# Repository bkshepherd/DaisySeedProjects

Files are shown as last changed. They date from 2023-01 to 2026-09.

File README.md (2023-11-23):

# Daisy Seed Projects
This is a demo of a pedal board I put together using 3 of my custom Daisy Seed based guitar pedals. I designed and built the hardware and programmed the software. Everything shown here is open source and all the code, pcb files, and basic instructions on how to build the pedals, can be found on these pages.

Demo Video (https://www.youtube.com/watch?v=ZkLnS43acQo)

## Software Projects:
### 1. [Guitar Multi-Effect Pedal](Software/GuitarPedal/README.md)
The software that can run on any of the custom Guitar Pedal hardware projects listed below as well at the PedalPCB Terrarium hardware.  This software is a flexible platform that abstracts the underlying Guitar Pedal hardware and allows a collection of Effects Modules to run on any of those hardware platforms.

## Hardware Projects:

I provide everything you need to build any of pedals you see below along with pretty detailed documentation.  However, recently I started to get a lot of requests to buy kits or finished pedals based on my designs. This is not something I typically do, but sometimes I do have extra PCBs, parts, and enclosures lying around and I'm willing to pass them along to you, basically at cost. I've included some ordering details along with each design below.

### 1. [Guitar Effect Pedal in 125b Enclosure](Hardware/GuitarPedal125b/README.md) (SMD Parts)
A feature rich and flexible platform for making DSP based guitar FX pedals. Stereo Audio, Midi in/out, OLED Display, Rotary Encoder for Menu Navigation, 6 Knobs, 2 LEDs, 2 Foot Switches, Relay based "True Bypass" switching, all based on the Daisy Seed microcontroller.

[Ordering Information](Hardware/GuitarPedal125b/docs/OrderingHardware.md)

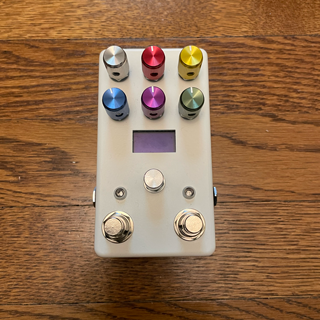
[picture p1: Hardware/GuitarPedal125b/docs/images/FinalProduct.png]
FinalProduct125b
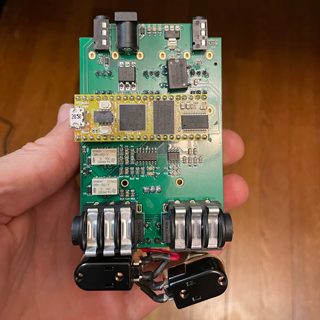
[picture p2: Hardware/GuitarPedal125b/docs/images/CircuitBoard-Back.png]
CircuitBoard125b
 

### 2. [Guitar Effect Pedal in 1590b Enclosure](Hardware/GuitarPedal1590b-SMD/README.md) (SMD Parts)

A robust and tiny platform for making DSP based guitar FX pedals. Stereo Audio, Midi in/out, 4 Knobs, 2 LEDs, 1 or 2 Foot Switches, Relay based "True Bypass" switching, all based on the Daisy Seed microcontroller. Using SMD parts for easy manufacturing by a fab such as JLCPCB.

[Ordering Information](Hardware/GuitarPedal1590b-SMD/docs/OrderingHardware.md)

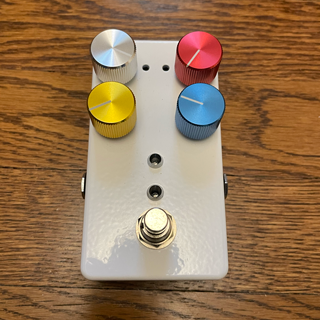
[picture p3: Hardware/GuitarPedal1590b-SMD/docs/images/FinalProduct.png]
FinalProduct1590b-SMD
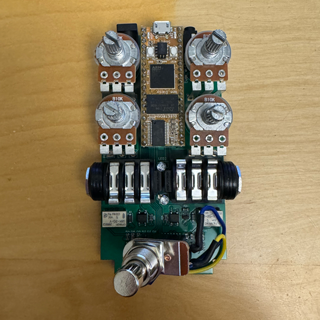
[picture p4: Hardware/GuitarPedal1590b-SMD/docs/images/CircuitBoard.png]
CircuitBoard1590b-SMD
 

### 3. [Guitar Effect Pedal in 1590b Enclosure](Hardware/GuitarPedal1590b/README.md) (Through-hole parts)

Same form factor and features as the SMD version of the 1590b pedal, minus the Relay based "True Bypass" switching. Using all Through-Hole parts for easy assembly at home with limited soldering skills.

[Ordering Information](Hardware/GuitarPedal1590b/docs/OrderingHardware.md)

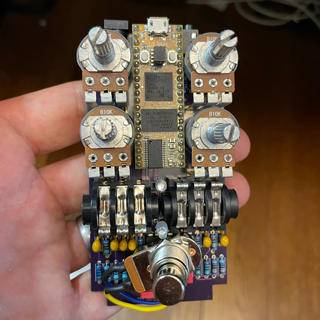
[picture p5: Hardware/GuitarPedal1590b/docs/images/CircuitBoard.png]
CircuitBoard1590b
FinalProduct1590b 

More Information about the Daisy Seed can be found at:

http://electro-smith.com

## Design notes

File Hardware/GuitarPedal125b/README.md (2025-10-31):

# Guitar Pedal 125b

### Rev 6 - 3/17/2024

Updates include:
1. Removed the PDS1 DC-DC Isolator from the power supply design.  This part was quite expensive and hard to source and wasn't really doing anything valuable to help with the noise profile of the device (especially if you are using a good pedal board power source with isolated power).  This simplifies the power supply a bit.  
2. Added a simple RC Low Pass filter immediately following the Daisy Seed audio outputs to help get rid of out of band noise caused by the Rev7 Daisy Seed.
3. Updated a bunch of components to have footprints oriented the way JLCPCB expects them.  This reduces the need to "fix" the rotation of components when having JCLPCB manufacture the PCBs.
4. Updated the design to include the 20pin headers for the Daisy Seed so that JLCPCB could also assemble these parts.  Saves a lot of time from having to solder 40 points on the PCB.
5. Updated the design to use more commonly available and cheaper Alpha brand 9mm Pots.
6. Included exported Gerber and Assembly files to make it easy to order assembled PCBs from JCLPCB. Detailed instructions can be found on the [Build the Hardware](docs/README.md) page. This requires no knowledge of KiCad to get the PCBs made and mostly Assembled.

### Overview

A project to create a digital effect pedal based on the Electro-Smith Daisy Seed that fits into a standard 125B sized Guitar Pedal enclosure. The video below shows a pedal board I made using 2 of these 125b sided pedals and demo the capabilities.

Demo Video (https://www.youtube.com/watch?v=ZkLnS43acQo)

This project is an evolution of my [1590B sized Pedal](https://github.com/bkshepherd/DaisySeedProjects/tree/main/Hardware/GuitarPedal1590b).

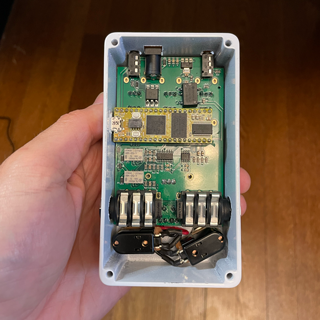
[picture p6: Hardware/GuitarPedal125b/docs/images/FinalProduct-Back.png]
FinalProductBack
FinalProduct 
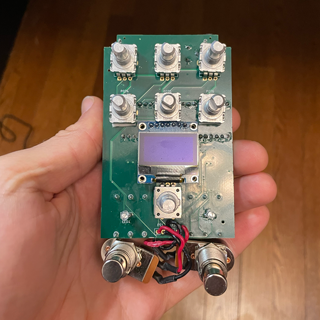
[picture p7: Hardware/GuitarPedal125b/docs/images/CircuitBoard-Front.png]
CircuitBoard
 CircuitBoard
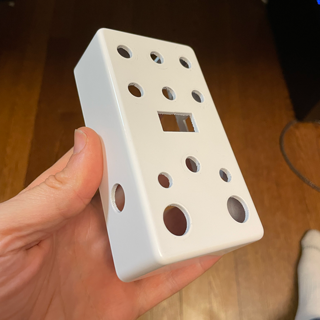
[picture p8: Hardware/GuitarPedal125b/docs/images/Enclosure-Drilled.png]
Enclosure
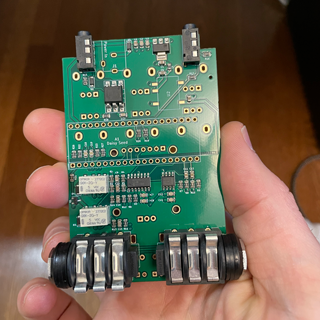
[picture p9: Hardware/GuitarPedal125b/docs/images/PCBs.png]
PCBs
 

### Features

1. 125B size pedal board friendly enclosure!
2. Buffered Stereo Input and Outputs for Guitar Level signals
2. Relay based "True Bypass" switching
3. TRS Mini MIDI Input and Outputs
4. OLED Display
5. Rotary Encoder for Display Navigation
6. 6 Pots
7. Up to 2 Footswitches
8. Up to 2 Leds
9. Standard 9v center pin negative power jack
10. Easy access to the Daisy Seed USB port and reset buttons for updating the firmware
11. Primarily SMD parts for easy assembly by your PCB provider
12. Easily order a custom drilled enclosure from Tayda! [Template Here](https://drill.taydakits.com/box-designs/new?public_key=MlRHaUhqaEVXOVVFZ1ErV1FiTXlrQT09Cg==)
13. Easily order or 3D print the enclosure using provided STEP and FreeCAD files.

This project includes a KiCad project with the necessary schematics and PCB layout files to create everything you need to build the hardware. The included exported Gerber and Assembly files make it easy to order PCBs from JCLPCB. Detailed instructions can be found on the [Build the Hardware](docs/README.md) page. This requires no knowledge of KiCad to get the PCBs made.

Once you've built the hardware you can deploy the software from my Multi-Effect Guitar Pedal software project by following these directions: [Deploy the Software to the Hardware](../../Software/GuitarPedal/README.md)

This software provides a hardware abstraction layer as well as a few custom FX including Tremolo, Chorus, Overdrive, and Stereo Auto-Pan.

## Past Updates
### Rev 5 - 6/30/2023

Updates include:
1. Updated placement of screen slightly to ease installation.
2. Updated POT footprint mounting holes to be slightly larger.
3. Properly grounded Audio TRS jacks when no cable is inserted.
4. Included exported Gerber and Assembly files to make it easy to order assembled PCBs from JCLPCB. Detailed instructions can be found on the [Build the Hardware](docs/README.md) page. This requires no knowledge of KiCad to get the PCBs made and mostly Assembled.

### Rev 4 - 5/16/2023

Updates include:
1. Updated PCB design to improve the True Bypass relay switching to include an anti-pop hardware mute.
2. Update Example Software to take advantage of the anti-pop mute.
3. Update Example Software to provide a basic menu system for the OLED Screen

### Rev 3 - 4/14/2023

Updates include:
1. Swapped the placement of the Footswitches and LEDs on the PCB to be consistent with my other pedals.

Known Issues:
1. Relay bypass has an audible pop when enabling / disabling the effect. Sounds like a common issue with relay and 3pdt switch true bypass systems.  Investigating fixing / minimizing it with an a solution similar to this [anti-pop system](https://www.coda-effects.com/2016/08/relay-bypass-with-anti-pop-system.html). Hope to add this in Rev 4.

### Rev 2 - 3/29/2023

Updates include:
1. Added 3 Additional Pots (Total of 6)
2. Improved OLED Screen Placement
3. Removed an Encoder (now just 1)
4. Tayda Custom Drill Template for easily ordering a pre-drilled enclosure

More Information about the Daisy Seed can be found at:

http://electro-smith.com

More Information about KiCad can be found at:

https://www.kicad.org

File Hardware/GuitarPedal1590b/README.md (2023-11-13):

# Guitar Pedal 1590b - Through-Hole Parts

### Rev 6 - 11/12/2023

Updates include:
1. Updated the PCB to have an optional bypass of the PDS1 5v Isolation circuit.

### Overview

A project to create a digital effect pedal based on the Electro-Smith Daisy Seed that fits into a standard 1590B sized Guitar Pedal enclosure. Electro-Smith sells a guitar pedal, but it's a much larger format, and I wanted something as small as possible.  The PedalPCB Terrarium was another option, but it's mono only, so I decided to build my own. This one is a smaller form factor than both, operates in Mono or Stereo, and has Midi support, so it's capable little pedal platform.

The video below shows a pedal board I made using this design, the smaller pedal on the far left, along with 2 of my [125B sized pedals](../GuitarPedal125b/README.md).

Demo Video (https://www.youtube.com/watch?v=ZkLnS43acQo)

This project is the Through-Hole parts version of my 1590b pedal. All parts are through-hole components and can easily be hand soldered. There is also a version of this same pedal where all parts are SMD parts that can be assembled by a fab such as JLCPCB, if you are looking for that, please check out my [Guitar Pedal 1590b-SMD project](../GuitarPedal1590b-SMD/README.md).

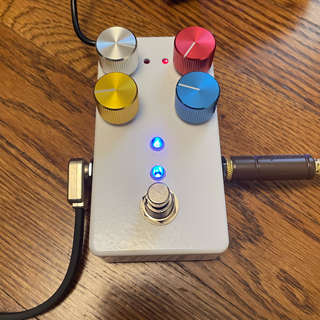
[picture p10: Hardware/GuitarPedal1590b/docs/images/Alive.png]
Backside
FinalProduct 

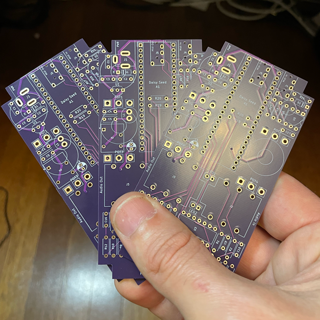
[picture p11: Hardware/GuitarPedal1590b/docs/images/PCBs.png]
PCBs
CircuitBoard 

### Features

1. Small 1590B pedal board friendly enclosure!
2. Buffered Stereo Input and Outputs for Guitar Level signals
3. TRS Mini MIDI Input and Outputs
4. 4 Pots
5. Up to 2 Foot Switches
6. Up to 2 Leds
7. Standard 9v center pin negative power jack
8. Easily Assembled from easily sourced through-hole parts, no SMD soldering required!
9. Easily order a custom drilled enclosure from Tayda!

This project includes a KiCad project with the necessary schematics and PCB layout files to create everything you need to build the hardware. The included exported Gerber and Assembly files make it easy to order PCBs from JCLPCB. Detailed instructions can be found on the [Build the Hardware](docs/README.md) page. This requires no knowledge of KiCad to get the PCBs made.

Once you've built the hardware you can deploy the software from my Multi-Effect Guitar Pedal software project by following these directions: [Deploy the Software to the Hardware](../../Software/GuitarPedal/README.md)

This software provides a hardware abstraction layer as well as a few custom FX including Tremolo, Chorus, Overdrive, and Stereo Auto-Pan.

## Past Revisions
### Rev 5 - 6/3/2023

Updates include:
1. Updated PCB to properly ground input / output jacks when no plug is inserted
2. Fixed a software issue causing noise from the LED.
3. Included exported Gerber files to make it easy to order PCBs from JCLPCB. Detailed instructions can be found on the [Build the Hardware](docs/README.md) page. This requires no knowledge of KiCad to get the PCBs made.
   
### Rev 4 - 4/12/2023

Updates include:
1. Updated PCB layout to move some components farther away from the edges
2. Swapped the placement of Footswitches and LEDs for consistency with my other projects 
3. Updated code to make Footswitch 1 & Led 1 enable / disabe the effect

### Rev 3 - 3/29/2023

Updates include:
1. Improved 4 Layer PCB Layout, much easier to assemble!
2. Replaced all SMD parts with through-hole alternative
3. Tayda Custom Drill Template for easily ordering a pre-drilled enclosure

More Information about the Daisy Seed can be found at:

http://electro-smith.com

More Information about KiCad can be found at:

https://www.kicad.org

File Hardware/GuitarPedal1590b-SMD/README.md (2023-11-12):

# Guitar Pedal 1590b using SMD Parts

### Rev 2 - 11/3/2023

Updates include:
1. Updated PCB to include the hardware mute
2. Included exported Gerber files to make it easy to order PCBs from JCLPCB. Detailed instructions can be found on the [Build the Hardware](docs/README.md) page. This requires no knowledge of KiCad to get the PCBs made.

### Overview

A project to create a digital effect pedal based on the Electro-Smith Daisy Seed that fits into a standard 1590B sized Guitar Pedal enclosure. The video below shows a pedal board I made using this design, the smaller pedal on the far left, along with 2 of my [125B pedals](../GuitarPedal125b/README.md).

Demo Video (https://www.youtube.com/watch?v=ZkLnS43acQo)

This project is the SMD parts version of my [1590b pedal](../GuitarPedal1590b/README.md). Features are the same as the Through-Hole version with the addition of "True Bypass". The majority of all parts can be pre-assembled on the PCB by a fab like JLCPCB. If you'd prefer a design where all parts are through-hole components, please check out the through-hole version of this project [Guitar Pedal 1590 project](../GuitarPedal1590b/README.md).

FinalProduct Backside

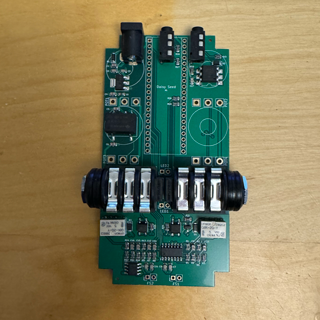
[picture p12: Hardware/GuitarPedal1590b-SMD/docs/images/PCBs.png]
PCBs
CircuitBoard 

### Features

1. Small 1590B pedal board friendly enclosure!
2. Buffered Stereo Input and Outputs for Guitar Level signals
3. TRS Mini MIDI Input and Outputs
4. 4 Pots
5. Up to 2 Foot Switches
6. Up to 2 Leds
7. Standard 9v center pin negative power jack
8. Setup for Easy Manufacturing with JLCPCB.  Minimal soldering required!
9. Easily order a custom drilled enclosure from [Tayda](https://drill.taydakits.com/box-designs/new?public_key=YWRhVFFGU0Z2c3RJR09VQ1U4S3EvUT09Cg==)

This project includes a KiCad project with the necessary schematics and PCB layout files to create everything you need to build the hardware. The included exported Gerber and Assembly files make it easy to order PCBs from JCLPCB. Detailed instructions can be found on the [Build the Hardware](docs/README.md) page. This requires no knowledge of KiCad to get the PCBs made.

Once you've built the hardware you can deploy the software from my Multi-Effect Guitar Pedal software project by following these directions: [Deploy the Software to the Hardware](../../Software/GuitarPedal/README.md)

This software provides a hardware abstraction layer as well as a few custom FX including Tremolo, Chorus, Overdrive, and Stereo Auto-Pan.

## Past Updates
### Rev 1 - Early 2023

Updates include:
1. Original Design Revision

More Information about the Daisy Seed can be found at:

http://electro-smith.com

More Information about KiCad can be found at:

https://www.kicad.org

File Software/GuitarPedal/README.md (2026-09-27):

# Multi-Effect Guitar Pedal Software

This directory includes all the source code for my Multi-Effect Guitar Pedal that runs on various hardware platforms.

For assembly and day-to-day operation of the 125B version, see the [125B user manual](USER_MANUAL_125B.md).

## Getting Started

Before you can use the software you'll need to do the following steps. There is an option [down below](#using-pre-compiled-releases) to skip setup of a development environment and use a pre-compiled .bin file, however this means you can't make any changes which can be limiting! It is recommended to try to setup your local development environment first.

### 1. Setup your Development Environment

The code in this project is supplied with a Microsoft Visual Code project and depends on both **LibDaisy** and **DaisySP** from Electro-Smith. Detailed instructions on setting these up for your dev environment can be found here:

https://electro-smith.github.io/libDaisy/index.html

Some issues have been reported with newer ARM compiler versions. The documentation above from Electrosmith should be complete but for reference many users have had success with `10.3-2021.10`

Version can be checked with `arm-none-eabi-gcc --version`

### 2. Setup dependencies

Check to make sure that the following directories have files in them:

1. `Software/GuitarPedal/dependencies/libDaisy`
1. `Software/GuitarPedal/dependencies/DaisySP`
1. `Software/GuitarPedal/dependencies/q/q`
1. `Software/GuitarPedal/dependencies/q/infra`
1. `Software/GuitarPedal/dependencies/gcem`

If they do not have anything in them, you may need to do a `git submodule update --init --recursive`.

Once those directories exist and have files in them, you should build libDaisy, DaisySP, and CloudSeed. This can be done with the following command:

1. From `Software/GuitarPedal` directiory: `./ci/build_libs.sh`

If this doesn't work, you can do it manually:

1. `cd libDaisy`
1. `make clean && make -j4`
1. `cd ..`
1. `cd DaisySP`
1. `make clean && make -j4`
1. `cd ..`
1. `cd CloudSeed`
1. `make clean && make -j4`

#### Additional information for this step:

- Note - You may not need to do all parts of this step if the project pulled down from GitHub with the dependencies already included as sub-modules. The desktop GUI client always should pull down submodules. If it still doesn't pull down and you have libDaisy and DaisySP installed somehwere else, you can follow the steps below, (note that you will still need to setup cycfi/q and cycfi/infra dependencies separately so the submodule way should be preferred):

  - You'll need to update the paths in the **Makefile**.
  - You'll also need to update the paths in the **c_cpp_properties.json** file in the **.vscode/** folder.
  - You'll also need to update the paths in the **task.json** file in the **.vscode/** folder.

### 3. Configure your specific Target Hardware

You'll need to open the guitar_pedal.cpp file and uncomment a line to configure which hardware you are targetting. If you don't do this, it will build for the 125B variant.

In guitar_pedal.cpp:

```cpp
// Uncomment the version you are trying to use, by default (and if nothing is
// uncommented), the 125B with 2 footswitch variant will be used

// #define VARIANT_125B
// #define VARIANT_1590B
// #define VARIANT_1590B_SMD
// #define VARIANT_TERRARIUM
// #define VARIANT_FUNBOX
```

If you want to target the GuitarPedal125B hardware change the lines to:

```cpp
#define VARIANT_125B
// #define VARIANT_1590B
// #define VARIANT_1590B_SMD
// #define VARIANT_TERRARIUM
// #define VARIANT_FUNBOX
```

If you want to target the GuitarPedal1590B hardware change the lines to:

```cpp
// #define VARIANT_125B
#define VARIANT_1590B
// #define VARIANT_1590B_SMD
// #define VARIANT_TERRARIUM
// #define VARIANT_FUNBOX
```

If you want to target the GuitarPedal1590B-SMD hardware change the lines to:

```cpp
// #define VARIANT_125B
// #define VARIANT_1590B
#define VARIANT_1590B_SMD
// #define VARIANT_TERRARIUM
// #define VARIANT_FUNBOX
```

If you want to target the Pedal PCB hardware change the lines to:

```cpp
// #define VARIANT_125B
// #define VARIANT_1590B
// #define VARIANT_1590B_SMD
#define VARIANT_TERRARIUM
// #define VARIANT_FUNBOX
```

### 4. Build and Deploy the Code

By default this project is configured to use the custom Boot Loader. To get up and running you'll need to do the following:

1. Build the software with `make -j4`, confirm that `build/guitarpedal.bin` exists
1. Put your Daisy Seed into DFU mode.
1. From the terminal, in the GuitarPedal folder run "make program-boot"
1. Once this finishes installing the custom boot loader on the Daisy Seed, press the Reset button. The led will temporary blink for about 3 second.
1. While the LED is blinking run "make program-dfu"
1. That's it!
1. If you make code changes, you can simply run `make -j4` to rebuild them, and then rerun the previous 2 steps (reset button + `make program-dfu`)

If you run into trouble with the bootloader. Electro-Smith has better documentation on how to get it working here: https://github.com/electro-smith/libDaisy/blob/master/doc/md/_a7_Getting-Started-Daisy-Bootloader.md

If you want to use built in flash memory only, you _can_, but it severely limits which effects you can use and how many you can have installed at once. I'd recommend editing the list of active effects in the loaded_effects.h file to perhaps just 1 or 2. Then do the following to get running on internal flash:

1. Remove the "APP_TYPE = BOOT_SRAM" line from the Make File:
2. Put your Daisy Seed into DFU mode.
3. make build-and-program-dfu

### 5. Connect your Guitar and Amp

Plug your guitar into the Input and connect the Output to your amp.

### 6. Enjoy!!!

## Optional: Dattorro plate reverb (GPLv3)

`Effect-Modules/Dattorro/` contains a Dattorro (1997) plate reverb, in the same family used by
the Hothouse "Flick" and "MuleBox" pedals. It's disabled by default and commented out of both the
`Makefile` and `loaded_effects.h`, because that code is licensed **GPL-3.0-or-later**, not MIT
like the rest of this repository — see [`Effect-Modules/Dattorro/README.md`](Effect-Modules/Dattorro/README.md)
for the full provenance chain and license text. Enabling it means the firmware binary you build
must be distributed under GPLv3 (or not distributed at all); leaving it commented out keeps your
build entirely MIT.

To opt in:

1. Uncomment the two `Dattorro` lines in the `Makefile`.
2. Uncomment the `#include` and `new DattorroReverbModule(),` lines in `loaded_effects.h`.
3. Rebuild and flash.

## Combining Effects (EffectChain)

`Effect-Modules/effect_chain.h` lets you wire two or more effects into a single chained entry in
`loaded_effects.h`, processed serially (e.g. tremolo into reverb), without changing any of the
effect modules themselves or the menu/UI code. For example:

```cpp
new EffectChain(
    "Trem+Verb",
    // Slots: a short menu tag plus the child effect instance (owned by the chain).
    {{"Tr", new ModulatedTremoloModule()}, {"Rv", new ReverbModule()}},
    // Knob/MIDI CC mappings: {slot, child param id, knob (-1 = none), midi CC (-1 = none)}.
    {{0, ModulatedTremoloModule::DEPTH, 0, 20},
     {0, ModulatedTremoloModule::FREQ, 1, 21},
     {1, ReverbModule::TIME, 2, 22},
     {1, ReverbModule::DAMP, 3, 23},
     {1, ReverbModule::MIX, 4, 24}}),
```

Every child parameter shows up in the effect's parameter menu, tagged with its slot's prefix (e.g.
"Tr Depth", "Rv Mix") so identically-named parameters from different children stay distinct; only
the parameters listed in the mapping array are reachable from a knob and/or MIDI CC. One slot (the
first, by default) is the "primary" child, which owns the LED and the alternate footswitch.

Every slot also gets its own "\<tag\> On" checkbox in the menu, defaulting to on, so any slot can be
bypassed independently. This is saved with presets exactly like any other parameter.

By default the alternate footswitch just forwards to the primary child (e.g. for tap tempo).
Pass `footswitchTogglesSlots` to repurpose it as an on-off slot for one or more children, e.g.:

```cpp
new EffectChain(
    "HT+Dly+Rv",
    {{"Tr", new HarmonicTremoloModule()}, {"Dl", new DelayModule()}, {"Rv", new DattorroReverbModule()}},
    {{2, DattorroReverbModule::MIX,    0, 20},
     {0, HarmonicTremoloModule::DEPTH, 1, 21},
     {0, HarmonicTremoloModule::SPEED, 2, 22},
     {1, DelayModule::DELAY_TIME,      3, 23},
     {1, DelayModule::D_FEEDBACK,      4, 24},
     {1, DelayModule::DELAY_MIX,       5, 25}},
    /* primarySlot */ 1,
    /* footswitchTogglesSlots */ {0}), // or {0,1} to toggle trem+delay together
```

A `ChainMapping` can also target a slot's own "On" parameter instead of a child parameter, using the
`EffectChain::SLOT_ENABLE` sentinel (e.g. `{0, EffectChain::SLOT_ENABLE, -1, 30}`), which puts that
bypass on a MIDI CC regardless of whether the footswitch is also toggling it.

Turning a slot off crossfades it out over about a tenth of a second and then stops processing it
entirely, both to avoid a click and to save CPU. Note the delay/reverb trails are not preserved.

If you want to have more than six physical knobs, give any `ChainMapping` a `knobMapping` of 6 or
higher, and that parameter moves to a second knob bank instead of being unreachable: holding the alternate
footswitch for a second toggles between the two banks (an on-screen "SHIFT" label shows when the
second bank is active), and holding it again switches back. Physical knob 1 reads whatever's mapped
to knob 0 normally, and whatever's mapped to knob 6 while shifted; knob 2 maps to 1/7, and so on
through knob 6 mapping to 5/11. This only kicks in when a chain actually uses a `knobMapping` of 6 or
higher somewhere — with every mapping in 0-5, holding the footswitch keeps forwarding to the primary
child (or stays a no-op under `footswitchTogglesSlots`) exactly as before:

```cpp
new EffectChain(
    "HT+Dly+Rv",
    {{"Tr", new HarmonicTremoloModule()}, {"Dl", new DelayModule()}, {"Rv", new DattorroReverbModule()}},
    {{2, DattorroReverbModule::MIX,       0, 20},
     {0, HarmonicTremoloModule::DEPTH,    1, 21},
     {0, HarmonicTremoloModule::SPEED,    2, 22},
     {1, DelayModule::DELAY_TIME,         3, 23},
     {1, DelayModule::D_FEEDBACK,         4, 24},
     {1, DelayModule::DELAY_MIX,          5, 25},
     // Shift bank - reachable by holding the alternate footswitch for 1s.
     {2, DattorroReverbModule::PRE_DELAY, 6, 26},
     {2, DattorroReverbModule::DECAY,     7, 27},
     {2, DattorroReverbModule::TONE,      8, 28},
     {2, DattorroReverbModule::DIFFUSE,   9, 29},
     {1, DelayModule::DELAY_LPF,          10, 30},
     {1, DelayModule::MOD_AMT,            11, 31}},
    /* primarySlot */ 1,
    /* footswitchTogglesSlots */ {0}),
```

This isn't meant to support every combination of effects — some modules need caution, or are a poor
fit for chaining altogether:

- **Single-instance-only modules.** Many modules that keep DSP buffers or other resources in a file-scope
  global, where every *instance* of that class aliases the same memory. In practice this means you can
  only create one instance. You can*use* the one instance more than once, e.g. in more than one effect
  chain or in a combination of an effect chain and a standalone effect, but since they share their
  parameters, any changes when viewing one patch affects all references.
  
  Modules in this category: `ReverbModule`, `DattorroReverbModule`, `DelayModule`, `TapeDelayModule`,
  `MultiDelayModule`, `GranularDelayModule`, `SpectralDelayModule`, `SciFiModule`,
  `PitchShifterModule`, `LooperModule`, `PluckEchoModule`, `NamA2Module`, `CloudSeedModule`,
  `TunerModule`.
- **Custom on-screen displays are lost.** A chain always draws its own generic name/parameter screen
  instead of forwarding to a child's `DrawUI`, so these modules lose some or all of their custom
  display when chained: `AutoPanModule`, `ChopperModule`, `DelayModule`, `GraphicEQModule`,
  `LooperModule`, `MetroModule`, `ParametricEQModule`, `PitchShifterModule`, `TapeDelayModule`,
  `TunerModule`. This doesn't stop them working, but it can be confusing.

### Sharing a single-instance effect between chains

A single-instance-only module (see above) can still show up in more than one chain, as long as
it's the same object every time. Construct it once, put it in every `ChainSlot` that wants it, and
mark every slot but one `ownsEffect = false` so only one of them deletes it:

```cpp
static DattorroReverbModule* reverb = new DattorroReverbModule();

new EffectChain("HarmTremVerb",    {{"HT", new HarmonicTremoloModule()}, {"Rv", reverb}}, ...),                    // owns it
new EffectChain("ModTremVerb", {{"Tr", new ModulatedTremoloModule()}, {"Rv", reverb, /* ownsEffect */ false}}, ...), // reuses it
```

The two chains are then processing the exact same reverb - its parameters are shared state, not a
copy per chain. Switching between the chains never resets or overwrites the other's settings by
itself; only turning that shared knob, editing it in the menu, or a MIDI CC actually changes it. The
one gap is at power-on: every chain restores its own saved values into whatever it maps parameters
to, so whichever chain happens to come later in `effectList` decides the shared effect's values after
a reboot - not necessarily the chain you had active when you last powered off.

## Using pre-compiled releases

1. Download the .zip for the hardware variant you have built from the latest release https://github.com/bkshepherd/DaisySeedProjects/releases
1. Unzip it so that you have a guitarpedal.bin
1. Open https://flash.daisy.audio/ in a supported web browser
   1. Flash the bootloader (instructions on the Bootloader tab of the web flashing tool)
      - This step can be skipped if the bootloader has already been flashed
   1. Flash the firmware .bin file (and repeat these steps for changing firmware versions)
      1. Press RESET button on the daisy
      1. Within 5 seconds single press the BOOT button on the daisy (this locks it into bootloader mode so that you can take your time to do the following steps instead of trying to do it all within 5 seconds)
      1. Use File Upload to select the .bin file
      1. Press Flash

## Software Updates

### Software Update - September 2026

1. Added distortion, granular delay, drum machine, IR loader, tape delay, phaser, flanger, crusher, harmonic tremolo, and dual echo (aka "halo") effects.
2. Added NAM A2 support, optional IR loading, and a default set of amp models.
3. Added effect chains with per-effect bypass, expanded knob banks, and footswitch/MIDI mapping.
4. Added optional GPL-3.0 Dattorro plate reverb and basic Funbox hardware support.
5. Improved pitch shifting, delay controls and preset storage.
6. Fixed a memory leak when switching effects and improved memory use.
7. Added an "autosave" option, whereby the most recent pedal state will be saved across restarts (note: this overwrites Preset 0 for each effect a few seconds after every parameter change).

### Software Update - November 2024

1. New Effect Modules:
   - Compressor
   - Chromatic Tuner
   - Looper
   - Pitch Shifter (similar to digitech drop/ricochet)
2. Fixes to tap tempo across several effects
3. Quick-switch to tuner by press-and-hold bypass switch
4. Allow effects to utilize alternate footswitch (looper, pitch shifter)
5. Adjusts saving to require both footswitches to be held if the hw has 2 footswitches
6. Updated to C++20, updated dependencies, added code formatting with clang-format
7. Added a compile-time boolean flag if hardware only has 1 footswitch
8. Adjusted bypass logic to try and mitigate double activations

### Software Update - February 2024

Big update to the handling of Persistant Storage. Thank you @jaching!

Updates include:

1. Removed the hard limit the number of parameters stored per EffectModule.
2. Ability to have multiple stored Presets for each EffectModule
3. Reset All Presets button now located in the Preset Menu
4. Changing Midi to call custom callback when a midi cc cannot be found.
5. Added a NEW Multi tap delay Effect Module!
6. The software is now configured to use the Boot Loader by default to allow for more memory usage.

### Software Update - 11/11/2023

Updates include:

1. Refactored the code to move Display UI handling and Persistent Storage out of the main class file.
2. Added functionality to make it easy for an Effect Module to provide custom UI for the Display while the Effect is Active.

### Software Update - 10/9/2023

Updates Include:

1. Added support for multiple effects. Included are a simple tremolo, chorus, overdrive, and stereo auto-panning effects.
2. Created a Hardware Abstraction Layer allowing this software to run on different Daisy seed based hardware targets including my custom hardware as well as the Pedal PCB Terrarium.
3. Updated the menu system to support multiple effects each with their own settings and global hardware settings. Parameters can be updated directly through the menu UI or using the pots on the device.
4. All settings / parameters are now saved to the device memory and restored when the device powers up.
5. Added Midi support to make it simply to map effect parameters to Midi CC commands for controlling presets via midi.

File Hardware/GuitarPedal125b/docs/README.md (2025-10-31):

# Building the Hardware
Some quick instructions for how to make the GuitarPedal125B Hardware.  This document assumes you know the basics about soldering and circuit board assembly.  You'll also need to be fairly handy with a drill to mount the various knobs and switches on the enclosure (or you can order one pre-made from Tayda). Alternatively, you can order or 3D print the enclosure using provided 3D models.

Quick note, I couldn't include some of the custom footprints for specific components due to licenses that wouldn't allow redistribution.  Here is a list of where you can find some of them:

* Neutrik NMJ6HCD2 - https://www.snapeda.com/parts/NMJ6HCD2/Neutrik/view-part/

Also, I just want to acknowledge that the schematics for the circuits were kit bashed together from the following sources with some additions of my own:

* [Electro-Smith: Daisy Petal Rev 5 Schematics](https://github.com/electro-smith/Hardware/blob/master/reference/daisy_petal/ES_Daisy_Petal_Rev5.pdf)
* [Simple DIY Electronic Music Projects](https://diyelectromusic.wordpress.com/2022/08/29/3v3-midi-module-pcb/)

Getting everything into KiCad and the PCB layouts are all my own work.

The KiCad files are included for the full schematic and pcb board layout in the **pcb** folder.  You really don't need to know anything about KiCad to order the PCB and get it made, but they are there for reference.

I like to order my PCBs from https://www.jlcpcb.com, but anywhere should work fine.

Follow these steps to get the PCB made by JLCPCB:

## 1. Generate the Gerber & Drill Files

The first step is to use KiCad to export the Gerber & Drill files for production like this: [JLCPCB Gerber and Drill File Generation](https://jlcpcb.com/help/article/16-How-to-generate-Gerber-and-Drill-files-in-KiCad-6). You can also skip this part and simply use the ready-made [JLCPCB Gerber Files](../pcb/JLCPCB-Gerbers/DaisySeedPedal125b-Rev6-gerbers.zip) for this project. (Keep the files zipped)

## 2. Generate BOM and Centroid Files

To use SMT Assemble service from JLCPCB, which you will want to do, the BOM and centroid files need to be generated as well. [Follow these instructions provided by JLCPCB](https://jlcpcb.com/help/article/81-How-to-generate-the-BOM-and-Centroid-file-from-KiCAD). You can also skip this part and simply use the ready-made files for this project:

1. [JLCPCB BOM](../pcb/BOM_JLCSMT_DaisySeedGuitarPedal125b.xlsx)
2. [JLCPCB Centroid](../pcb/JLCPCB-Gerbers/DaisySeedPedal125b-top-pos.csv)

## 3. Pre-Order Parts for JLCPCB

There are a few parts that JLCPCB doesn't stock normally.  You can either pre-order these parts through JLCPCB so they can be assembled for you (recommended) of you can order the parts yourself and solder them yourself (advanced).

The main parts they don't typically stock are:

1. CPC1018 This one is usually stocked these days. Probably good to double check though. (JLCPCB Part #C133069 or #C1558973), or as a substitute CPC1019 (JLCPCB Part #C1854946 or #C2760117) Any of those work fine.

To order these parts through JLCPCB follow these instructions:

1. Visit the [JLCPCB Website](https://www.jlcpcb.com) and log into your account.
2. Go to the [Parts Manager Page](https://jlcpcb.com/user-center/smtPrivateLibrary/).
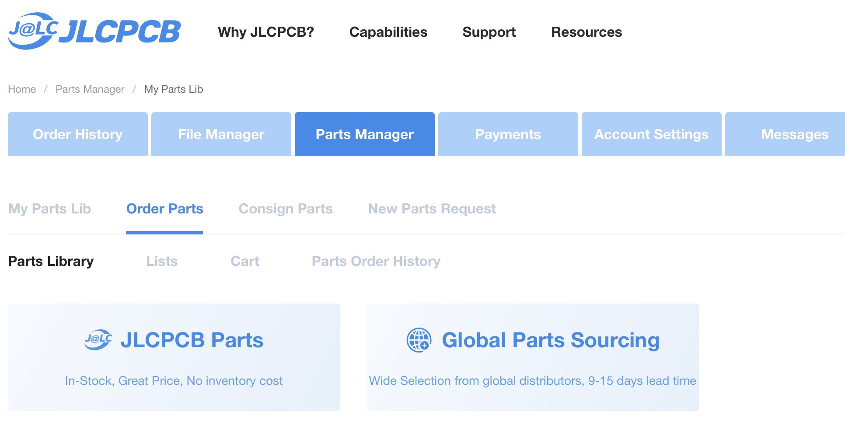
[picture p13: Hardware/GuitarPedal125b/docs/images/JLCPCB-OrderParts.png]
3. Click on Order Parts 
4. There are two options for ordering parts JLCPCB Parts and Global Parts Sourcing.  I always try to use JLCPCB Parts ordering first, but sometimes you have to use Global Parts Sourcing.
5. First try looking in JLCPCB Parts and search using the above JLCPCB Part #s.  If you can order it there, great, do so.
6. If you can't find it there (sometimes the prices are crazy high, or the min quantity is a huge number), then try Global Parts Sourcing. 
7. Search for the part by name in Global Part Sourcing.
5. Find a supplier that lets you order a small quantity and double check the part name to make sure it's the right part.
6. Order the appropriate number of parts.
7. Repeat this process for both parts. 

Please note, that it typically takes a week or two to get the parts ordered and into your parts library for use.  So I like to order these parts in batches enough to place a few orders. 

## 4. Order the Assembled PCBs from JLCPCB

1. Have the Gerber, Drill, BOM, and Centroid files handy. (Keep the files zipped)
2. Visit the [JLCPCB Website](https://www.jlcpcb.com).
3. Click the **Order Now** button in the top menu bar.
4. Click the **Add Gerber File** button.
  
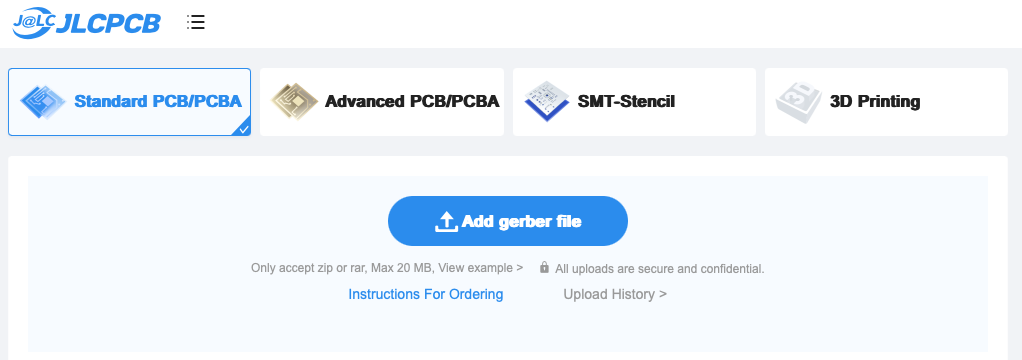
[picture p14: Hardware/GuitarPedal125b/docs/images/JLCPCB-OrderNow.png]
Add Gerbers

   
5. Upload the zipped Gerber files you downloaded above.
6. After processing the files it should provide a screen with various options. Most everything is fine by default, but you should use ENIG finishing options instead of HASL, you should check the Confirm Production File option and turn on PCB Assembly.

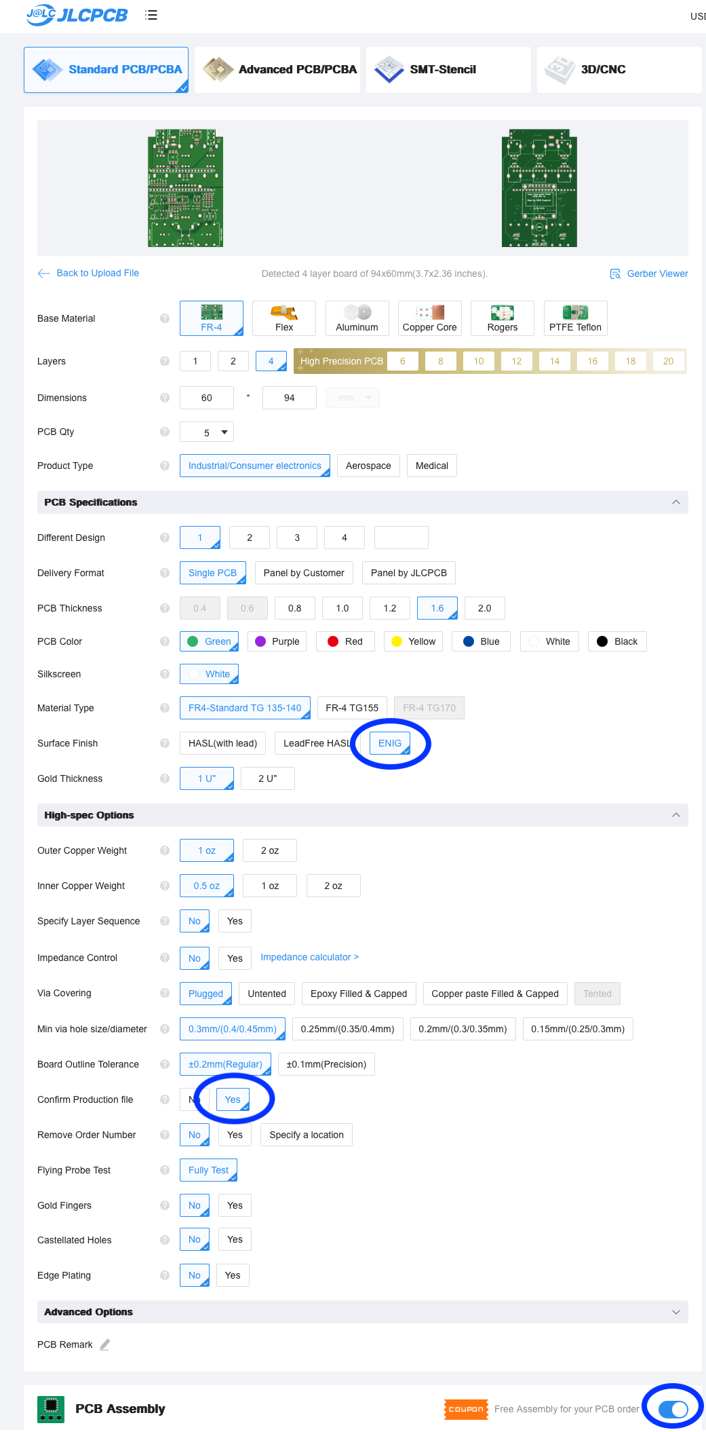
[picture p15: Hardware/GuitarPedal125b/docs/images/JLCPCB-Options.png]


7. Once you turn on PCB Assembly, you will need to confirm that you want the Top Side assembled and definitely select the Confirm Parts Placement option.

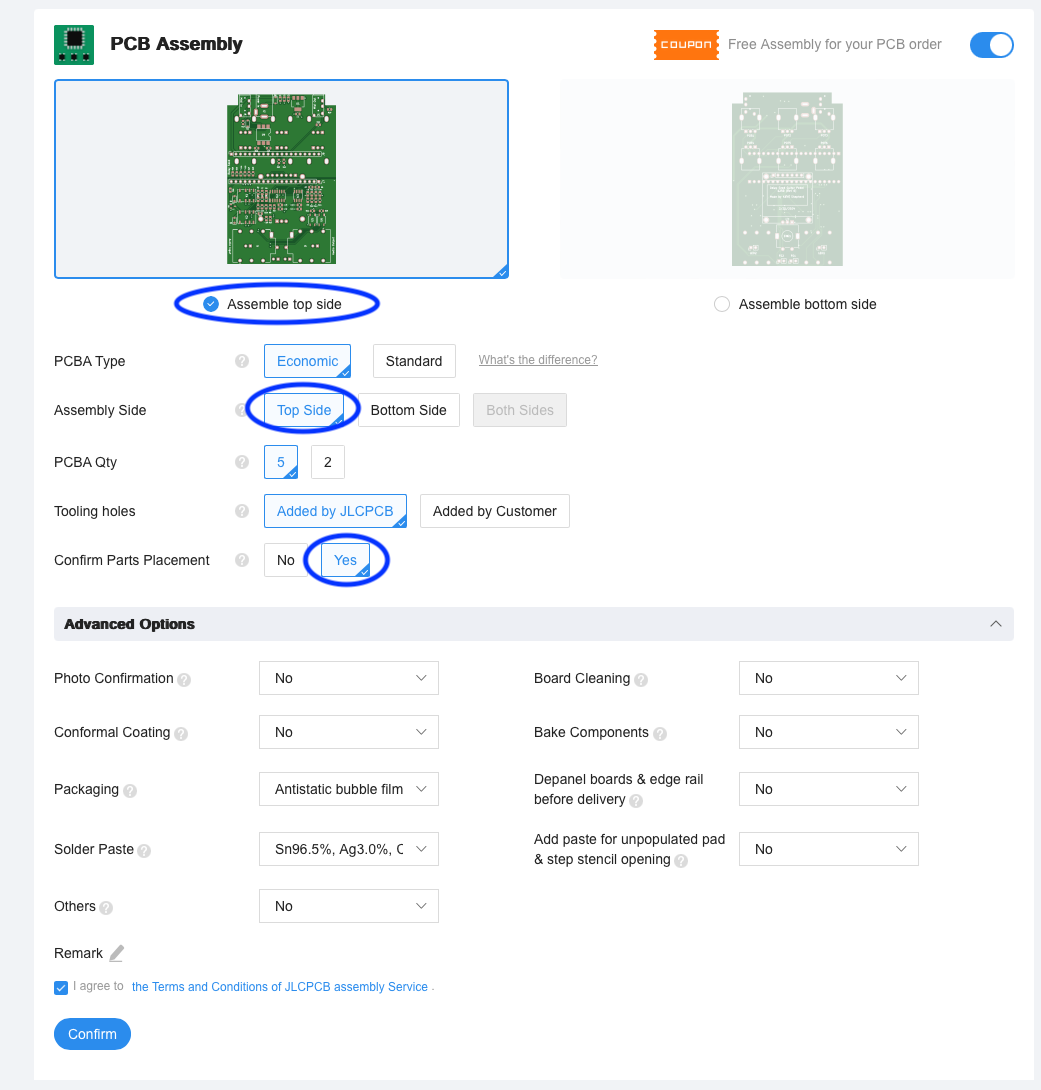
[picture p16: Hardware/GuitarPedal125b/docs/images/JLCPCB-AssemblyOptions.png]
PCB Assembly Options


8. Click the Confirm button on the PCB Assembly panel.
9. This page shows you the side being assembled. It should look like this.

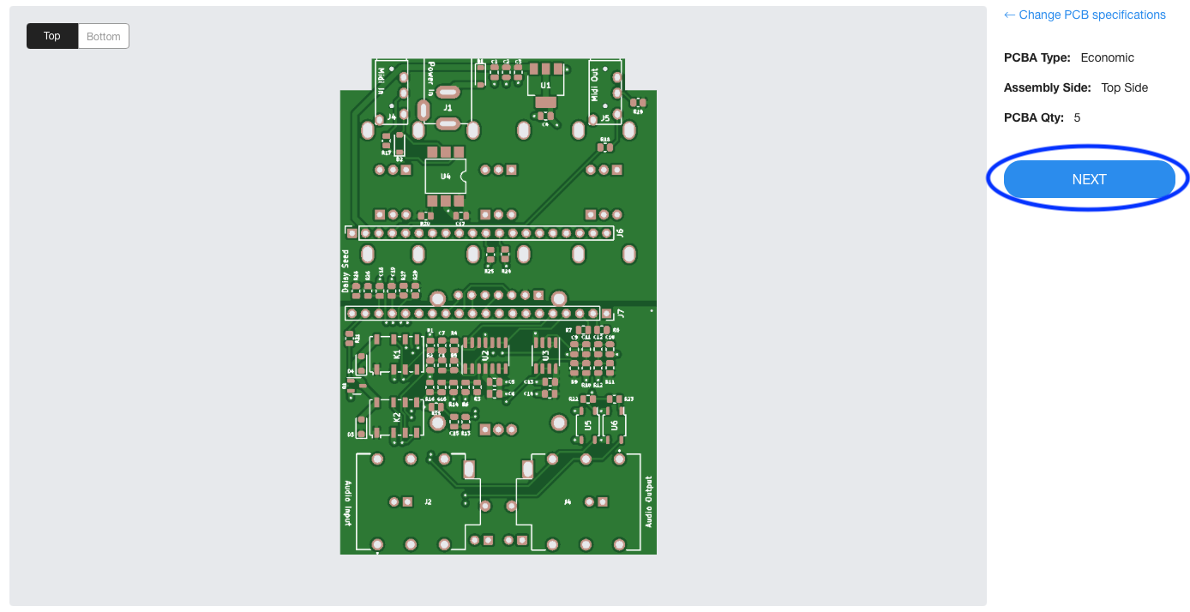
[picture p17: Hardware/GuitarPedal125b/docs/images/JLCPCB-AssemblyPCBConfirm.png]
PCB Assembly Confirm


Click Next.

10. Next you need to upload the BOM and Centroid File.

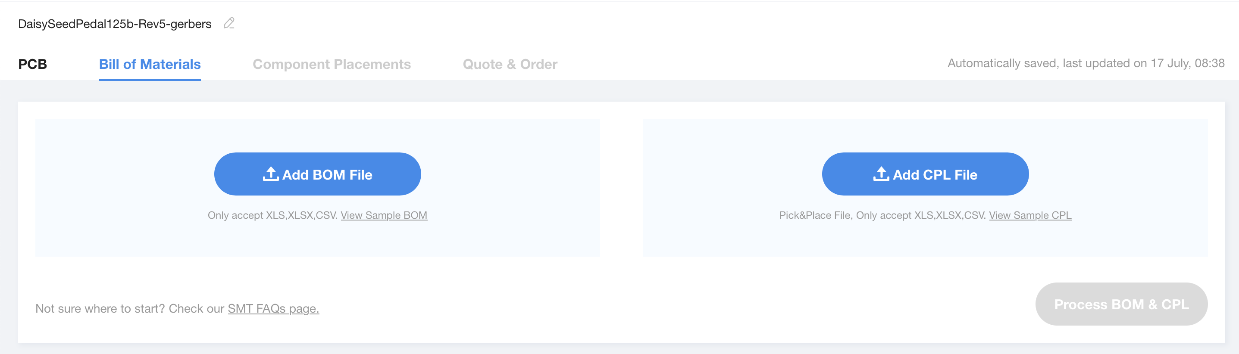
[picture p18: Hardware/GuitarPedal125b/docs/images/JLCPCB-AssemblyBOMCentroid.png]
PCB Assembly Options


11. Click Add BOM and upload the BOM file. Either the one you generated or the one you downloaded above [JLCPCB BOM](../pcb/BOM_JLCSMT_DaisySeedGuitarPedal125b.xlsx).
12. Click Add CPL and upload the Centroid file. Either the one you generated or the one you downloaded above [JLCPCB Centroid](../pcb/JLCPCB-Gerbers/DaisySeedPedal125b-top-pos.csv). 
13. After the files are uploaded click Process BOM and CPL.

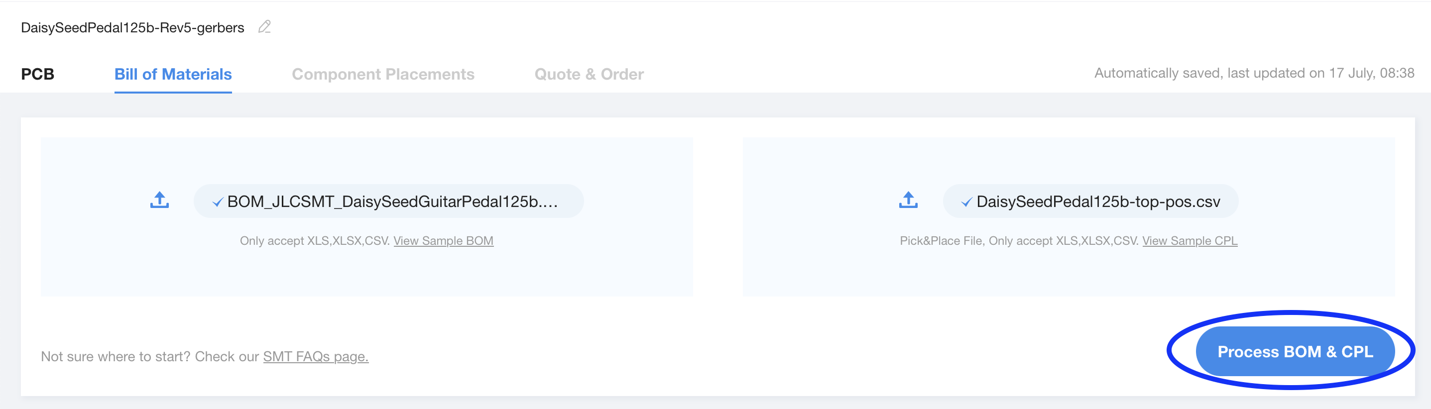
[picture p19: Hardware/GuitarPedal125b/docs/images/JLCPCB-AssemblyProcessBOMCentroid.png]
PCB Assembly Options


14. This page asks you to confirm the parts.  You should see at the top 28 Parts Detected and 28 Parts Confirmed.

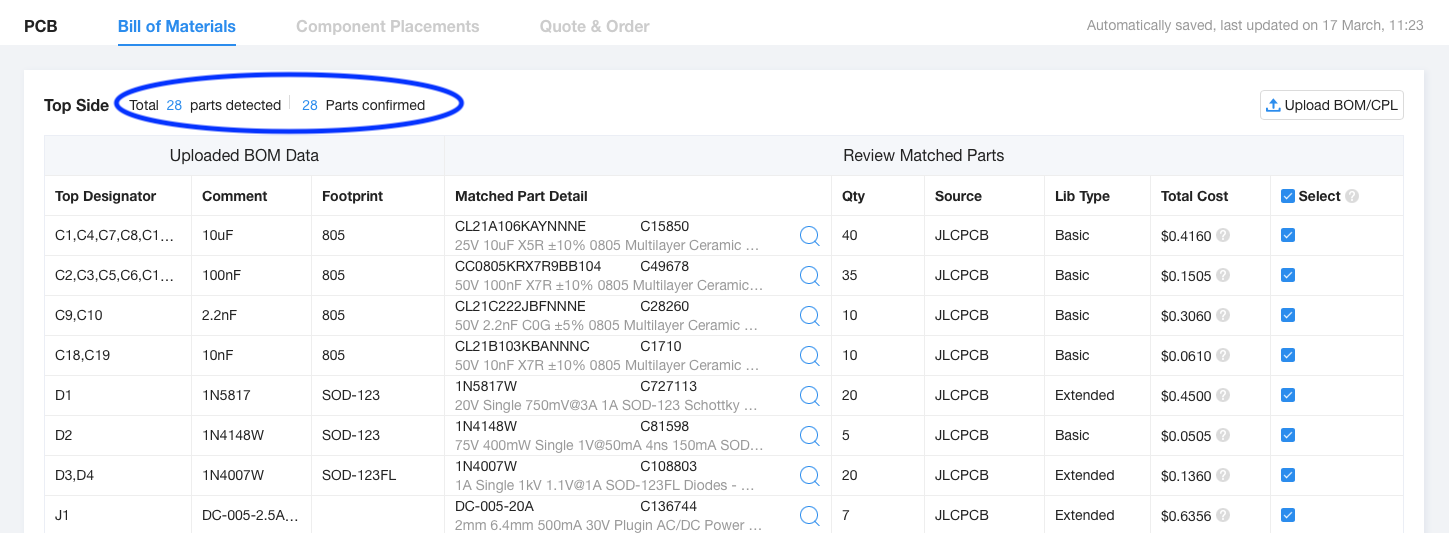
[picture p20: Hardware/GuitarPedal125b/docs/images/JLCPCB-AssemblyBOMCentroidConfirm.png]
PCB Assembly Options


If it tells you any parts are missing, you may need to substitute. For instance, the parts you ordered from global parts sourcing may have ended up with a different JLCPCB Part number than the ones in the supplied files.  If that is the case you can click on the part in the list and search for the proper part and replace it.  Repeat this process until all parts are accounted for.
15. Click Next.
16. This next page allows you to view the placement of the Components.  If you used the premade Gerbers and CPL files everything should be placed and rotated properly. If you generated your own, there may be some parts improperly rotated (this is due to differences in KiCad's footprint library and JLCPCB's library). You will have to manually fix them in this viewer. Simply click each part that is not properly placed, and use the buttons to rotate and move them until they are in place.

It should look like this when everything is placed properly.

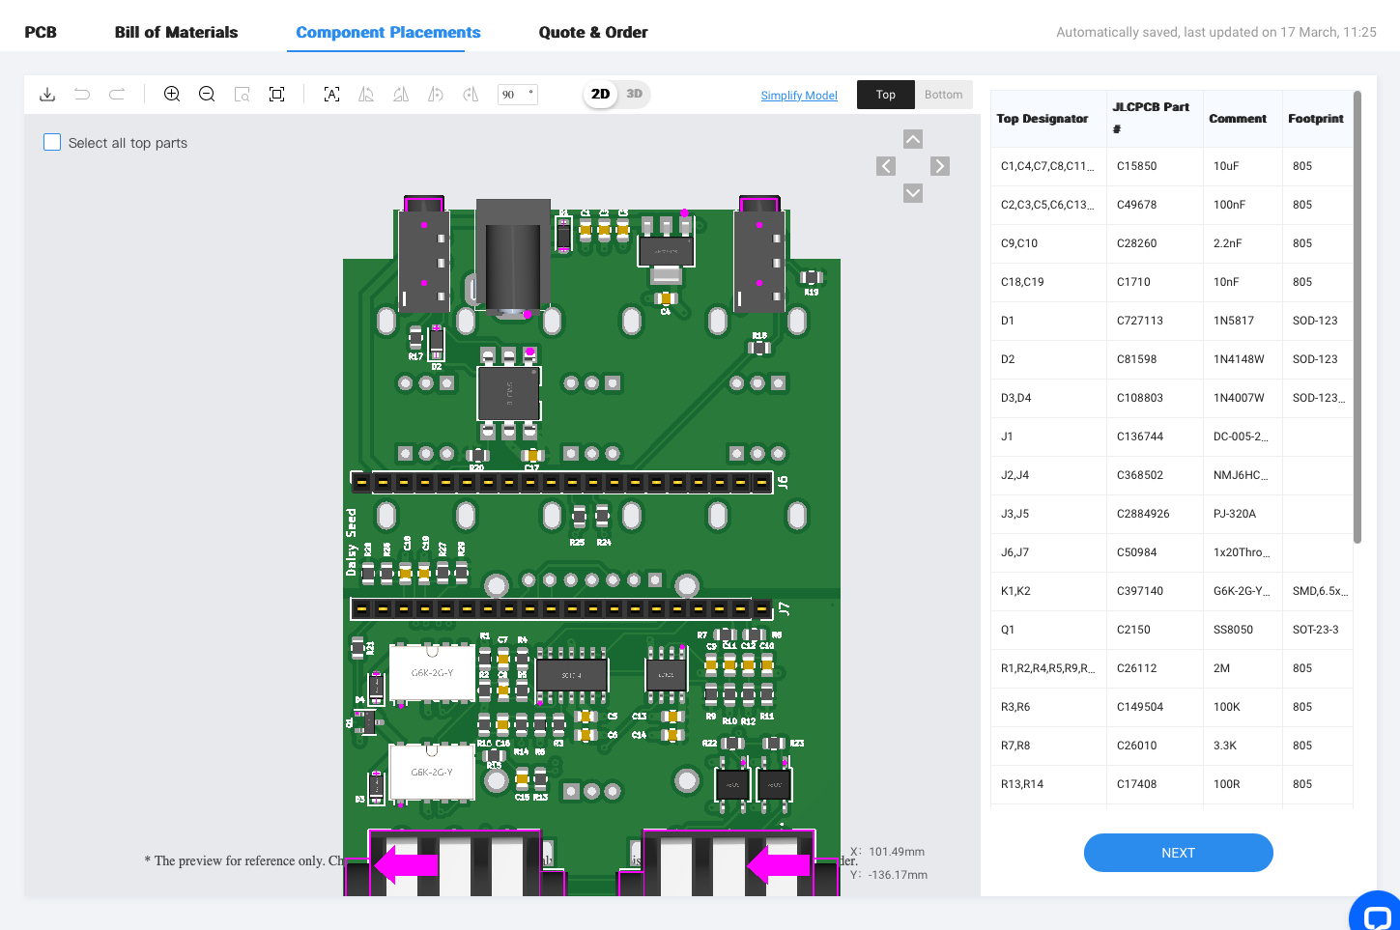
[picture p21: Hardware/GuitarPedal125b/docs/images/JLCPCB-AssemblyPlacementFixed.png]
PCB Assembly Options


17. Click Next.
18. Add the item to your cart, and order the PCB.

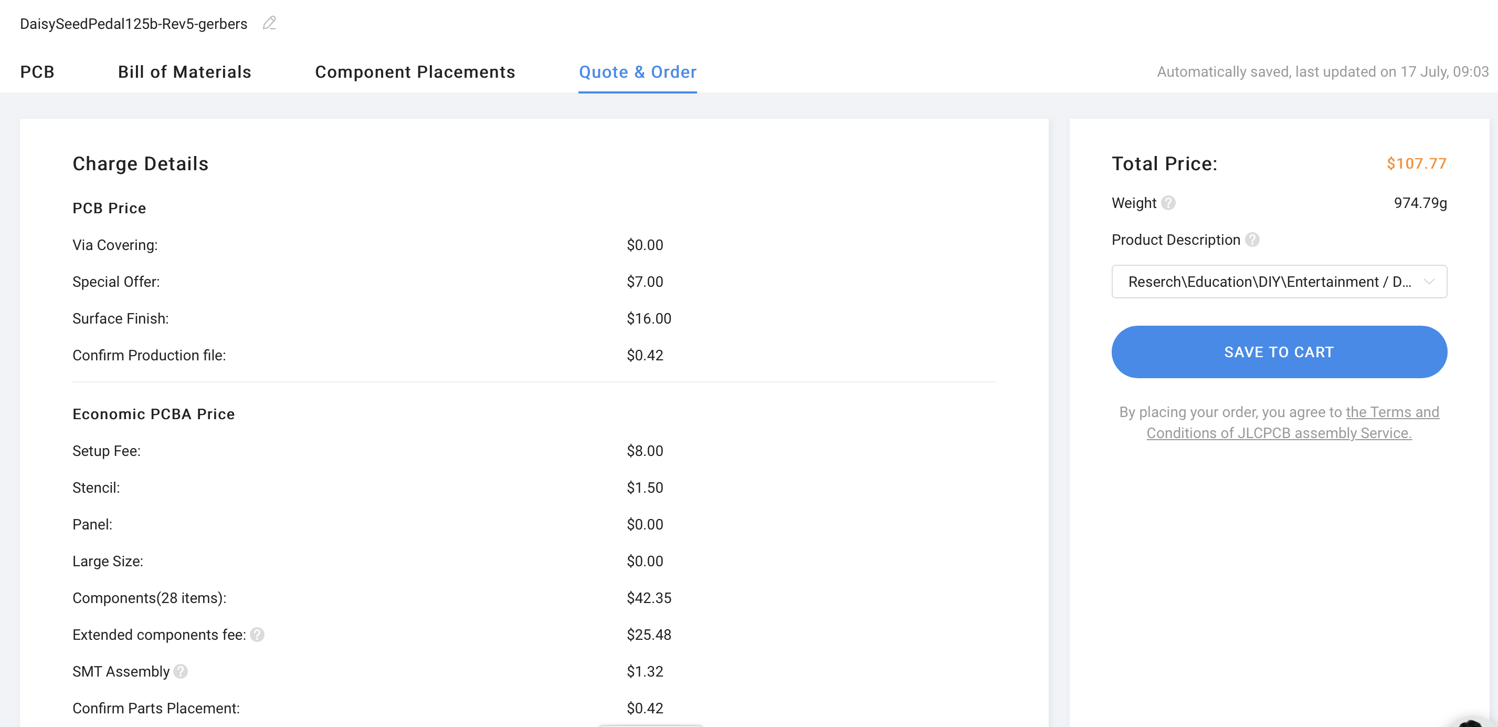
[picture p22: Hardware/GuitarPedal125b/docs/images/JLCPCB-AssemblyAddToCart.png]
PCB Assembly Options


They will give you a price for ordering 5 assembled pcbs (that's their minimum order).  Prices typically vary due to component costs, etc. So your prices may not matched this screenshot exactly, but it should be within the same ballpark. It will take a week or two for it arrive and they look like this (with slight variation, this picture is from a past revision):

PCBs

## 5. Order the Additional Parts JLCPCB doesn't Assemble

There are a few parts that you will need to order yourself and solder on the PCBs after you recieve them from JLCPCB.

Here is a list of the additional parts to order for the PCB:

1. 2 Headers 20-Pin Single Row (If you didn't have JLCPCB assemble them) for the Daisy Seed. I used these from [Amazon](https://www.amazon.com/dp/B09MYBZZKZ)
2. 6 Pots. These are the ones I used [Alpha RD901F-40-15R1-B10K](https://www.taydaelectronics.com/10k-ohm-linear-taper-potentiometer-round-shaft-pcb-9mm.html).
3. 1 Rotary Encoder. This is the one I used [PEC11R-4220K-S24](https://www.mouser.com/ProductDetail/652-PEC11R-4220K-S24)
4. 1 OLED Screen. This is the one I used from [Amazon](https://www.amazon.com/dp/B01MQPQF24)
5. 2 Leds (3mm Any Color). These are the one I used from [Amazon](https://www.amazon.com/dp/B07QXR5MZB)
6. 2 Footswitches. These are the ones I used from [Amazon](https://www.amazon.com/dp/B08TBTWDYV)
7. Daisy Seed. You will need a Daisy Seed from [Electro-Smith](https://www.electro-smith.com/daisy/daisy)

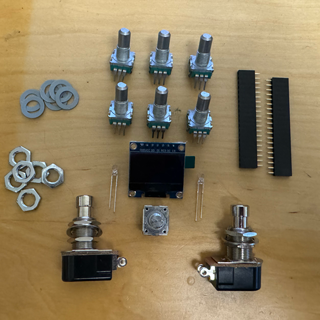
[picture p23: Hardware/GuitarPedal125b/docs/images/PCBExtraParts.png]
PCB Extra Parts


## 6. Finish the PCB (Solder Everything!)

Once you receive the PCB from JLCPCB and the extra parts you ordered separately (Headers, Pots, Encoder, Screen, LEDs, Foot Switches), you will need to solder everything to finish the PCB.

Make sure to solder them in the following order (everything goes on the side without the SMD parts, except the 20-pin headers):

1. Both 20pin Headers (make sure this goes on the side with all the SMD parts!)
2. Pots 1 - 6 (Please note these require special care as mentioned below)
3. Rotary Encoder
4. OLED Screen (Using the header that's already on the OLED, don't try to use a female socket on the pcb, but I did use some Nylon 6mm hex spacers to get it to line up flush with the enclosure when using the Alpha Pots)
5. 2 Leds (You'll need to cut the legs a little bit short to get it to line up with the enclosure, Short pin goes to the square pad)
6. 2 Footswitches
   
* PLEASE NOTE - the Pots need to be electrically isolated from some of the soldered pins that stick out on the PCB where some of them go. With the Alpha pots it's mostly an issue with the bottom row of pots (Pots 4-6).  Some of the little metal standoffs on the pots touch the pins from the daisy seed headers.  This will cause problems.  My solution was to simply cut off the metal standoff from the bottom 3 pots from the side that is closest to the pins. Like shown below.  Definitely spot check the other pots to make sure they aren't touching any pins too.

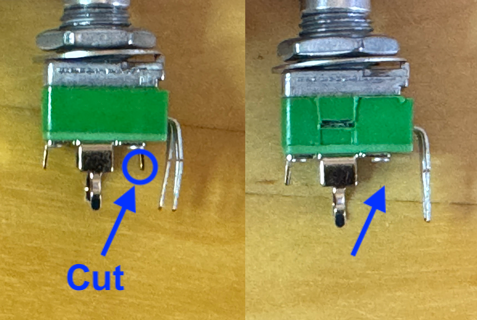
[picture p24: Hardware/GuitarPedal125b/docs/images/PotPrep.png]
Pot Prep


It will roughly look like this when finished with this step:

CircuitBoard

CircuitBoard

## 7. Order the Enclosure and External Hardware

You'll also need to order an enclosure and the external hardware such as the knobs and the Led Holders.

You can either order a generic 125B sized enclosure like these from [Tayda](https://www.taydaelectronics.com/hardware/enclosures/1590b-style-1.html) and drill your own holes (which is a pain in the butt), or you can order a custom drilled & powder coated enclosure from Tayda using this [Custom Drill Template](https://drill.taydakits.com/box-designs/new?public_key=MlRHaUhqaEVXOVVFZ1ErV1FiTXlrQT09Cg==). Alternatively, you can use provided [STEP and FreeCAD files](../enclosure/) to order or 3D print the enclosure yourself.

Additional External Hardware:

1. 6 Knobs for the POTS.  These are the ones I used from [LoveMySwitches](https://lovemyswitches.com/anodized-aluminum-knob-the-magpie-1-4-smooth-shaft-12-5mm-od/)
2. 1 Knob for the Rotary Encoder. This is what I used from [Amazon](https://www.amazon.com/gp/product/B0829WGW42)
3. 2 Led Holders (for the enclosure). These are the ones I used from [Amazon](https://www.amazon.com/gp/product/B083Q9QMN4)

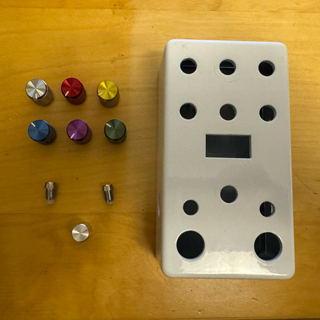
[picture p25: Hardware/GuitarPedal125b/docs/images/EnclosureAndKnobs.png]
Enclosure and Knobs


## 8. Flash the Software to the Daisy Seed on the Hardware

Before you attempt to get everything fitted into the enclosure, it's best to make sure all the hardware works.

Install the Daisy Seed into the headers on the PCB.

You'll then need to compile the code and flash it into the Daisy Seed on the hardware. Instructions can be found [here](../../../Software/GuitarPedal/README.md).

## 9. Jam everything into the enclosure, and ENJOY!

You'll want to use the LED Holders on on the enclosure and use the washers and nuts that came with the Pots and Encoder to secure them to the enclosure. 

FinalProduct

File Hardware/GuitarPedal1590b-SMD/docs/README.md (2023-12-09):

# Building the Hardware

Some quick instructions for how to make the GuitarPedal1590B SMD Hardware.  This document assumes you know the basics about soldering and circuit board assembly.  You'll also need to be fairly handy with a drill to mount the various knobs and switches on the enclosure (or you can order one pre-made from Tayda).

Quick note, I couldn't include some of the custom footprints for specific components due to licenses that wouldn't allow redistribution.  Here is a list of where you can find some of them:

* PDS1-S5-S5-M - https://www.cui.com/product/dc-dc-converters/isolated/pds1-m-series (click on "all models" for downloadable footprints)
* Neutrik NMJ6HCD2 - https://www.snapeda.com/parts/NMJ6HCD2/Neutrik/view-part/
* PJ-320A - Footprint and STEP Model found on this repository https://github.com/keebio/Keebio-Parts.pretty

Also, I just want to acknowledge that the schematics for the circuits were kit bashed together from the following sources with some additions of my own:

* [Electro-Smith: Daisy Petal Rev 5 Schematics](https://github.com/electro-smith/Hardware/blob/master/reference/daisy_petal/ES_Daisy_Petal_Rev5.pdf)
* [Simple DIY Electronic Music Projects](https://diyelectromusic.wordpress.com/2022/08/29/3v3-midi-module-pcb/)

Getting everything into KiCad and the PCB layouts are all my own work.

The KiCad files are included for the full schematic and pcb board layout in the **pcb** folder.  You really don't need to know anything about KiCad to order the PCB and get it made, but they are there for reference.

I like to order my PCBs from https://www.jlcpcb.com, but anywhere should work fine.

Follow these steps to get the PCB made by JLCPCB:

## 1. Generate the Gerber & Drill Files

The first step is to use KiCad to export the Gerber & Drill files for production like this: [JLCPCB Gerber and Drill File Generation](https://jlcpcb.com/help/article/16-How-to-generate-Gerber-and-Drill-files-in-KiCad-6). You can also skip this part and simply use the ready-made [JLCPCB Gerber Files](../pcb/JLCPCB-Gerbers/DaisySeedPedal1590b-SMD-Rev2-gerbers.zip) for this project. (Keep the files zipped)

## 2. Generate BOM and Centroid Files

To use SMT Assemble service from JLCPCB, which you will want to do, the BOM and centroid files need to be generated as well. [Follow these instructions provided by JLCPCB](https://jlcpcb.com/help/article/81-How-to-generate-the-BOM-and-Centroid-file-from-KiCAD). You can also skip this part and simply use the ready-made files for this project:

1. [JLCPCB BOM](../pcb/BOM_JLCSMT_DaisySeedGuitarPedal1590b-SMD.xlsx)
2. [JLCPCB Centroid](../pcb/JLCPCB-Gerbers/DaisySeedPedal1590b-SMD-top-pos.csv)

## 3. Pre-Order Parts for JLCPCB

There are a few parts that JLCPCB doesn't stock normally.  You can either pre-order these parts through JLCPCB through their Global Sourcing Service so they can be assembled for you (recommended) of you can order the parts yourself and solder them yourself (advanced).

The main parts they don't typically stock are:

1. PDS1-S5-S5-M (JLCPCB Part #C5377809)
2. CPC1018 This one is usually stocked these days. Probably good to double check though. (JLCPCB Part #C133069 or #C1558973), or as a substitute CPC1019 (JLCPCB Part #C1854946 or #C2760117) And of those work fine.

To order these parts through JLCPCB follow these instructions:

1. Visit the [JLCPCB Website](https://www.jlcpcb.com) and log into your account.
2. Go to the [Parts Manager Page](https://jlcpcb.com/user-center/smtPrivateLibrary/).
3. Click on Order Parts Processed Gerbers
4. There are two options for ordering parts JLCPCB Parts and Global Parts Sourcing.  I always try to use JLCPCB Parts ordering first, but sometimes you have to use Global Parts Sourcing.
5. First try looking in JLCPCB Parts and search using the above JLCPCB Part #s.  If you can order it there, great, do so.  You'll need to order at least 5 of each part.
6. If you can't find it there (sometimes the prices are crazy high, or the min quantity is a huge number), then try Global Parts Sourcing. 
7. Search for the part by name in Global Part Sourcing.
5. Find a supplier that lets you order a small quantity and double check the part name to make sure it's the right part.
6. Order at least 5 parts. (Minimum PCB assembly order is 5, so you need 5 of each part).
7. Repeat this process for both parts. 

Please note, that it typically takes a week or two to get the parts ordered and into your parts library for use.  So I like to order these parts in batches enough to place a few orders. 

## 4. Order the Assembled PCBs from JLCPCB

1. Have the Gerber, Drill, BOM, and Centroid files handy. (Keep the files zipped)
2. Visit the [JLCPCB Website](https://www.jlcpcb.com).
3. Click the **Order Now** button in the top menu bar.
4. Click the **Add Gerber File** button.
  
Add Gerbers
   
5. Upload the zipped Gerber files you downloaded above.
6. After processing the files it should provide a screen with various options. Most everything is fine by default, but you should use ENIG finishing options instead of HASL, you should check the Confirm Production File option and turn on PCB Assembly.

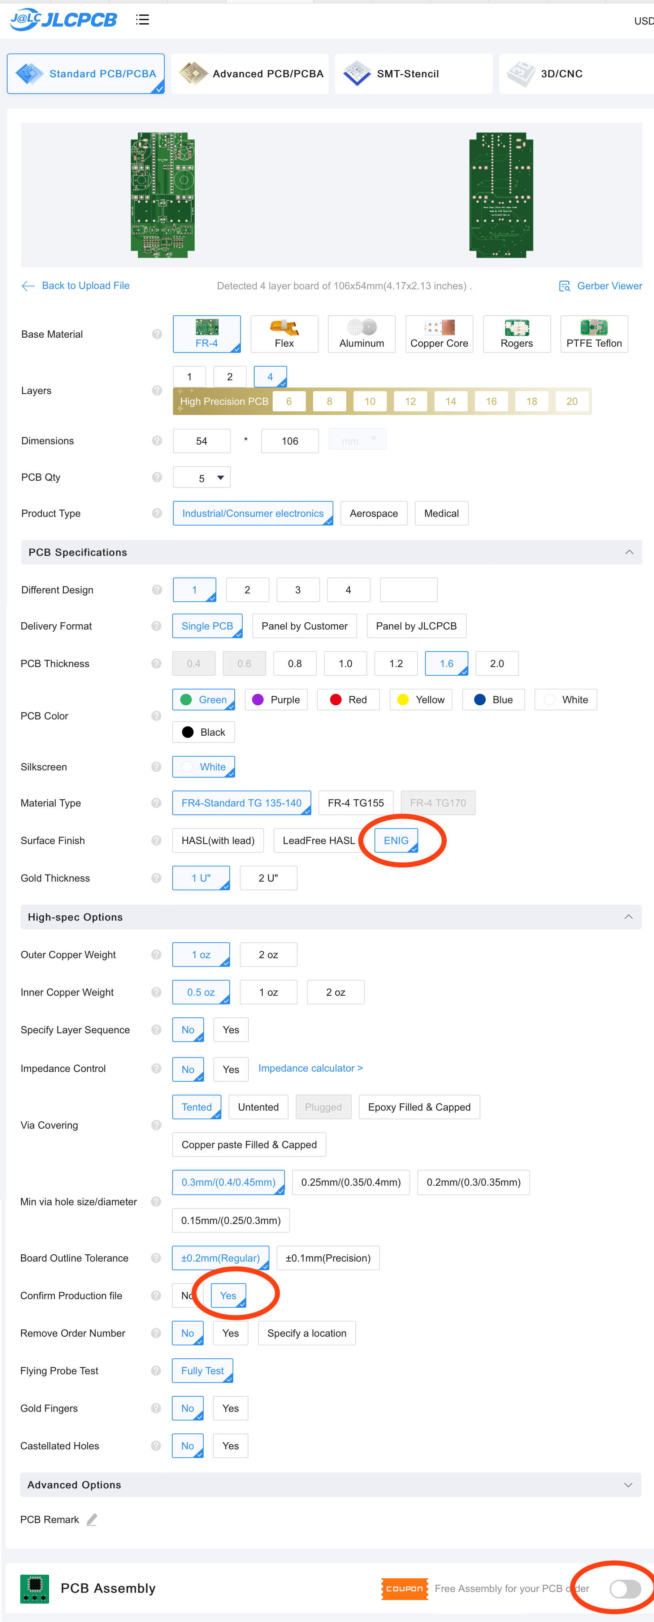
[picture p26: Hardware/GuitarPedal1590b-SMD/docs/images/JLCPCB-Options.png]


7. Once you turn on PCB Assembly, you will need to confirm that you want the Top Side assembled and definitely select the Confirm Parts Placement option.

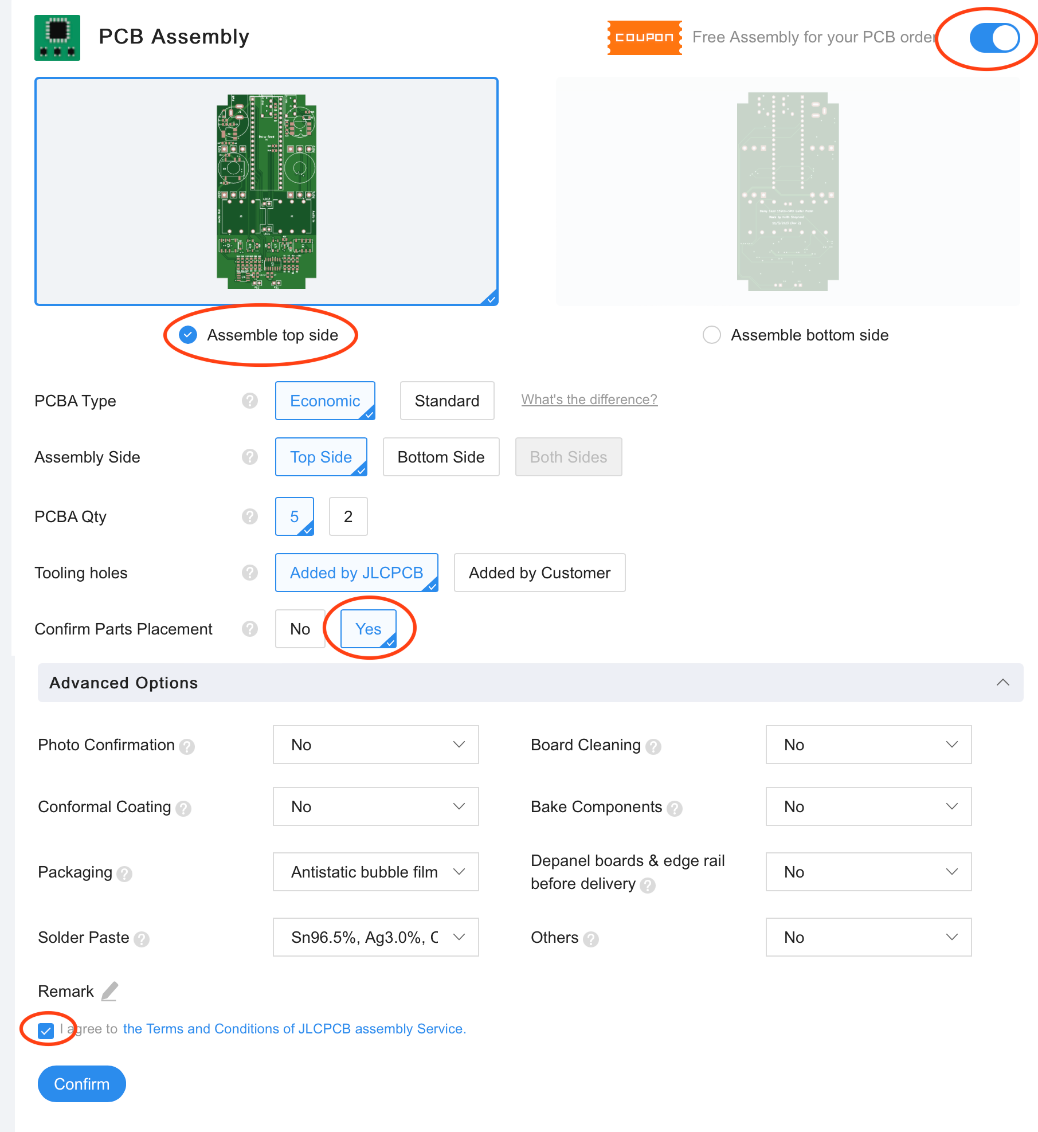
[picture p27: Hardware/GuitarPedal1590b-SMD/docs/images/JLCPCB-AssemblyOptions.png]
PCB Assembly Options


8. Click the Confirm button on the PCB Assembly panel.
9. This page shows you the side being assembled. It should look like this.

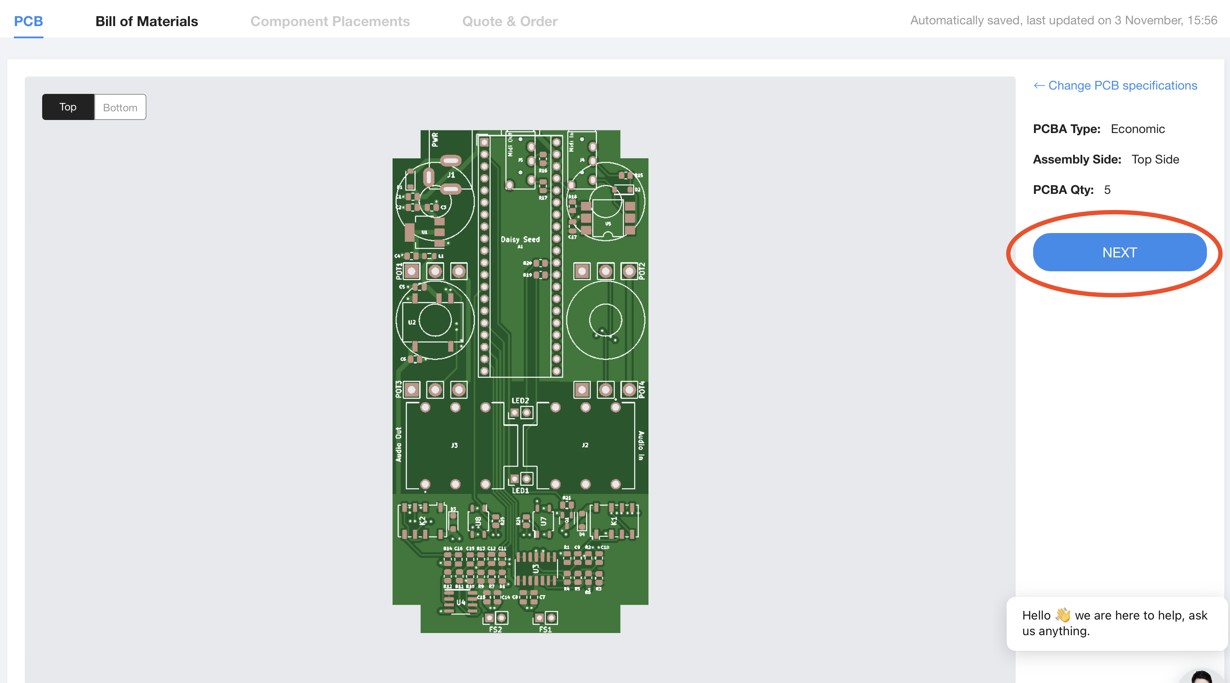
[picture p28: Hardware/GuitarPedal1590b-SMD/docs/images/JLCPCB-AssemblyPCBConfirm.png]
PCB Assembly Confirm


Click Next.

10. Next you need to upload the BOM and Centroid File.

PCB Assembly Options

11. Click Add BOM and upload the BOM file. Either the one you generated or the one you downloaded above [JLCPCB BOM](../pcb/BOM_JLCSMT_DaisySeedGuitarPedal1590b-SMD.xlsx).
12. Click Add CPL and upload the Centroid file. Either the one you generated or the one you downloaded above [JLCPCB Centroid](../pcb/JLCPCB-Gerbers/DaisySeedPedal1590b-SMD-top-pos.csv). 
13. After the files are uploaded click Process BOM and CPL.

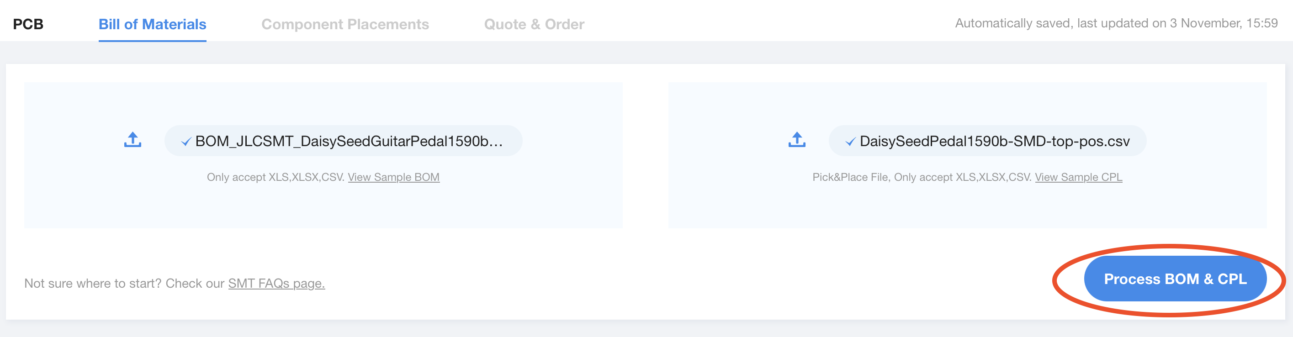
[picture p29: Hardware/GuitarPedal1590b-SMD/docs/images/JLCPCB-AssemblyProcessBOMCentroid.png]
PCB Assembly Options


14. There is a popup letting you know some parts are not in the BOM. That's ok. Press Continue.

PCB Assembly Options

15. This page asks you to confirm the parts.  You should see at the top 26 Parts Detected and 26 Parts Confirmed. (My screenshot shows 25 confirmed because I don't have enough of one of the parts in my library at the moment).

PCB Assembly Options

If it tells you any parts are missing, you may need to substitute. For instance, the parts you ordered from global parts sourcing may have ended up with a different JLCPCB Part number than the ones in the supplied files.  If that is the case you can click on the part in the list and search for the proper part and replace it.  Repeat this process until all parts are accounted for.
16. Click Next.
17. This next page allows you to view the placement of the Components.  Notice that a few of the parts of not placed or rotated properly. (this is due to differences in KiCad's footprint library and JLCPCB's library).

PCB Assembly Options

18. You will have to manually fix them in this viewer.

Simply click each part that is not properly placed, and use the buttons to rotate and move them until they are in place. The parts that need fixing are J1,J4,J5,U1,U3,U4,U5,U7,U8,K1,K2,Q1.

* Note U2 (PDS1-S5-S5-M) will not show up as available to change placement / rotation.  JCLPCB doesn't have a 3D model for this part since it's from global sourcing. Don't worry that it's not shown on this screen.

It should look like this when fixed.

PCB Assembly Options

19. Click Next.
20. Add the item to your cart, and order the PCB.

PCB Assembly Options

They will give you a price for ordering 5 assembled pcbs (that's their minimum order).  I think I paid ~$150 to have the PCB manufactured, assembled, and shipped to my door. Keep an eye on your email to confirm the order at the various steps. It will take a week or two for it arrive and they look like this:

PCBs

## 5. Order the Additional Parts JLCPCB doesn't Assemble

There are a few parts that you will need to order yourself and solder on the PCBs after you recieve them from JLCPCB.

Here is a list of the additional parts to order for the PCB:

1. 2 Headers 20-Pin Single Row for the Daisy Seed. I used these from [Amazon](https://www.amazon.com/dp/B09MYBZZKZ)
2. 4 Pots. These are the ones I used [Tayda B10k](https://www.taydaelectronics.com/tayda-10k-ohm-linear-taper-potentiometer-spline-shaft-pcb-mount-rv16196.html)
3. 2 Leds (3mm Any Color). These are the one I used from [Amazon](https://www.amazon.com/dp/B07QXR5MZB)
4. 1 or 2 Footswitches. These are the ones I used from [Amazon](https://www.amazon.com/dp/B08TBTWDYV)
5. Daisy Seed. You will need a Daisy Seed from [Electro-Smith](https://www.electro-smith.com/daisy/daisy)

PCB Extra Parts

## 6. Finish the PCB (Solder Everything!)

Once you receive the PCB from JLCPCB and the extra parts you ordered separately (Headers, Pots, LEDs, Foot Switches), you will need to solder everything to finish the PCB.

Make sure to solder them in the following order (everything goes on the side with the SMD parts:

1. Both 20pin Headers (make sure this goes on the side with all the SMD parts!)
2. Pots 1 - 4
3. 2 Leds ((You'll want to keep the legs long possibly using a 10mm spacer from the PCB, Short pin goes to the square pad!)
4. 1 or 2 Footswitches
   
It will roughly look like this when finished with this step:

CircuitBoard

## 7. Order the Enclosure and External Hardware

You'll also need to order an enclosure and the external hardware such as the knobs and the Led Holders.

You can either order a generic 1590B sized enclosure like these from [Tayda](https://www.taydaelectronics.com/hardware/enclosures/1590b-style.html) and drill your own holes (which is a pain in the butt), or you can order a custom drilled & powder coated enclosure from Tayda using this [Custom Drill Template](https://drill.taydakits.com/box-designs/new?public_key=YWRhVFFGU0Z2c3RJR09VQ1U4S3EvUT09Cg==)

Additional External Hardware:

1. 4 Knobs for the POTS.  These are the ones I used in various colors from [Tayda](https://www.taydaelectronics.com/knurled-aluminum-yellow-knob-2845.html)
2. 2 Led Holders (for the enclosure). These are the ones I used from [Amazon](https://www.amazon.com/gp/product/B083Q9QMN4)

Enclosure and Knobs

## 8. Flash the Software to the Daisy Seed on the Hardware

Before you attempt to get everything fitted into the enclosure, it's best to make sure all the hardware works.

Install the Daisy Seed into the headers on the PCB.

You'll need to compile the code and flash it into the Daisy Seed on the hardware. Instructions can be found [here](../../../Software/GuitarPedal/README.md).

## 9. Jam everything into the enclosure, and ENJOY!

You'll want to use the LED Holders on on the enclosure and use the washers and nuts that came with the Pots and Encoder to secure them to the enclosure.

FinalProduct

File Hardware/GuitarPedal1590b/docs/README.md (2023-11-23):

# Building the Hardware
Some quick instructions for how to make the GuitarPedal1590B Hardware.  This document assumes you know the basics about soldering and circuit board assembly.

Quick note, I couldn't include some of the custom footprints for specific components due to licenses that wouldn't allow redistribution.  Here is a list of where you can find some of them:

* PDS1-S5-S5-D - https://www.cui.com/product/dc-dc-converters/isolated/pds1-d-series (click on "all models" for downloadable footprints)
* Neutrik NMJ6HCD2 - https://www.snapeda.com/parts/NMJ6HCD2/Neutrik/view-part/
* PJ-320A - Footprint and STEP Model found on this repository https://github.com/keebio/Keebio-Parts.pretty

Also, I just want to acknowledge that the schematics for the circuits were kit bashed together from the following sources with some additions of my own:

* [Electro-Smith: Daisy Petal Rev 5 Schematics](https://github.com/electro-smith/Hardware/blob/master/reference/daisy_petal/ES_Daisy_Petal_Rev5.pdf)
* [Simple DIY Electronic Music Projects](https://diyelectromusic.wordpress.com/2022/08/29/3v3-midi-module-pcb/)

Getting everything into KiCad and the PCB layouts are all my own work.

## 1. Order the PCBs

The KiCad files are included for the full schematic and pcb board layout in the **pcb** folder.  You really don't need to know anything about KiCad to order the PCB and get it made, but they are there for reference.

I like to order my PCBs from https://www.jlcpcb.com, but anywhere should work fine.

Follow these steps to get the PCB made by JLCPCB:

1. Download the ready-made [JLCPCB Gerber Files](../pcb/JLCPCB-Gerbers/DaisySeedPedal1590b-Rev6-gerbers.zip) for this project to your computer. (Keep the files zipped)
2. Visit the [JLCPCB Website](https://www.jlcpcb.com).
3. Click the **Order Now** button in the top menu bar.
4. Click the **Add Gerber File** button. Add Gerbers
5. Upload the zipped Gerber files you downloaded above.
6. After processing the files it should provide a screen with various options. Everything is fine by default, but you may want to change the color of the board and I like to use ENIG finishing options instead of HASL, but this is up to you. Processed Gerbers
7. Add the item to your cart, and order the PCB.

They will give you a price for ordering 5 pcbs (that's their minimum order).  I think I paid ~$50 for a Purple board with ENIG (this is a more expensive option).  It will take a week or two for it arrive and they look like this:

PCBs

## 2. Source the Components

A full list of all the required components can be found in the [Bill_of_Materials_BOM.xlsx](Bill_of_Materials_BOM.xlsx) file.  Everything uses Through-Hole type components for simplicity sake. You can omit components C6, L1, and U2 if you don't want to use the optional filtered power section of the schematic.

## 3. Solder Everything

I like to solder in the following order for simplicy:

1. All Resistors
2. Diodes - D1 & D2
3. MLCC Capacitors - 10uF - C1, C4, C9, C10, C11, C12, C15, C16
4. (*Optional) MLCC Capacitor - 10uF - C5
5. Film Capacitors - 100nF - C2, C3, C7, C8, C13, C14
6. Ceramic Capacitor - 100nf - C17
7. LDO - 5V Linear Voltage Regular - U1
8. ICs - U3,U4,U5
9. Jacks - J1, J2, J3, J4, J5
10. 20 Pin Headers (x2) - A1
11. 3mm LEDs - LED1 & LED2 - You'll want to keep the legs long possibly using a 10mm spacer from the PCB, Short pin goes to the square pad!

Optional Filtered Power Supply:

This circuit board supports an optional filtered power supply section. If you plan to connect this pedal to a high quality isolated power source, this step is not necessary, and you can omit C6, L1, and U2. Otherwise, it's probably a good idea to do. You can add it later if you like, but you'll have to remove the Pot that this stuff sits under...

12. (*Optional) Electrolytic Capacitor - 22uF - C6
13. (*Optional) Inductor - 2.2 uH - L1
14. (*Optional) - Isolated Power Converter - U2

It looks like this image (perhaps slight change in placement of parts) if you do include this option. Leave R21 un-bridged.

Soldering

If you don't plan to filter the power, you must bridge the contacts on R21 with solder as shown in this image.

Soldering

Finally:

15. All Pots
16. All Footswitches

It goes a little something like this:

Soldering

(I omitted the 2nd foot switch from my build)

## 4. Order the Enclosure and External Hardware

You'll also need to order an enclosure and the external hardware such as the knobs and the Led Holders.

You can either order a generic 1590B sized enclosure like these from [Tayda](https://www.taydaelectronics.com/hardware/enclosures/1590b-style.html) and drill your own holes (which is a pain in the butt), or you can order a custom drilled & powder coated enclosure from Tayda using this [Custom Drill Template](https://drill.taydakits.com/box-designs/new?public_key=YWRhVFFGU0Z2c3RJR09VQ1U4S3EvUT09Cg==)

Additional External Hardware:

1. 4 Knobs for the POTS.  These are the ones I used in various colors from [Tayda](https://www.taydaelectronics.com/knurled-aluminum-yellow-knob-2845.html)
2. 2 Led Holders (for the enclosure). These are the ones I used from [Amazon](https://www.amazon.com/gp/product/B083Q9QMN4)

Enclosure and Knobs

## 5. Flash the Software to the Daisy Seed on the Hardware

Before you attempt to get everything fitted into the enclosure, it's best to make sure all the hardware works.

Install the Daisy Seed into the headers on the PCB.

You'll need to compile the code and flash it into the Daisy Seed on the hardware. Instructions can be found [here](../../../Software/GuitarPedal/README.md).

## 6. Jam everything into the enclosure, and ENJOY!

You'll want to use the LED Holders on on the enclosure and use the washers and nuts that came with the Pots and Encoder to secure them to the enclosure.

FinalProduct

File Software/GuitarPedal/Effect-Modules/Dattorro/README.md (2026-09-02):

# Dattorro plate reverb (vendored, GPLv3)

This directory contains a Dattorro (1997) plate reverb DSP core. **It is licensed under the GNU
General Public License v3 (or later), not the MIT license the rest of this repository uses** — see
[`LICENSE-GPLv3.txt`](LICENSE-GPLv3.txt). It is not compiled into GuitarPedal by default; see
"Opting in" below for what that means for your build.

## Provenance

1. **Valley Audio Soft / Dale Johnson**, *Plateau* (`PlateauNEVersio`), Copyright (C) 2020 —
   the original implementation of Jon Dattorro's 1997 plate reverb algorithm, GPL-3.0-or-later.
2. **Hothouse "Flick"** — ported Plateau's DSP core for the Cleveland Music Co. Hothouse
   platform, running it at full rate (96kHz codec, 48kHz reverb tick) with a six-knob "reverb
   edit mode" (mix, pre-delay, decay, tone, modulation, diffusion).
3. **"MuleBox"** (Hothouse, 48kHz) — same DSP core, mix-only, but the reference for correct 48kHz
   input-section scaling (`dattorroScaleFactor`), since Flick runs its codec at 96kHz.
4. **bkshepherd/DaisySeedProjects "AmpSim"** — ported the same core to the 125B hardware this
   repository targets, running it at half rate (24kHz) to fit the CPU budget of an amp
   simulator that also has other work to do each block. AmpSim's copy is the one vendored here,
   because it independently fixed several sample-rate-handling bugs present in the original
   Plateau/Flick/MuleBox source (see "Fixes carried from AmpSim" below) — GuitarPedal runs this
   reverb as its own dedicated effect at full rate, so it inherits those fixes rather than
   re-discovering them.
5. **GuitarPedal `DattorroReverbModule`** (`Effect-Modules/dattorro_reverb_module.{h,cpp}`, one
   directory up) — wraps this DSP core as a normal loadable `BaseEffectModule`, exposing the same
   six knobs as Flick's edit mode, plus a menu-only seventh ("Size" / Dattorro's internal Time
   Scale) since the 125B hardware has exactly six knobs and all are already mapped.

Every vendored file below carries the original Valley Audio copyright header and an
`SPDX-License-Identifier: GPL-3.0-or-later` line, restoring what was dropped somewhere in the
Flick → AmpSim transit, plus a note on what (if anything) changed in this copy.

| File | Origin | Notes |
|---|---|---|
| `Dattorro.hpp` / `Dattorro.cpp` | AmpSim (fixed) | see "Fixes carried from AmpSim" |
| `dsp/delays/AllpassFilter.hpp` | Flick (unmodified upstream of AmpSim too) | style-normalized only |
| `dsp/delays/InterpDelay.hpp` | AmpSim, **allocation scheme rewritten** | see "Arena allocation" |
| `dsp/filters/OnePoleFilters.hpp` | Flick (unmodified upstream of AmpSim too) | style-normalized only |
| `dsp/modulation/LFO.hpp` | Flick (unmodified upstream of AmpSim too) | style-normalized only |
| `LICENSE-GPLv3.txt` | Plateau (PlateauNEVersio) | verbatim |

## Fixes carried from AmpSim

Relative to the original Plateau/Flick/MuleBox source, this copy (via AmpSim) fixes:

- **Tank sample-rate clamp** — `Dattorro1997Tank::maxSampleRate` is now actually wired to the
  constructor argument (`initMaxSampleRate`) instead of being left at its 32kHz default and
  silently clamping every higher rate down to it.
- **Missing `delaysInitialised` guard** — `setSampleRate()` no longer reallocates all twelve
  internal delay lines and allpass filters on every call, only once.
- **Tank LFO sample rate** — the four tank modulation LFOs (`lfo1`..`lfo4`) are now actually told
  the current sample rate (`lfoN.setSamplerate(sampleRate)`), instead of running at whatever rate
  they were constructed with (which was silently wrong at every rate but 32kHz).
- **Output tap rounding** — `rescaleTapTimes()` now rounds (`lroundf`) instead of truncating when
  rescaling the tank's output tap positions for the current sample rate, removing a small
  systematic bias.
- **Pre-delay buffer sizing** — `preDelay` is sized for 200ms at 48kHz (`InterpDelay(9600, ...)`)
  rather than whatever smaller buffer the original assumed.

None of the parameter defaults needed to change to adopt these fixes: AmpSim's own preset
(`ApplyPreset()` in its `reverb_processor.h`) reuses Flick/MuleBox's exact tuned values (decay
0.8, tank diffusion 0.85, time scale 1.0075, and the same tone/mod pitches) against its own
already-fixed tank, which is the evidence this module's defaults were chosen against too.

The tank's *nominal* internal design sample rate (`dattorroSampleRate = 29761.0`, giving a
`sampleRateScale` of ~1.075 at 32kHz and above) is intentionally left alone — it's the shared
voicing all of Flick, MuleBox and AmpSim were tuned against, and re-deriving it from the Dattorro
paper's nominal values would mean re-voicing decay/diffusion/tone from scratch with no reference
to check against.

## Arena allocation

The original `InterpDelay` (Flick, MuleBox) allocates a fixed
`float DSY_SDRAM_BSS sdramData[50][144000]` — 28.8 MB — sized for the largest configuration either
pedal ever instantiates. GuitarPedal's SDRAM is already ~70% committed by the time
`load_effects()` finishes instantiating every other module's own SDRAM buffers, so that doesn't
fit.

`InterpDelay` here instead draws from an `InterpDelayArena`: a static bump allocator over an
external buffer the caller installs with `InterpDelayArena::set(base, size)`. Each `InterpDelay`
constructed while the arena is armed carves its buffer out of it; if none is armed (or it's
exhausted), it falls back to an owned `std::vector<float>` on the heap, which keeps the class
usable in desktop/unit tests without any SDRAM to hand.

`DattorroReverbModule::Init()` arms a 1 MiB arena (declared as a `DSY_SDRAM_BSS` global directly in
`dattorro_reverb_module.cpp`, matching this repo's per-module-owns-its-SDRAM-global convention)
immediately before constructing the `Dattorro` engine, and releases it immediately after. A full
48kHz `Dattorro(48000.0f, 16.0f, 4.0f)` needs roughly 870 KB across its 12 delay lines, leaving
about 15% headroom in the 1 MiB budget. If the arena is ever exhausted, the module does not halt
(there's no halt-loop precedent in this codebase) — it sets a flag and passes audio through dry
instead of risking an unbounded heap fallback on an embedded target.

## Opting in

This code is not built by default. Enabling it means your firmware links GPLv3 code and the
resulting binary must be distributed under GPLv3 (or not distributed at all) — see the top-level
[`README.md`](../../README.md) for the exact lines to uncomment in the `Makefile` and
`loaded_effects.h`, and for what this means for your build.

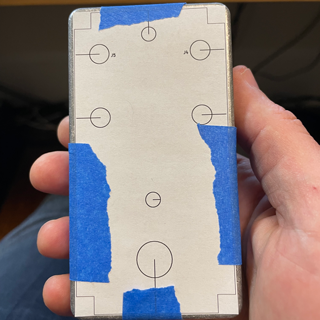
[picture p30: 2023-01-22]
Hardware/GuitarPedal1590b-SMD/docs/images/HoleTemplate.png

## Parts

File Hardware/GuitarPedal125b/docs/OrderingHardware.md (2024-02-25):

# Ordering Hardware
I get a lot of requests to buy kits or finished pedals based on my designs. This is not something I typically do, but sometimes I do have extra PCBs, parts, and enclosures lying around and I'm willing to pass them along to you, basically at cost, as outlined below.

If you are interested, please message me through GitHub or you can find me on the Electro-Smith [Forums](https://forum.electro-smith.com/t/my-daisy-guitar-pedal-designs-on-github/3641) & [Discord](https://discord.gg/ByHBnMtQTR) as Kshep and can message me there.

I also really can't supply much customer support on this stuff or offer any warranty on the hardware. I'm not really trying to start a pedal business. I'm doing this for fun and to learn new things, which is why I provide all these designs and documenation here on GitHub for free.

## Complete Pedal (without Daisy Seed)
Price: $150 (USD) + Shipping & Handling

This option is everything you need, except the Daisy Seed. Knobs and Enclosure colors are at my whim and may vary based on what I have lying around.

You'll basically get a finished pedal ready for you to [create your own cool effects](../../../Software/GuitarPedal/README.md).

PCBsPCBs

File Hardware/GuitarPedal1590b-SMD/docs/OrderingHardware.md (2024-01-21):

# Ordering Hardware
I get a lot of requests to buy kits or finished pedals based on my designs. This is not something I typically do, but sometimes I do have extra PCBs, parts, and enclosures lying around and I'm willing to pass them along to you, basically at cost, as outlined in the options below.

If you are interested, please message me through GitHub or you can find me on the Electro-Smith [Forums](https://forum.electro-smith.com/t/my-daisy-guitar-pedal-designs-on-github/3641) & [Discord](https://discord.gg/ByHBnMtQTR) as Kshep and can message me there. 

I also really can't supply much customer support on this stuff or offer any warranty on the hardware. I'm not really trying to start a pedal business. I'm doing this for fun and to learn new things, which is why I provide all these designs and documenation here on GitHub for free.

## Option 1 - Complete PCB (without Daisy Seed)
Price: $75 (USD) + Shipping & Handling

This option gets you a fully assembled PCB, I'll even test it (briefly) to make sure it works. You will still need to get an Enclosure, get Knobs and other hardware for the Enclosure, get a Daisy Seed, and Assemble everything yourself.

You'll basically be starting at [Step 7: Order the Enclosure and External Hardware](README.md#7-order-the-enclosure-and-external-hardware)

PCBs

## Option 2 - Complete Pedal (without Daisy Seed)
Price: $125 (USD) + Shipping & Handling

I usually don't have extra Enclosures and Knobs around, so this might not always be an option. Plus picking custom colors for your knobs and enclosure is half the fun! [Step 7: Order the Enclosure and External Hardware](README.md#7-order-the-enclosure-and-external-hardware) is so freaking easy, I highly recommend doing Option 1, instead of this one if you are picky about aesthetics.

This option is everything you need, except the Daisy Seed. Knobs and Enclosure colors are at my whim and may vary based on what I have lying around.

You'll basically get a finished pedal ready for you to [create your own cool effects](../../../Software/GuitarPedal/README.md).

PCBsPCBs

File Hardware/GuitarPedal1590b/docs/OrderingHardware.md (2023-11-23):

# Ordering Hardware
I get a lot of requests to buy kits or finished pedals based on my designs. This is not something I typically do, but sometimes I do have extra PCBs, parts, and enclosures lying around and I'm willing to pass them along to you, basically at cost, as outlined in the options below.

If you are interested, please message me through GitHub or you can find me on the Electro-Smith [Forums](https://forum.electro-smith.com/t/my-daisy-guitar-pedal-designs-on-github/3641) & [Discord](https://discord.gg/ByHBnMtQTR) as Kshep and can message me there. 

I also really can't supply much customer support on this stuff or offer any warranty on the hardware. I'm not really trying to start a pedal business. I'm doing this for fun and to learn new things, which is why I provide all these designs and documentation here on GitHub for free.

## Option 1 - PCB Only
Price: $10 (USD) + Shipping & Handling

About as bare bones as you can get. 

This option is just the PCB.  You will still need to source the components, solder everything to the PCB, get an Enclosure, get Knobs and other hardware for the Enclosure, get a Daisy Seed, and Assemble everything yourself.

You'll basically be starting at [Step 5: Build the Hardware](README.md#2-source-the-components)

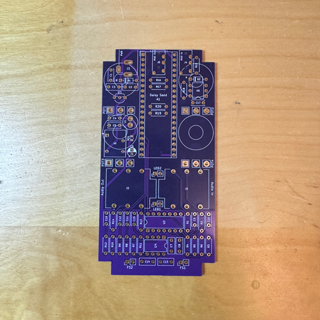
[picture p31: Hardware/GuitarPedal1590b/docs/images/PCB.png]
PCB


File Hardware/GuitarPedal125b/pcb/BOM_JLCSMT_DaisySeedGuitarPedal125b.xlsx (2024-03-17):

Comment | Designator | Footprint | JLCPCB Part #（optional）
10uF | C1, C4, C7, C8, C11, C12, C15, C16 | 805 | C15850
100nF | C2, C3, C5, C6, C13, C14, C17 | 805 | C49678
2.2nF | C9, C10 | 805 | C28260
10nF | C18, C19 | 805 | C1710
1N5817 | D1 | SOD-123 | C727113
1N4148W | D2 | SOD-123 | C81598
1N4007W | D3, D4 | SOD-123FL | C108803
DC-005-2.5A-2.0 | J1 |  | C136744
NMJ6HCD2 | J2, J4 |  | C368502
PJ-320A | J3, J5 |  | C2884926
1x20 Through Hole Header | J6, J7 |  | C50984
G6K-2G-Y DC5 | K1, K2 | SMD,6.5x10mm | C397140
SS8050 | Q1 | SOT-23-3 | C2150
2M | R1, R2, R4, R5, R9-12, R15, R16 | 805 | C26112
100K | R3, R6 | 805 | C149504
100R | R13, R14 | 805 | C17408
220R | R17 | 805 | C17557
33R | R19 | 805 | C17634
10R | R18 | 805 | C17415
470R | R20 | 805 | C17710
1K | R21-25 | 805 | C17513
3.3K | R7, R8 | 805 | C26010
10K | R26-29 | 805 | C17414
LD1117S50CTR | U1 | SOT-223-3 | C81157
MCP6004T-I/SL | U2 | SOIC-14 | C7378
OPA1652AIDR | U3 | SOIC-8 | C30025
H11L1 | U4 | SOP-6-2.54mm | C78589
CPC1018N | U5, U6 | SOP-4-2.54mm | C133069

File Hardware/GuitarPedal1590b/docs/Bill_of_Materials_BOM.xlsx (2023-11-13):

Item # | *Designator | *Qty | Manufacturer | *Mfg Part # | Description / Value | *Package/Footprint | Type | Your Instructions / Notes
1 | A1 | 1 | Electro-Smith | https://www.electro-smith.com/daisy/daisy | Daisy Seed | 20 Pin Headers | thru-hole | Use two 20pin female headers to make a socket for the Seed. This is needed since some components fit under the seed. I used these: https://www.amazon.com/dp/B09MYBZZKZ
2 | C1, C4, C5, C9, C10, C11, C12, C15, C16 | 9 | Generic | Generic | Ceramic Capacitor 10uF | Disc | thru-hole
3 | C2, C3, C7, C8, C13, C14 | 6 | WIMA | MKS2C031001A00JC00 | Film Capacitor 100nF | Box | thru-hole | https://www.mouser.com/ProductDetail/505-MKS2C031001AJC00
4 | C17 | 1 | Generic | Generic | Ceramic Capacitor 100nF | Disc | thru-hole
4 | C6 | 1 | Generic | Generic | Electrolytic Capacitor 22uF | Radial | thru-hole
5 | D1 | 1 | Generic | Generic | Diode 1N5817 | SOD27 | thru-hole
6 | D2 | 1 | Generic | Generic | Diode 1N4148 or Diode 1N914 | SOD27 | thru-hole
7 | FS1, FS2 | 2 | DaierTek | ASIN: B08TBTWDYV | SPST Momentary Soft Touch Foot Switch | Panel Mount | thru-hole | Connect circuit board pads to foot switch leads with 22 AWG wire so the footswitch can be mounted on the enclosure. Used this part: https://www.amazon.com/dp/B08TBTWDYV
8 | J1 | 1 | Gravitech (https://www.mouser.com/manufacturer/gravitech/) | CON-SOCJ-2155 | 2.1mm DC Power Jack | PCB Mount | thru-hole | https://www.mouser.com/ProductDetail/992-CON-SOCJ-2155
9 | J2, J3 | 2 | DaierTek | ASIN: B097BDHV5Y | 1/4" Jack Female 6.35mm Stereo Socket PCB Mount | 6 pin | thru-hole | https://www.amazon.com/dp/B097BDHV5Y
10 | J4, J5 | 2 | uxcell | ASIN: B07KY8NMD5 | 3.5mm Audio Jack Connector PCB Mount Female Socket | 4-Pin PJ-320A | thru-hole | https://www.amazon.com/dp/B07KY8NMD5
11 | L1 | 1 | Generic | Generic | 2.2uH Inductor Iron Core | Radial | thru-hole
12 | LED1, LED2 | 2 | Generic | Generic | 3mm LED | Panel Mount | thru-hole | Connect circuit board pads to LED with 22 AWG wire so that the led can be mounted on the enclosure. Any led should work, there is a 1k resistor to limit the current from the 3.3v source. I used these nice LED holders to mount on the enclosure: https://www.amazon.com/dp/B083Q9QMN4
13 | POT1, POT2, POT3, POT4 | 4 | Generic | Generic | 10k Potentiameter Linear Taper (Type B) Long Pins | Panel Mount | thru-hole | I used pots with long leads from Tayda. They worked great. https://www.taydaelectronics.com/potentiometer-variable-resistors/rotary-potentiometer/linear/tayda-10k-ohm-linear-taper-potentiometer-spline-shaft-pcb-mount-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 or you can connect circuit board pads to each POT wires for non-long lead pots.
14 | R1, R2, R4, R5, R7, R8, R9, R10, R13, R14 | 10 | Generic | Generic | 2M Ohm Resistor Metal Film 1/4W +/-1% | Axial | thru-hole
15 | R3, R6 | 2 | Generic | Generic | 100K Ohm Resistor Metal Film 1/4W +/-1% | Axial | thru-hole
16 | R11, R12 | 2 | Generic | Generic | 100 Ohm Resistor Metal Film 1/4W +/-1% | Axial | thru-hole
17 | R15 | 1 | Generic | Generic | 220 Ohm Resistor Metal Film 1/4W +/-1% | Axial | thru-hole
18 | R16 | 1 | Generic | Generic | 33 Ohm Resistor Metal Film 1/4W +/-1% | Axial | thru-hole
19 | R17 | 1 | Generic | Generic | 10 Ohm Resistor Metal Film 1/4W +/-1% | Axial | thru-hole
20 | R18 | 1 | Generic | Generic | 470 Ohm Resistor Metal Film 1/4W +/-1% | Axial | thru-hole
21 | R19, R20 | 2 | Generic | Generic | 1K Ohm Resistor Metal Film 1/4W +/-1% | Axial | thru-hole
22 | R21 | 0 | DNP (Do Not Place)
23 | U1 | 1 | STMicorelectronics | L4931CZ50-AP | LDO Voltage Regulators 5.0V 0.25A Positive | TO-92 | thru-hole | https://www.mouser.com/ProductDetail/511-L4931CZ50-AP
24 | U2 | 1 | CUI Inc. | PDS1-S5-S5-D | Isolated DC/DC Converter 1W 4.5-5.5Vin 5Vout 200mA unreg iso | Custom Package | thru-hole | https://www.mouser.com/ProductDetail/490-PDS1-S5-S5-D
25 | U3 | 1 | Microchip Technology | MCP6004-I/P | IC OpAmp 4-Circuit | 14-DIP | thru-hole | https://www.digikey.com/en/products/detail/microchip-technology/MCP6004-I-P/523060
26 | U4 | 1 | Texas Instruments | OPA2134PA | IC OpAmp 2-Circuit | 8-DIP | thru-hole | https://www.mouser.com/ProductDetail/595-OPA2134PA
27 | U5 | 1 | isocom | H11L1 | Optocoupler, 1 Channel, 5kV | 6-DIP | thru-hole | https://www.newark.com/isocom/h11l1/optocoupler-schmitt-trigger-5300vrms/dp/45P3438

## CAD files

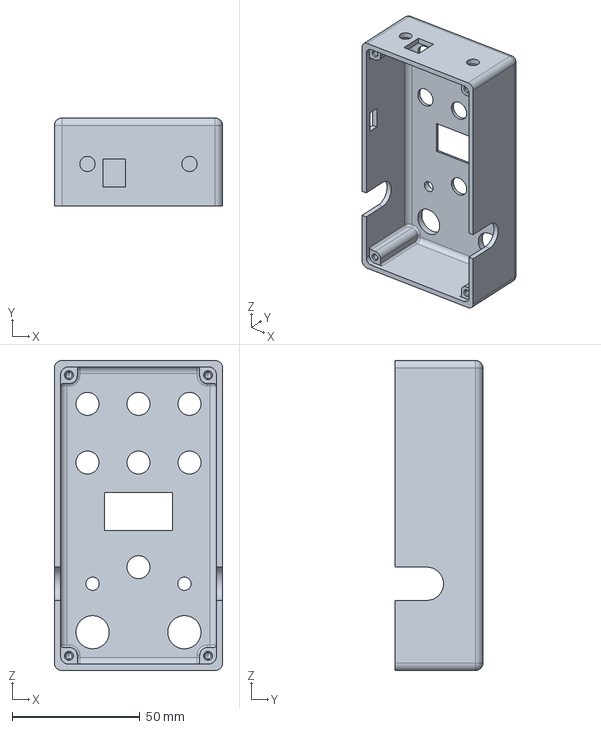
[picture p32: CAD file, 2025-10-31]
Hardware/GuitarPedal125b/enclosure/daisy-enclosure.FCStd
66.0 x 34.5 x 121.5 mm

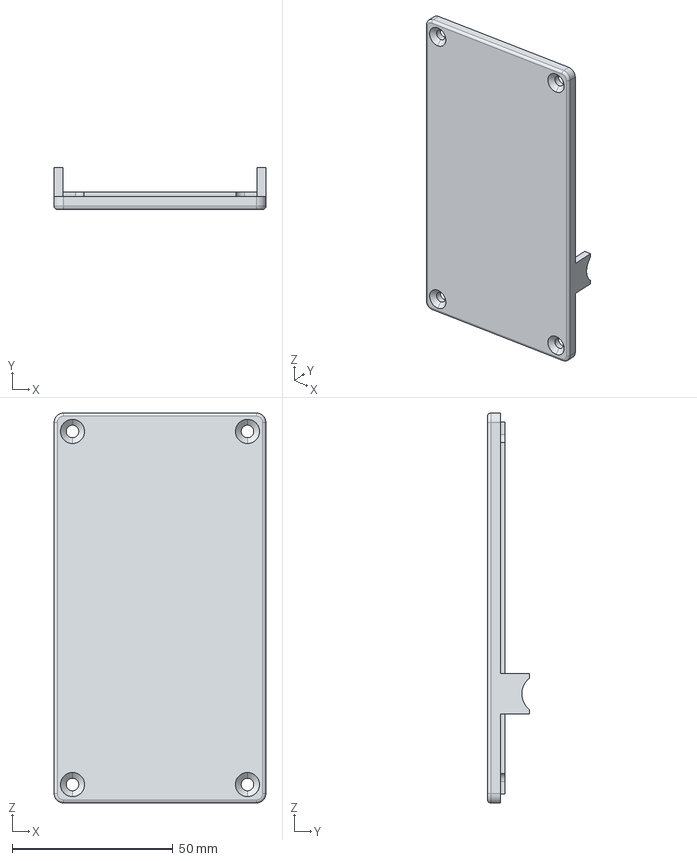
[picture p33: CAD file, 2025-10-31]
Hardware/GuitarPedal125b/enclosure/daisy-enclosure-bottom.step
66.0 x 13.0 x 121.5 mm

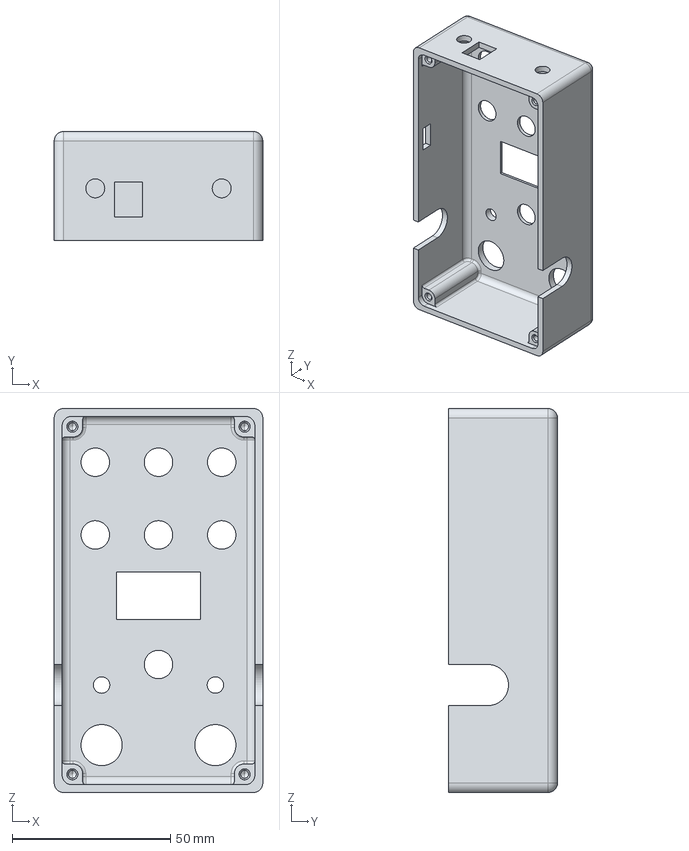
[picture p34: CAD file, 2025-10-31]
Hardware/GuitarPedal125b/enclosure/daisy-enclosure-top.step
66.0 x 34.5 x 121.5 mm

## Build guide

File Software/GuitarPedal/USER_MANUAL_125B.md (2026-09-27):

# 125B User Manual

This is a DIY pedal project, not a finished product. You build the PCB-based hardware, fit it into an enclosure, then compile and flash the firmware configuration that suits you.

## Build and Configure

- Follow the [125B hardware build guide](../../Hardware/GuitarPedal125b/docs/README.md) for PCB manufacture, parts, assembly, and enclosure details. The guide includes ready-to-order board files and describes the additional parts and soldering required.
- Install the toolchain and dependencies, then follow the [software build and deployment instructions](README.md#4-build-and-deploy-the-code). The 125B is the default hardware target; check `guitar_pedal.cpp` if you have changed variants.
- Choose the installed effects and their order by editing `loaded_effects.h`, then build and flash, per the instruction in the README. Since only one effect is active at a time, there is little penalty for enabling a lot of different effects, but if there are ones you won't use, it's better to leave them out so they don't clutter the menu system.

If you want to have two or three active effects at the same time, it is possible (with some limitations) to make a combined effect, by defining an `EffectChain` in `loaded_effects.h`; it appears as one selectable effect and processes its child effects in sequence. Keep an eye on CPU headroom: a large chain can exceed the processor's capacity, and some modules have restrictions on chaining. See the [EffectChain notes](README.md#combining-effects-effectchain) before building a chain.

## Connections

Connect your instrument to Input and your amplifier or next device to Output. The 125B supports stereo or mono input and output; it also has MIDI In/Out, USB access for firmware updates, and a standard 9 V center-negative "pedal" power input. Follow the hardware guide for wiring and assembly details.

## Controls

### Knobs and Encoder

Each effect assigns up to six parameters to the six knobs. The assignments vary by effect and firmware. A knob may be unused. Turning a mapped knob changes its parameter immediately; the display briefly shows the parameter name and value. Other parameters can be edited from the effect's parameter menu.

Note that each effect starts out with the parameter values defined in its "Preset 0", which is initially configured by the effect's authors to (hopefully) be a sensible starting point. Only when turning a knob does the relevant parameter value get updated. This means that, until a knob is turned, its physical position may not match the parameter value.

The rotary encoder underneath the screen controls the menu system. Turn the encoder to move through menus or adjust a selected value. Press it to open a menu item, start editing, or confirm a choice. Use the on-screen Back item to return.

### Footswitches and LEDs

- **Primary (right):** Press to turn the selected effect on or bypass it. Hold for about two seconds to jump to the tuner (assuming it's included in the build).
- **Secondary (left):** Its action depends on the selected effect. Double-tap to set tap tempo when that effect supports tempo. Press and release actions can also control effect-specific features such as a looper. Holding for about one second triggers the effect's hold action; in a chain configured with a second knob bank, this switches banks and displays `SHIFT`.
- **Effect selection shortcut:** Hold the secondary switch and turn the encoder to move through the effect list. Note that you can also select the effect from the menu system, by turning the encoder to the "Effect" menu item.
- **Manual save:** Hold both footswitches for about two seconds to save the current effect's settings to its selected preset. The display shows a save confirmation. If auto-save is off (the default), effect parameters will return to their previous state if the pedal is rebooted, or when switching effects.

The right LED (above the primary footswitch) generally indicates if the pedal is active (light on) or bypassed (light off). The left LED (above the secondary footswitch) is effect-dependent. For example, it may blink in time to the delay temp, or indicate a secondary effect.

## Menus and Presets

Press the encoder from the main screen to open the current effect's parameter list. Turn to a parameter and press the encoder to edit it; choose **Defaults** to reset that effect's parameters to their "factory" defaults. The main menu also contains:

- **Preset:** Select a preset for the current effect. Presets are stored separately for each effect, and there is always a "Preset 0" that is the "power-on" state. After changing settings via knobs or the effect parameter menu, hold both footswitches down to save to the selected preset.
- **Effect:** Select which effect is active.
- **Settings:** Configure global pedal behavior, described below.

The selected effect and pedal on/bypass state are retained across power cycles. Preset saving is separate unless Auto-save is enabled.

## Settings

- **True Bypass:** Uses the hardware relay to route around the effect when bypassed. Turn it off to use buffered bypass instead.
- **Split Mono:** Sends the left input to both processing channels for a mono source. This applies when True Bypass is off.
- **MIDI On:** Enables MIDI input handling, including mapped controls and effect selection by program change.
- **MIDI Thru:** Forwards incoming MIDI messages to MIDI Out.
- **MIDI Ch:** Selects the MIDI channel the pedal responds to (1-16).
- **Auto-save:** After parameter changes stop for five seconds, saves that effect's settings to Preset 0. This overwrites Preset 0; turn it off if you use that preset for a manual patch, or want the pedal to always return to a saved state on startup.
- **Reboot:** Restarts the Daisy Seed in bootloader mode – useful for firmware updates.

## Effects

The default firmware currently includes the effects below. Their exact controls and knob assignments can change with the build; the effect parameter menu lists the controls available in your version.

- **Tremolo, Harm Trem, AutoPan, Chopper:** Amplitude or stereo-pan modulation; rate/tempo, depth, waveform, and related modulation controls.
- **Chorus, Phaser, Flanger:** Sweeping modulation effects; rate, depth, mix, feedback, and tone controls.
- **Overdrive, Distortion, Crusher:** Saturation and digital reduction; drive/gain, tone, output level, bit depth, or sample-rate reduction.
- **Compressor, Noise Gate:** Dynamic range and noise control; level, ratio, threshold, attack, and release.
- **Reverb, CloudSeed:** Short room-like to expansive reverberation; mix, decay, pre-delay, size, and tone/damping.
- **Delay, Multi Delay, Tape Delay, Dual Echo ("Halo"), Granular Delay, Spectral Delay:** Echo and time-based textures; delay/tap times, feedback, mix, filtering, modulation, and grain or spectral controls.
- **Pitch, PolyOctave, SciFi:** Pitch shifting, octave generation, and processed pitch effects; interval, dry/wet balance, and effect-specific controls.
- **Graphic EQ, Parametric EQ:** Tone shaping; band gain and, for parametric bands, frequency and bandwidth.
- **NAM, IR:** Amp and cabinet impulse-response processing; model or IR selection, gain, level, and EQ.
- **Looper, Drum, Metronome, Tuner:** Performance and utility tools; loop levels/actions, rhythm or tempo controls, and tuning options.

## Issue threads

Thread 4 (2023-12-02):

Flash utilization

KnightHill, 2023-12-02:
Flash utilization is 97.16% after the latest changes. It is unlikely more than one or two new effects can be added. I am wondering if there is a cheap way to decrease that.

bkshepherd, 2023-12-03:
This forum thread covers the options pretty well: https://forum.electro-smith.com/t/out-of-flash-memory-walkthrough-with-samples/4370/10

The lowest hanging fruit is to simply turn on compiler binary size optimization by adding OPT = -Os to the make file.   I did a quick test, that gets it down to 93.16%.

I'm not sure offloading anything to SDRAM would help at the moment as I'm not sure I'm allocating any huge buffers.

Honestly, I haven't really done any profiling, so I'm not really sure what's using all the memory.  I will say that just an empty sample project that takes input and routes it directly to output with no other code uses 48.69% of memory on its own.

Switching to the boot loader and running things out of SRAM however would help a lot. It would give us 4x the space going from 128KB -> 512KB.

bkshepherd, 2024-02-13:
The project now default to using the Daisy custom boot loader to run the programs out of SRAM.  This increases the amount of space available for program code from 128kb to 512kb.   I also updated the read me to describe how to use the boot loader.

Closed 2024-02-13.

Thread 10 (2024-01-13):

Pots 4-6 in the GuitarPedal125b hardware non-ideally rotated 180 degrees

bkshepherd, 2024-01-13:
The second row of pots (4-6) on the GuitarPedal125b hardware are non-ideally rotated 180 degrees. The primary issue with this is exacerbated by the fact that the pots are D-shaft which makes it so that any D-shaft knobs used don't have their indicators line up properly.  The work around is to use smooth shaft knobs, but these are hard to secure properly and hard to level properly when used on the d-shaft.

The rotation was unfortunately necessary to be able to fit all the elements onto the PCB.  It's not a simple matter of rotating the elements on the PCB 180 degrees. The elements will no longer fit anymore if that is done. I've explored a number of possible alternative layouts to make it work, but it doesn't seem possible with the current set of features.

The use of D-shaft pots was also unfortunately necessary due to the fact that the Bournes PRS11R family of Pots is only available in D-shaft.  This family of pots was selected because it was the only pot slim enough to pair well and match the height of the Bounes PEC11R family of encoders.

bkshepherd, 2024-03-17:
Updated the design to use cheaper and more readily available Alpha 9mm pots.  (RD901F-40-15R1-B10K).  These are also smooth shaft pots, so their orientation on the PCB no longer matters.

Closed 2024-03-17.

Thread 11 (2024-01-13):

There are through-hole pins located under some of the pots which can cause electrical shorts

bkshepherd, 2024-01-13:
This issue affects the GuitarPedal125b hardware design.  There are a number of through-hole components that are directly under the PCB mounted PRS11R pots.  If these protruding pins touch the underside of the pots they can cause electrical shorts causing the hardware to malfunction or not behave as expected.  This is specifically an issue with Pot1, Pot3, and Pots 4-6.

This issue is mentioned in the hardware build instructions and the recommend work around is to isolate the pots from the pcb using doublesided foam tape as described [here](https://github.com/bkshepherd/DaisySeedProjects/blob/main/Hardware/GuitarPedal125b/docs/README.md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). This is less than ideal, but it works.

Potential future workarounds include redesigning the PCB to use surface mount parts instead of the through-hole parts that are protruding, but would require a fairly large re-layout of the entire PCB.

bkshepherd, 2024-03-17:
Updated the design to use the Alpha 9mm pots (RD901F-40-15R1-B10K) this addresses the need to use this workaround.

Closed 2024-03-17.

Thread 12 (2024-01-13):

It can be difficult to remove the PCB from the 125b enclosure

bkshepherd, 2024-01-13:
This issue affects the GuitarPedal125b design.  The TRS 1/8" Midi jacks on the PCB can cause the PCB to be quite difficult to be removed from the 125b enclosure.  This is because the end of the midi jack must protrude part way through the enclosure to allow the plug to make proper contact with the jack on the PCB.

bkshepherd, 2024-01-13:
I recently modified the [Custom Drill Template](https://drill.taydakits.com/box-designs/new?public_key=ZXRnaU9PaWx0b1hNa3VxeTJua3d2dz09Cg==) to help reduce this issue. The hole for the midi jack is now larger and I changed the placement of the holes for the pots by 1mm to allow for a little more play in moving the PCB.   In my tests this makes the PCB much easier to remove from the enclosure and should resolve this issue.

Closed 2024-01-13.

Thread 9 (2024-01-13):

Rev7 Seed Noise

bkshepherd, 2024-01-13:
There is an issue causing noise in the signal when there is one of my pedals using a Rev7 Daisy Seed has another one of my pedals connected to the output of the first pedal.  It doesn't matter which rev Daisy Seed is in the second pedal, the noise will occur.

This issue does not occur when using multiple of my pedals with Rev 5 Daisy Seeds in each of them back to back.
This issue does not occur when there is only a single one of my pedals in the signal chain.

Working with Electro-Smith to identify and resolve the issue.  No further information at this time.

bkshepherd, 2024-01-21:
After much investigation, the issue is that the new audio Codec chip in the Rev 7 daisy seed (the PCM3060) does not include a very strong on board Low pass filter on the audio outs compared to the audio code used prior to Rev 7.  According to the spec sheet on the PCM 3060 "An external low-pass filter is used if further out-of-band noise rejection is required."  Sure enough, if I add a low pass filter to the audio outputs, the noise issue is resolved.  This will be included in the next revision of the pedal design as shown in the attached schematic:

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

bkshepherd, 2024-03-17:
Updated the design to add the RC Low Pass filter as described above.  Confirmed it does indeed address the noise issues with the Rev7 seed.

Closed 2024-03-17.

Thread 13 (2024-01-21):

Guitar Pedal Settings Storage is currently limited to 8 active effects with 16 parameters each

bkshepherd, 2024-01-21:
The current software implemented of local storage on QSPI for the storage of effect parameters settings is quite simplistic and limited.

The current implementation in guitar_pedal_storage.h & .cpp is hard coded to treat each effect parameter as a u_int8 type and to simply allocated a block of memory in the QSPI region that is SETTINGS_MAX_EFFECT_COUNT * SETTINGS_MAX_PARAM_COUNT * sizeof(u_int8) bytes. Using this approach, it's quite easy to look up the stored value for a parameter by simply using an offset into this block of memory.  Unfortunately, this is quite limited and not very flexible for future use. In the current code base SETTINGS_MAX_EFFECT_COUNT is set to 8 and SETTINGS_MAX_PARAM_COUNT is set to 16.  Which effectively limits the device to a max of 8 active effects with up to 16 parameters each.  This is not a hardware memory limit.  Those numbers were chosen quite arbitrarily.  If you need more parameters feel free to adjust those defines for your own purposes.

This presents a great opportunity for someone wanting to contribute to the project to get started with something that wouldn't be too hard to improve.  Some ideas that would make this a lot more flexible:

- Allow an arbitrary number of presets
- Allow an arbitrary number of effect parameters per preset
- Only allocate the actual  amount of storage needed to save a preset for a particular effect module
- Support additional stored data types beyond u_int8.  In would be nice to store some parameters as floats for instance.
- Bonus points if presets stored in the old format can easily be updated to the new format.

bkshepherd, 2024-01-25:
Yes, this is fairly similar to what I was thinking.   I think the main thing I was initially thinking was to just change the persistent storage class to work on 32bit segments of data instead of 8bit.  That way, you could simply type cast the bytes to whatever type the parameter is expecting 32bit int, 32bit float, etc.   But instead of adding a new enumeration for the storage type, I'd just use the ParameterValueType to infer how it should treat the underlying 32bits of data for that parameter (as a int or float or whatever). Pretty similar to what you proposed, but I think your idea lets some of the smaller sizes still take up less data in storage, which is nice.

The other thing that becomes a bit tricky is that each effect would now have a variable size block of data for storage, so in the guitar_pedal_storage classes, you'd have to update the various helper function to know what the offset into the data is for the stored parameters for this effect.  It might be necessary to have a map of start offsets for each effect on the Settings struct.

If this is something you want to work on improving, sounds great!  I'm definitely happy to accept pull requests.

Thank you!

jaching, 2024-01-27:
Thanks for the feedback!  You gave me more to consider, as I was fairly stuck on the idea of maintaining legacy behavior.  But I like what you initially had in mind better than my proposal.

I didn't consider the extra tracking that would be required, for some reason I thought it would be easy to add this as a parameter in ParameterMetaData, but this is a constant would require the end user to explicitly map this size (which adds an extra margin of error, for no reason,) or use the method that you suggested, which is use another array to track start offsets, which means allocating more RAM just to know the offset.

But the more thinking about using the byte method, the software would be incrementing through each element array, which would add a performance cost, compared to creating helper functions that explicitly cast the correct data type on the uint32.

Additionally, I have the feeling that running out of QSPI for storing 32 bits parameters, might be the least of concerns, since we have 8MB of data to work with (so in the ball park of 2 million 32 bit parameters, around 1M if you redundant copies, less if you additionally want to also store CRC , etc.).

I'd be more than happy to take this on, so I will start now.

jaching, 2024-02-03:
Hello @bkshepherd ,

I forgot to ask this before, but can you add me as a contributor so that I can create a branch for a pull request?

I also wanted to provide an update from my side.  I ended up having to attend a conference this week and unfortunately getting covid as well, and as such.

I was able to add the following (but am still in the process of checking that I did not break anything UI/audio wise from these changes).  If any of this is not intended, please let me know (or after I create the pull request), and I can revert.

**Changes:**
- Arbitrary number of presets per effect (there is just a global limitation provided by the maximum size of globalEffectsSettings array),
- Note: I have not had the chance to check this, as I haven't added a way to do this in the settings menu yet to swap presets/add more, but I do have functions which will shift the storage words accordingly if a new preset is added for an effect.
- Arbitrary number of effects (determine by the number of parameters in Meta Data)
- Added a check for when the end user has added new parameters to an effect, when this is the case, shift the rest of the persistent memory buffer to ensure that no presets are lost in the process.
- Changed the base storage type to uint32
- Changed IntMappings such that an arbitrary min and max are range is used/displayed
- Changed FloatMagnitude enum to Float, and changed from IntMapping to FloatMapping, and added new methods to get Float values, (e.g. the end user can now change a Wet parameter to min:0%, max:100% with floating point precision in between)

**Example Persistent Storage globalEffectsSettings format (e.g. say we have 2 Effects):**
[0] Current sum of all Effects/Presets/Parameters
[1] Number of Parameters for Effect 0 (e.g. 3)
[2] Number of Presets for Effect 0 (e.g. 2)
[3] Effect 0: Preset 0: Parameter 0 (e.g. 123)
[4] Effect 0: Preset 0: Parameter 1 (e.g. 14)
[5] Effect 0: Preset 0: Parameter 2 (e.g. 54)
[6] Effect 0: Preset 1: Parameter 0 (e.g. 1)
[7] Effect 0: Preset 1: Parameter 1 (e.g. 154)
[8] Effect 0: Preset 1: Parameter 2 (e.g. 84)
[9] Number of Parameters for Effect 1 (e.g. 2)
[10] Number of Presets for Effect 1 (1)
[11] Effect 1: Preset 0: Parameter 0 (e.g. 0)
[12] Effect 1: Preset 0: Parameter 1 (e.g. 3)
[13] Effect 1: Preset 0: Parameter 1 (e.g. 5)

bkshepherd, 2024-02-03:
Awesome! I added you as a collaborator.  I look forward to checking it all out!

jaching, 2024-02-07:
I posted an initial version but missing a few features that I wanted to ask your opinion on.  Unfortunately it adds quite a bit of bloat to the code, which means less effects if running from Flash.

* Reset Presets button within the Presets page
* For MIDI CC Handling: Would you be okay with a user configurable override such that guitar_pedal.cpp invokes the MIDI Received method rather than simply setting the parameter?  Likewise pair this with a "number of consecutive MIDI CC values" integer.  This way the end user can choose to do their own handling of MIDI (e.g. mapping 2 MIDI Bytes to the upper 14 bits of a float).

Also, I'm still working some issues out with the Multi Tapped Delay (for some reason I have inconsistent behavior if I allocate PitchShifter objects to SDRAM, it will work for some builds but not all), but I at least have a rough sample with 2/4 Taps being pitch shifted.
https://www.youtube.com/watch?v=u0BaoX-MdT8

bkshepherd, 2024-02-07:
The multi-tap delay sounds great!  Nice work!

1) For the reset, I think there is a menu option that just simply calls a function when selected.  That would be the one to use if you add it to the settings menu configurations.   That was something I had been meaning to do!

2) For the MidiCC handling, yeah that sounds great.  Let the effect module itself have a function to accept midi CC and let it decide how to handle it.  I'd still make sure to provide default handling for the typical use case though in the base class.

jaching, 2024-02-09:
Thanks, its been a lot of fun to work on!  I am astonished that I can process 4 separate pitchshifter objects simultaneously without crackling, but then again my only frame of reference is trying something similar thing with a much more CPU Intensive pitch shifting in MaxMsp a year or so ago.

1. Ah, I completely missed that somehow.  This has been added.
2. After some more thought, I decided the easiest way without adding too much more overhead is to just use a virtual function from the base effect class to allow the user to decide what to do with the Midi CC.  Currently to not add to much more logic/overhead, the guitar_pedal class will call this function from the Active Effect when it cannot find the parameter.

I'm starting a PR with the initial version of the Multi Delay class that is useable, along with everything else in this topic, to not hold up this issue any further.  Please have a look and let me know if there are any issues!

bkshepherd, 2024-02-10:
Thanks for getting this submitted a pull request!  I'm going to try to take a look this weekend and get it merged in.

bkshepherd, 2024-02-13:
Merged in the Storage Presets Display Update. This issue is closed!

Closed 2024-02-13.

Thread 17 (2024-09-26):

Unexpected Issue with the SMD Version

PaixLagie, 2024-09-26:
**Hi!**

_Before we start, I want to clarify that I’m not using SDRAM and that I only want to activate a single effect._

I’m facing an issue with the SMD version of the pedal. Indeed, when I strictly follow your recommendations for flashing the Daisy Seed, I encounter this kind of problem:

```
guitar_pedal.cpp:23:1: error: 'GuitarPedal1590B' does not name a type
   23 | GuitarPedal1590B-SMD hardware;
      | ^~~~~~~~~~~~~~~~
guitar_pedal.cpp:26:37: error: 'hardware' was not declared in this scope
   26 | PersistentStorage<Settings> storage(hardware.seed.qspi);
      |                                     ^~~~~~~~
guitar_pedal.cpp: In function 'void AudioCallback(daisy::AudioHandle::InputBuffer, daisy::AudioHandle::OutputBuffer, size_t)':
guitar_pedal.cpp:97:5: error: 'hardware' was not declared in this scope
   97 |     hardware.ProcessAnalogControls();
      |     ^~~~~~~~
guitar_pedal.cpp: In function 'void HandleMidiMessage(daisy::MidiEvent)':
guitar_pedal.cpp:368:10: error: 'hardware' was not declared in this scope
  368 |     if (!hardware.SupportsMidi())
      |          ^~~~~~~~
guitar_pedal.cpp:402:9: error: 'hardware' was not declared in this scope
  402 |         hardware.midi.SendMessage(midiData, sizeof(uint8_t) * bytesToSend);
      |         ^~~~~~~~
guitar_pedal.cpp: In function 'int main()':
guitar_pedal.cpp:466:5: error: 'hardware' was not declared in this scope
  466 |     hardware.Init();
      |     ^~~~~~~~
make: *** [libDaisy/core/Makefile:285: build/guitar_pedal.o] Error 1

```
So, I concluded that using `-` was causing the issue. I removed all the `-` both in the code and in the names of `guitar_pedal_1590bSMD.h` and `guitar_pedal_1590bSMD.cpp` (I could have used `_`, but I’m not sentimental about it). Once that was done, I had no compilation issues.

Next:

I ran `$ make program-boot` and everything went fine. Same for `$ make program-dfu`, no issues.

Then came the crucial moment when I tested my overdrive. But absolutely nothing happened. The sound passes through both jacks just fine. The Daisy Seed is properly connected. I tested with a multimeter, and the current seems fine everywhere.

But I don’t understand where the problem could be. I must be doing something wrong because it would be strange if I were the first one to encounter this issue.

Are you still working on this project?

_PS: I’m still a beginner please don’t get mad at me.
I don’t see the rule: `make build-and-program-dfu`_

bkshepherd, 2024-09-28:
Strange.  Just to confirm you trying to build the software to run on the 1590b smd hardware, correct?

If so, in guitar_pedal.cpp at the top you would need to have:

#include "Hardware-Modules/guitar_pedal_1590b-SMD.h"  (instead of the 125b version)

and then

// Hardware Interface
GuitarPedal1590BSMD hardware;

You shouldn't have needed to remove the "-" from the file name.  It compiles just fine for me as is, but perhaps there is some difference in compilers that doesn't like the "-".   I'm on a mac, not sure if that matters.

As for why there is no sound, that sounds strange.

in the guitar_pedal.cpp, what does your main function look like?  I assume you modified this part:

    // Init the Effects Modules
    availableEffectsCount = 8;
    availableEffects = new BaseEffectModule*[availableEffectsCount];
    availableEffects[0] = new ModulatedTremoloModule();
    availableEffects[1] = new OverdriveModule();
    availableEffects[2] = new AutoPanModule();
    availableEffects[3] = new ChorusModule();
    availableEffects[4] = new ChopperModule();
    availableEffects[5] = new ReverbModule();
    availableEffects[6] = new MultiDelayModule();
    availableEffects[7] = new MetroModule();

to only list your new overdrive module?  It may be worth trying to have it use one of the existing sample ones to see if it works.

Also, sometimes the flash memory on the seed gets into a weird state.  The simplest way to get it to reset is to modify guitar_pedal_storage.h to change:

// Peristant Storage Settings
#define SETTINGS_FILE_FORMAT_VERSION 2

to another number.  Like 1 or 3 doesn't matter.  Then recompile and flash it to the device.  When a file format mis-match is detected it will force clearing the flash memory.

Hope that helps.

PaixLagie, 2024-10-04:
### **Hi there!**

I've made some progress in my research, and it seems like my compiler is acting up completely.

_Just to confirm, you're trying to build the software to run on the 1590b SMD hardware, correct?_ **Correct!**

Despite the errors, the code is still working:

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

I'm curious to know which compiler you're using.

_As for why there's no sound, it's strange._
The basic guitar sound works, but 0 effects . I've tried other options besides the overdrive with effects you kindly shared. By tinkering with my compiler, I managed to get the tremolo effect working, but strangely, it's the only one that works. With the others, I just get the normal guitar sound without any effect.

My hypothesis is that **the lack of SDRAM seriously limits which effects I can use.**

I tried this:

`#define SETTINGS_FILE_FORMAT_VERSION 2`
...but nothing notable happened. :/

I'll keep this post updated as I continue my investigation whenever I get a bit more time.

xconverge, 2024-12-30:
@PaixLagie definitely comment on this if you come back to it and have more time

The project has changed a little bit since then, there is an option/ability to download/flash a pre-compiled version of the project that you are welcome to try as well! https://github.com/bkshepherd/DaisySeedProjects/tree/main/Software/GuitarPedal#using-pre-compiled-releases

I am closing this issue for now but we can certainly open it back up if you continue to have issues!

Closed 2024-12-30.

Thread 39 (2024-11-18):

Can't build and deploy the Code

MarkusBaumknecht, 2024-11-18:
hi Keith!

First of all I wanted to say thanks for this project and the documentation, it's really been a breeze to build and follow and I've learned a lot in the process.

I have one issue though. Everything up to this point works fine, but I get an error message when trying to compile the code on windows, more specifically when running the `make program-dfu` command in VSCode.

This is what I'm getting:

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

people in the Electrosmith forums suggested it might have something to do with building the libraries, but that didn't seem to be the issue after all. can you comment? I'm on Windows 10 and using VSCode / Git CMD.

best wishes!

xconverge, 2024-11-18:
Can you post the output of when you ran make (not program-dfu)?

I suspect there is an error in generating guitarpedal.bin which is the previous step

MarkusBaumknecht, 2024-11-19:
> $ make program-boot

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

xconverge, 2024-11-19:
It looks like you have the bootloader flashed, so now it is time to build and flash the software (these next steps you will do over and over again if you make software changes)

We can update the README later if it is missing for now, but here are the steps I do

```
make
```
to build the .bin firmware for the pedal (I do `make -j8` to go a bit faster). It should end with a summary of how much memory will be used by the program

then press the reset button, and very quickly within 2 to 3 seconds
```
make program-dfu
```
to write the .bin to the daisy

xconverge, 2024-11-19:
If you encounter issues, you also may need to build libDaisy and DaisySP first

```
cd libDaisy/
make -j8
cd ..
cd DaisySP/
make -j8
```

then try again with the original

```
make -j8
```

MarkusBaumknecht, 2024-11-19:
Ok, I tried to follow your steps (everything in VSCode). Here's the output for the respective steps:

./libDaisy (main)
$ make -j8

> mkdir build
> make: *** No rule to make target 'build/Drivers/STM32H7xx_HAL_Driver/Src/stm32h7xx_hal.o', needed by 'build/libdaisy.a'.  Stop.
> make: *** Waiting for unfinished jobs....

./DaisySP (master)
$ make -j8

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

$ make

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

it seems that DaisySP is being built, but there is an issue with libdaisy and naturally everything that follows ...

xconverge, 2024-11-19:
Can you check to see if this file exists:

```
libDaisy/Drivers/CMSIS-Device/ST/STM32H7xx/Include/stm32h7xx.h
```

I suspect some of the libDaisy git submodules (basically sub projects of different repositories, kind of like how this project includes libDaisy) may not have fetched and this file is not there?

If it is missing (and probably either way since it wont harm anything) I would try this just to make sure it is all pulled:

```
cd libDaisy
git checkout master
git pull
git submodule update --init --recursive
git pull
```

then try to `make` in `libDaisy/` again, with the hope that something happened in the above steps

xconverge, 2024-11-20:
Excellent, enjoy!

Closed 2024-11-20.

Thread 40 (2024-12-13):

Terrarium Hardware Configuration

DaveMulls, 2024-12-13:
Hey there, I'm trying to get this working on a Pedalpcb Terrarium build, I've been speaking to @xconverge who has been kind enough to get me to the point where I have the project loaded on the seed and I can pass clean signal through, but I have no effects and no response from footswitches, LED's, and toggle switches.

I'm not particularly worried about switching between modules as I am happy to play with one at a time, but I was hoping to sort out the controls mapping. @xconverge suggested I tag @bkshepherd or @keyth72 to see if you guys had any ideas. Thanks in advance!

xconverge, 2024-12-13:
@bkshepherd @keyth72 I am totally onboard to support @DaveMulls with getting the one effect he is interested in working, etc, but I am a bit at a loss for why the tremolo isnt working out of the box once he setup the terrarium header in guitar_pedal.cpp. I can't think of much and was wondering if either of you had a) terrarium hw you have tested recently with this project or b) any other guesses/suggestions

DaveMulls, 2024-12-13:
Just to confirm, I have made these changes in guitar_pedal.cpp:

#include "Hardware-Modules/guitar_pedal_terrarium.h"

// Hardware Interface
GuitarPedalTerrarium hardware;

xconverge, 2024-12-14:
@DaveMulls the https://github.com/bkshepherd/DaisySeedProjects/blob/main/Software/GuitarPedal/Hardware-Modules/guitar_pedal_terrarium.cpp file doesn't look right to me at all for at least the current rev of the build docs I see for the terrarium

Can you try these changes:

```diff
diff --git a/Software/GuitarPedal/Hardware-Modules/guitar_pedal_terrarium.cpp b/Software/GuitarPedal/Hardware-Modules/guitar_pedal_terrarium.cpp
index 58ab1a3..ce63e0a 100644
--- a/Software/GuitarPedal/Hardware-Modules/guitar_pedal_terrarium.cpp
+++ b/Software/GuitarPedal/Hardware-Modules/guitar_pedal_terrarium.cpp
@@ -17,12 +17,12 @@ GuitarPedalTerrarium::~GuitarPedalTerrarium() {}
 void GuitarPedalTerrarium::Init(bool boost) {
     BaseHardwareModule::Init(boost);

-    Pin knobPins[] = {seed::D16, seed::D17, seed::D18, seed::D19, seed::D20, seed::D21};
+    Pin knobPins[] = {seed::D17, seed::D18, seed::D19, seed::D20, seed::D21, seed::D22};
     InitKnobs(6, knobPins);

-    Pin switchPins[] = {seed::D26, seed::D25, seed::D10, seed::D9, seed::D8, seed::D7};
-    InitSwitches(6, switchPins);
+    Pin switchPins[] = {seed::D27, seed::D26};
+    InitSwitches(2, switchPins);

-    Pin ledPins[] = {seed::D23, seed::D22};
+    Pin ledPins[] = {seed::D24, seed::D23};
     InitLeds(2, ledPins);
 }

```

DaveMulls, 2024-12-14:
Hey @xconverge unfortunately no change with the alterations, still passing clean signal though. Here is my guitar_pedal_terrarium.cpp with the alterations, let me know if I maybe input them wrong:

#include "guitar_pedal_terrarium.h"

using namespace bkshepherd;

static const int s_switchParamCount = 2;
static const PreferredSwitchMetaData s_switchMetaData[s_switchParamCount] = {
    {sfType : SpecialFunctionType::Bypass, switchMapping : 0}, {sfType : SpecialFunctionType::Alternate, switchMapping : 1}};

GuitarPedalTerrarium::GuitarPedalTerrarium() : BaseHardwareModule() {
    // Setup the Switch Meta Data for this hardware
    m_switchMetaDataParamCount = s_switchParamCount;
    m_switchMetaData = s_switchMetaData;
}

GuitarPedalTerrarium::~GuitarPedalTerrarium() {}

void GuitarPedalTerrarium::Init(bool boost) {
    BaseHardwareModule::Init(boost);

    Pin knobPins[] = {seed::D17, seed::D18, seed::D19, seed::D20, seed::D21, seed::D22};
    InitKnobs(6, knobPins);

    Pin switchPins[] = {seed::D27, seed::D26, seed::D11, seed::D10, seed::D9, seed::D8};
    InitSwitches(6, switchPins);

    Pin ledPins[] = {seed::D24, seed::D23};
    InitLeds(2, ledPins);
}

Are any changes required to the guitar_pedal_terrarium.h?

xconverge, 2024-12-14:
Looking at his project here they have the same mappings https://github.com/schult/terrarium-poly-octave/tree/main so maybe I read the docs (https://docs.pedalpcb.com/project/Terrarium.pdf) wrong and you should just revert all of the changes I suggested in that file and ignore that idea of mine...

bkshepherd, 2024-12-14:
Hmmm, it's been a long time since I tried this on the terrarium hardware, but it was working at the time.  I'll see if I can dig mine up over the holidays.   @xconverge Do you think some of the fancier foot switch input configurations stuff maybe changed the way something worked?

xconverge, 2024-12-14:
> Hmmm, it's been a long time since I tried this on the terrarium hardware, but it was working at the time. I'll see if I can dig mine up over the holidays. @xconverge Do you think some of the fancier foot switch input configurations stuff maybe changed the way something worked?

I have looked through the code pretty thoroughly and can't find anything obvious, let me flash a "terrarium-like" config to mine and see if anything shows up

bkshepherd, 2024-12-14:
The only other thing I can think of is it's not obeying the fact that Terrarium doesn't have the relayed based bypass.  The code for the Terrarium hardware module is setting m_supportsTrueBypass to false (which is correct), and m_supportsStereo to false (which is also correct) but maybe something in guitar_pedal.cpp is no longer working correctly when try bypass and stereo are off

xconverge, 2024-12-14:
That is going to be it, I can kind of reproduce the problem with this , so should be easy for me to get it up and going

```diff
diff --git a/Software/GuitarPedal/Hardware-Modules/guitar_pedal_125b.cpp b/Software/GuitarPedal/Hardware-Modules/guitar_pedal_125b.cpp
index 95cc118..cef151c 100644
--- a/Software/GuitarPedal/Hardware-Modules/guitar_pedal_125b.cpp
+++ b/Software/GuitarPedal/Hardware-Modules/guitar_pedal_125b.cpp
@@ -31,7 +31,7 @@ void GuitarPedal125B::Init(bool boost) {
     Pin ledPins[] = {seed::D22, seed::D23};
     InitLeds(2, ledPins);

-    InitMidi(seed::D30, seed::D29);
-    InitDisplay(seed::D9, seed::D11);
-    InitTrueBypass(seed::D1, seed::D12);
+    // InitMidi(seed::D30, seed::D29);
+    // InitDisplay(seed::D9, seed::D11);
+    // InitTrueBypass(seed::D1, seed::D12);
 }
\ No newline at end of file

```

@DaveMulls do your LEDs work though? Because I can get the LEDs to work even though the signal is always clean

bkshepherd, 2024-12-14:
@xconverge I'm not surprised that not initializing TrueBypass makes the 125B pass a clear signal though,  because if the relays aren't turning on, they default to bypass mode.  So that doesn't necessarily mean it's the same issue on the terrarium hardware, because by default on the terrarium all signal goes through the daisy signal path (there is no bypass at all)

xconverge, 2024-12-14:
@DaveMulls you could try an earlier version of the code (and make the same tweak to guitar_pedal.cpp to use the terrarium config)

`git checkout v1.0.0` in the root of the repo to pull a version from a year ago

then make sure your submodules are pulled and do a `make clean && make -j8` in both libDaisy and daisySP

This is certainly something you can try... even if moving between submodule versions can get annoying with the rebuilds and cleanup

DaveMulls, 2024-12-14:
@xconverge no lights, I'll give the earlier version a go and report back shortly! Thanks guys

DaveMulls, 2024-12-14:
I know this is probably a mistake on my end as I don't have much experience with this stuff, I've reverted to v1.0.0 and successfully ran "make clean && make -j8" in both libDaisy and daisySP, and changed the hardware config for Terrarium, but when I try to flash to the seed I get this error:
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
DaveMulls, 2024-12-15:
Ok I got it to flash, sadly still no functionality. One difference though, the USER light on the seed is flashing intermittently when it's powered up. I'm like 99% sure that wasn't happening with the updated build.

DaveMulls, 2024-12-16:
@bkshepherd ah ya that's probably it. Yes hardware is for sure working, I'm been running projects for about a year on it without issue, though it's only been through the daisy web programmer with .bin files.

No rush at all, I really appreciate you taking a look!

xconverge, 2024-12-16:
Can you share the output of your `make program-dfu` command? Is it possible it isn't flashing the way you would expect? I am guessing that you could also take the .bin created and use the web programmer as you were already doing

DaveMulls, 2024-12-16:
This is for the current revision:

$ make program-dfu
dfu-util -a 0 -s 0x90040000:leave -D build/guitarpedal.bin -d ,0483:df11
dfu-util 0.10

Copyright 2005-2009 Weston Schmidt, Harald Welte and OpenMoko Inc.
Copyright 2010-2020 Tormod Volden and Stefan Schmidt
This program is Free Software and has ABSOLUTELY NO WARRANTY
Please report bugs to http://sourceforge.net/p/dfu-util/tickets/

Warning: Invalid DFU suffix signature
A valid DFU suffix will be required in a future dfu-util release!!!
Opening DFU capable USB device...
ID 0483:df11
Run-time device DFU version 011a
Claiming USB DFU Interface...
Setting Alternate Setting #0 ...
Determining device status: state = dfuIDLE, status = 0
dfuIDLE, continuing
DFU mode device DFU version 011a
Device returned transfer size 4096
DfuSe interface name: "Flash "
Downloading element to address = 0x90040000, size = 184580
Erase           [=========================] 100%       184580 bytes
Erase    done.
Download        [=========================] 100%       184580 bytes
Download done.
File downloaded successfully
Transitioning to dfuMANIFEST state

I also tried using the Daisy web programmer with the bin file but it's the same result, successful download but no controls.

DaveMulls, 2024-12-16:
SUCCESS!!! I have the modulated tremolo up and running, the control mapping is a bit off but I can definitely sort that out. I have been fiddling with chatGPT and it suggested modifying guitar_pedal.cpp to add this to the code and it seemed to sort everything out:
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

I think I should be good to go from here. I really appreciate both of you taking time out of your lives to help me out!

xconverge, 2024-12-16:
What is the change there?

Now you can switch back to the latest and try again :)

I am not sure why the controls would be off, they look right in the codebase (my previous comments were wrong I think)

DaveMulls, 2024-12-17:
I have basically zero programming experience but what it flagged was that the effects modules weren't being initialized and that I had to move the initialization to be closer to the beginning of the code, which I guess makes it run earlier on in the process. Once I made that change everything fell into place. As for controls that was my mistake, they are all correct!

GuitarML, 2024-12-17:
For what it's worth I was able to run the main branch on my terrarium this afternoon without modifying the code, the tremolo effect came up with the expected knob mapping and led action. Glad you got it running though!

xconverge, 2024-12-17:
What operating system are you on? @DaveMulls

Let me know when/if you go to run the latest code. I will run some tools (https://en.wikipedia.org/wiki/Static_program_analysis) over the code later to see if they catch anything else, I still can't see what is wrong or changed super clearly but I am also not questioning what is working!

DaveMulls, 2024-12-17:
@GuitarML Ya I think it's very likely that the problem was on my end and i just took enough tries and fiddling to fix whatever I had gotten scrambled. The difference with what worked is that I added in the "void initialize effects" line of code in and moved int section above it. When I look at the code on the git repo it looks like it already has the "void initialize effects" so I think I must have somehow altered it previously. I've got the latest code to run now, I think it's probably not worth investigating if it's running on your side, but let me know if you'd like to dig in and I can provide anything needed!

Closed 2024-12-17.

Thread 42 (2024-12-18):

MIDI cc controls not working

GuitarML, 2024-12-18:
When using the latest code, sending midi cc messages to control effect parameters doesn't seem to work correctly. On an older build it does work (I think before the custom display values were added, around Feb 2024). It seems to detect the message, because the screen flickers but immediately goes to "0.0". Is there a way to use midi controls with the updated value and preset handling? Thanks!

xconverge, 2024-12-18:
Which effect? All of them?

I wonder if the screen logic is taking priority

I don't have any midi stuff to really test unfortunately, I could try to rig something up in the near future though

GuitarML, 2024-12-18:
I changed most of the effect midi mapping to match my midi controller, so there's something going on besides it being set to -1. I haven't tried switching the effects over midi, I'm guessing that's a program change midi message rather than CC? Still learning about midi myself but I can take a look at the code to try to understand the logic for it.

bkshepherd, 2024-12-18:
I have a feeling this got broken when the underlying values used to store parameters changed from 8bit uints to 32bit bytes that could represent more data types.  The midi cc commands were taking advantage of the fact that the underlying data structure was the same range as the allowable midi values.  I bet it just needs to cal the appropriate setter functions for the data type instead of assuming the underlying is a uint and setting the RAW bytes.

GuitarML, 2024-12-18:
@bkshepherd it also looks like the logic for each data type is different than the old code when updating the UI. Before, unknown/raw/float values were all grouped into one "if" statement, but now the float data type is separated out and only sets as float, instead of setting as raw. So the parameters I'm changing that are set as "FloatMagnitude" type, it never gets to the logic to update the raw value, it only tries to update the float value. But since it's midi it's only receiving an int value. I'll try setting a parameter as a "Raw" data type and see if midi works for it then.

GuitarML, 2024-12-18:
@bkshepherd is it possible to convert the uint8 received by midi into a uint32 before sending to the set raw function? Or was there a particular setter function in the code you are referring to that I should use.

bkshepherd, 2024-12-18:
@GuitarML Yeah, I think this is the root of the problem.  You can't just convert the midi uint8 to uint32 and set the parameter and hope it works because there are many parameter types now.  In the handle midi function you'd probably need to special case the default behavior for the actual parameter type.  For instance.  if the param is a bool.  use the midi 0..127 for False and 128..255 as True. For Parameters that are 0..1 magnitude map the midi 0..255 to 0.0 to 1.0 range with discrete increments.  For the binned value convert the midi 0..255 to minValue->maxValue.   I think I had also thought about adding a callback to specific effect_Modules to allow them to override default midi conversion mappings to get this logic out of the main guitar_pedal.cpp, but I clearly never got around to doing this.

xconverge, 2024-12-18:
> @GuitarML Yeah, I think this is the root of the problem. You can't just convert the midi uint8 to uint32 and set the parameter and hope it works because there are many parameter types now. In the handle midi function you'd probably need to special case the default behavior for the actual parameter type. For instance. if the param is a bool. use the midi 0..127 for False and 128..255 as True. For Parameters that are 0..1 magnitude map the midi 0..255 to 0.0 to 1.0 range with discrete increments. For the binned value convert the midi 0..255 to minValue->maxValue. I think I had also thought about adding a callback to specific effect_Modules to allow them to override default midi conversion mappings to get this logic out of the main guitar_pedal.cpp, but I clearly never got around to doing this.

I believe that callback is there in the base effect module, unused by any effect

bkshepherd, 2024-12-18:
Yes! MidiCCValueNotification.  I guess that should always be called from guitar_pedal.cpp instead of just being the fall back, and then base_effect_module could have a default implementation as I mentioned above.

GuitarML, 2024-12-18:
I think I get it, thanks! When you say 0 to 255 you mean 0 to 127 right? Isn't 127 the max midi value or am I confused.

bkshepherd, 2024-12-19:
Yes, you are correct 0..127 is the midi range.

haha I get it, the struggle is real bending over.  Also, for those 1590b pedals without the screen midi is really the only way to switch effects etc.

GuitarML, 2024-12-21:
I'm also having trouble using the encoder to change binned item types, it's stuck on the first item when I turn the encoder (you can test on the Modulated Tremolo wave types). Noting it here because it seems like it might be a similar problem to the midi issue.

bkshepherd, 2024-12-28:
This is a separate issue with the Binned item types.  It got broken when someone changed the underlying storage type for parameters to be 32bit from 8bit, some of the conversion functions didn't get updated.  I opened a separate issue to fix this #44 .

bkshepherd, 2024-12-29:
This should all be fixed now

Closed 2024-12-29.

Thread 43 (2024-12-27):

Saving Presets doesn't survive power off

bkshepherd, 2024-12-27:
If you attempt to use Preset values for an effect it seems to work, but if you power off the device, and attempt to load the last saved preset, everything is lost.

bkshepherd, 2024-12-28:
Root cause of this issue is that in guitar_pedal_storage.h the globalEffectsSettings variable was changed to be a pointer to dynamically allocated memory.  This won't serialize properly to QSPI.  When it write to QSPI it will write the value of the pointer to memory, not the contents of the memory located at the pointer.   Thus all the settings get lost.  Changing this back to a fixed sized array would fix the issue, but, that would limit how large of a chunk of memory that could be allocated for presets quite a bit (since this memory would be allocated in DTCMRAM).

Exploring some other potential workarounds before I submit a fix.

bkshepherd, 2024-12-28:
Fixed this for now.

Closed 2024-12-28.

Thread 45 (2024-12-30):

Feature Request: 6 band EQ

xconverge, 2024-12-30:
This is not very exciting but I like using an EQ when I switch between headphones/no headphones.

The controls + UI + implementation shouldn't be too bad at all, 6 filters (cascading/serially?)

peaks at

100 hz
200 hz
400 hz
800 hz
1600 hz
3200 hz

all initialize to middle, and offer a min max of +/-18.f dB, that boost/cut

There are probably a lot of appropriate filter types to get something functional, but here is some reading in my order of thinking it is the right answer:
https://github.com/cycfi/q/blob/master/q_lib/include/q/fx/biquad.hpp or https://github.com/electro-smith/DaisySP-LGPL/blob/main/Source/Filters/biquad.cpp
https://www.w3.org/TR/audio-eq-cookbook
https://forum.electro-smith.com/t/4-band-eq/1883/13
https://ccrma.stanford.edu/~jos/filters/Peaking_Equalizers.html
https://arm-software.github.io/CMSIS_5/DSP/html/group__GEQ5Band.html

Closed 2024-12-30.

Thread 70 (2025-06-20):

Audit DTCMRAM and SRAM usage

xconverge, 2025-06-20:
Together with combined forces, @GuitarML and myself have created modules that use a lot our memory

```
Memory region         Used Size  Region Size  %age Used
           FLASH:          0 GB       128 KB      0.00%
         DTCMRAM:      119428 B       128 KB     91.12%
            SRAM:      406784 B       480 KB     82.76%
      RAM_D2_DMA:       16960 B        32 KB     51.76%
          RAM_D2:          0 GB       256 KB      0.00%
          RAM_D3:          0 GB        64 KB      0.00%
     BACKUP_SRAM:          12 B         4 KB      0.29%
         ITCMRAM:          0 GB        64 KB      0.00%
           SDRAM:    44095008 B        64 MB     65.71%
       QSPIFLASH:          0 GB      7936 KB      0.00%
arm-none-eabi-objcopy -O ihex build/guitarpedal.elf build/guitarpedal.hex
arm-none-eabi-objcopy -O binary -S build/guitarpedal.elf build/guitarpedal.bin
```

I am having issues here and there related to what I _think_ are memory allocation issues due to how little headroom we have left. When I remove modules, the issues go away

Issues I am seeing sometimes (usually only during development, not with the latest build/release on main though):

- lockups at startup
- screen showing artifacts everywhere and it the pedal locking up

My main areas I want to improve:

1. Audit to see if we can move anymore IR, amp module, or nam module data into SDRAM (probably can)
2. Are there any other modules that are using more than their fair share of

xconverge, 2025-06-22:
Ok, progress, the NAM wavenet model is basically 37KB of the DTCMRAM (128 KB) so if I can get that loaded into SDRAM successfully, we are probably good to go

https://github.com/bkshepherd/DaisySeedProjects/pull/71

This PR crashes at startup due to our lack of headroom, but if I comment out the IR module for example, it then loads/boots fine.

I will decouple the work at lowering our DTCMRAM footprint and that PR

xconverge, 2025-06-22:
Here is the top 20 dtcmram entries (ascending, largest at the bottom) and sizes:

```
2405dac0 3420 t Font11x18
24012c00 3424 W _ZN9CloudSeed13ReverbChannel12SetParameterE10Parameter2f
240116a8 3664 W _ZN9CloudSeed13ReverbChannelC1EiiNS_9ChannelLRE
240116a8 3664 W _ZN9CloudSeed13ReverbChannelC2EiiNS_9ChannelLRE
24013ef0 3896 T _ZN10bkshepherd15CloudSeedModule12changePresetEv
2400198c 3920 T main
2001b904 3960 b _ZL12uart_handles
240613d0 4168 T __pow_log_data
240289c4 4348 T _ZN10bkshepherd16PolyOctaveModule11ProcessMonoEf
24027728 4448 W _ZN15OctaveGeneratorC1Ef
24027728 4448 W _ZN15OctaveGeneratorC2Ef
24056008 4804 t _ZN5cycfi1q6detailL12inv_db_tableE
24029f58 4892 T _ZN10bkshepherd11SciFiModule11ProcessMonoEf
2405e81c 4940 t Font16x26
20017f00 8224 B hann
2000aa68 8244 B storage
24020848 8648 W _ZN7wavenet13Wavenet_ModelIfLi1EJNS_11Layer_ArrayIfLi1ELi1ELi2ELi2ELi3ESt16integer_sequenceIiJLi1ELi2ELi4ELi8ELi16ELi32ELi64EEELb0E16NAMMathsProviderN8RTNeural15TanhActivationTIfLi2ES4_EEEENS1_IfLi2ELi1ELi1ELi2ELi3ES2_IiJLi128ELi256ELi512ELi1ELi2ELi4ELi8ELi16ELi32ELi64ELi128ELi256ELi512EEELb1ES4_S7_EEEE7prewarmEv
2400b5c0 9882 T _Z12setupWeightsv
2000d6a0 37664 B rtneural_wavenet
200013b4 38516 B hardware

```

GuitarML, 2025-06-25:
Good info! Thanks for testing all that out.

xconverge, 2025-06-25:
This is the type of stuff I would see when it crashes at startup due to this

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

orenli, 2025-08-09:
I moved 'hardware' to the SRAM section and it seems to work fine.
Saves ~30Kb in DTCMRAM

#define TEXT_SECTION __attribute__((section(".text")))
GuitarPedal125B TEXT_SECTION hardware;

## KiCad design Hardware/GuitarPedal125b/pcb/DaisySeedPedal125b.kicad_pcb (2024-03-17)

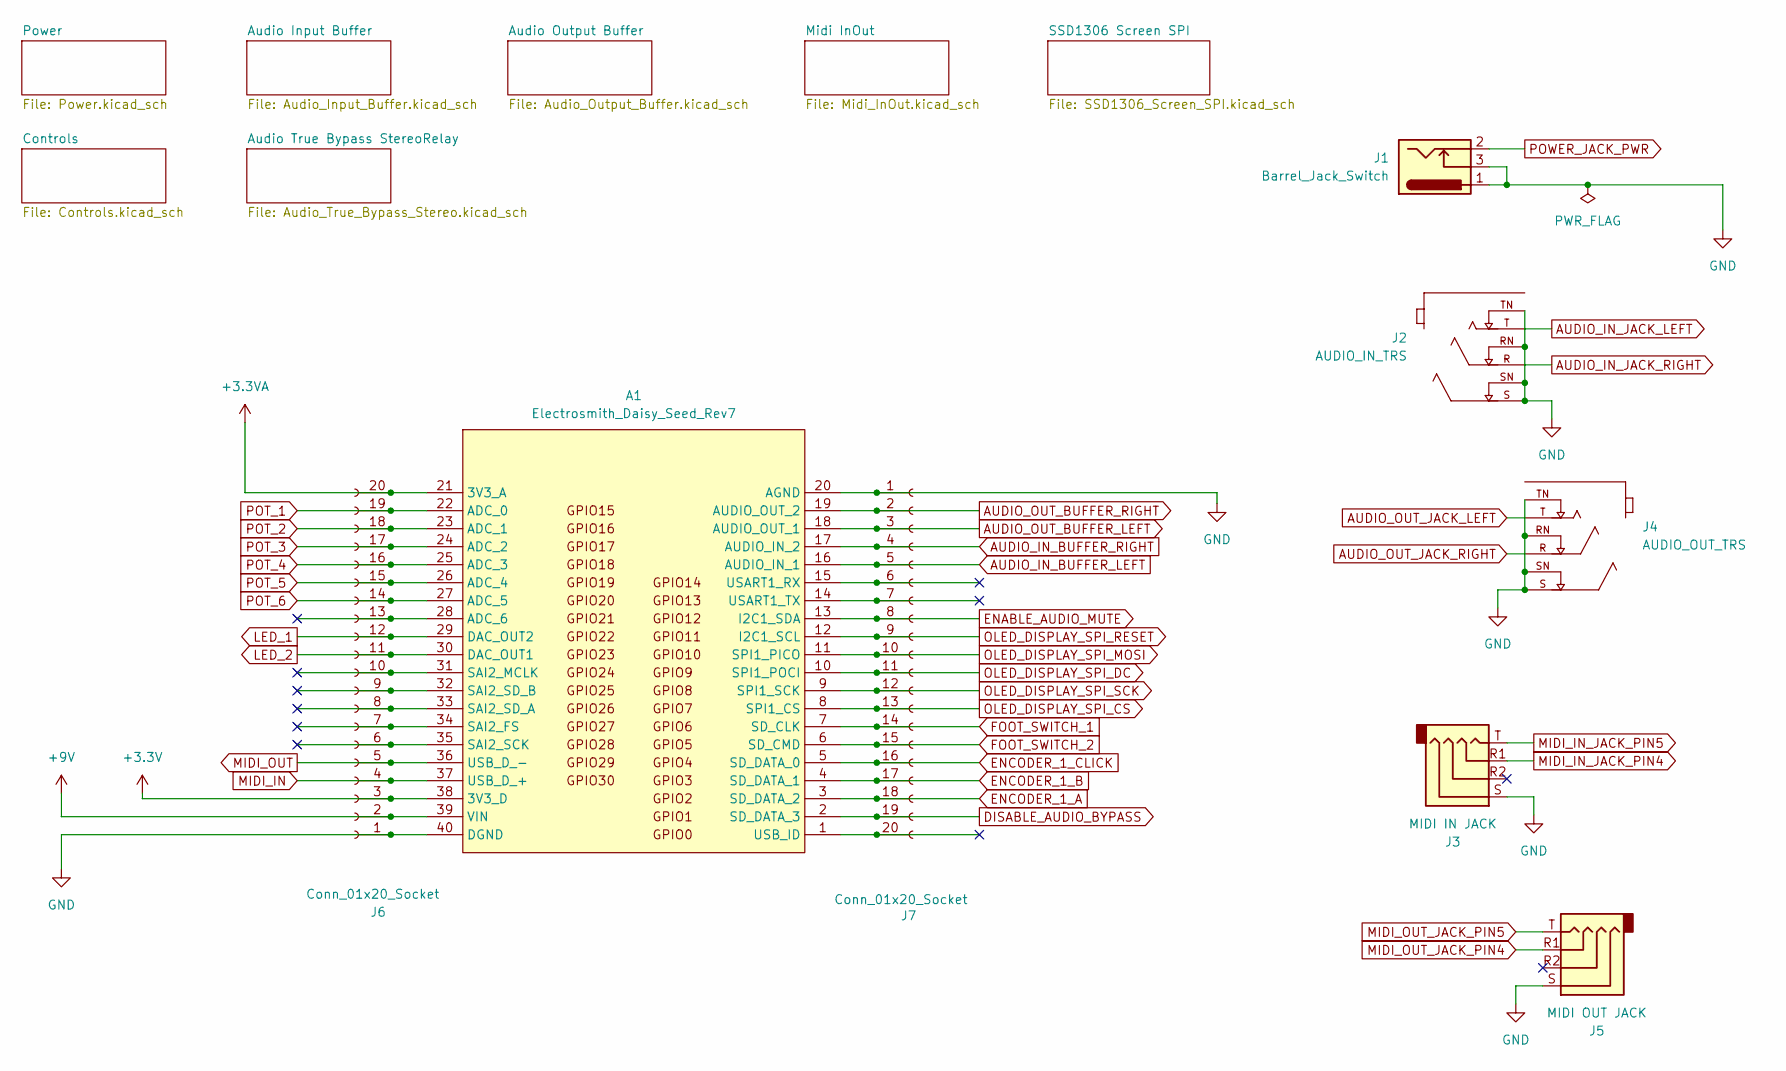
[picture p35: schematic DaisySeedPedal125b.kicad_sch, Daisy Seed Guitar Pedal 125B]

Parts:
A1: Electrosmith_Daisy_Seed_Rev7
J1: Barrel_Jack_Switch; Generic_PowerJack
J2: AUDIO_IN_TRS; NEUTRIK_NMJ6HCD2; PARTREV 26.02.2021
J3: MIDI IN JACK; PJ-320A
J4: AUDIO_OUT_TRS; NEUTRIK_NMJ6HCD2; PARTREV 26.02.2021
J5: MIDI OUT JACK; PJ-320A
J6, J7: Conn_01x20_Socket; PinSocket1x20_P2.54mm_Vertical_JLCPCB

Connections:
+3.3V: A1.38 (3V3_D), J6.3; also elsewhere on the board
+3.3VA: A1.21 (3V3_A), J6.20; also elsewhere on the board
+9V: A1.39 (VIN), J6.2; also elsewhere on the board
AUDIO_IN_BUFFER_LEFT: A1.16 (AUDIO_IN_1), J7.5; also elsewhere on the board
AUDIO_IN_BUFFER_RIGHT: A1.17 (AUDIO_IN_2), J7.4; also elsewhere on the board
AUDIO_IN_JACK_LEFT: J2.T; also elsewhere on the board
AUDIO_IN_JACK_RIGHT: J2.R; also elsewhere on the board
AUDIO_OUT_BUFFER_LEFT: A1.18 (AUDIO_OUT_1), J7.3; also elsewhere on the board
AUDIO_OUT_BUFFER_RIGHT: A1.19 (AUDIO_OUT_2), J7.2; also elsewhere on the board
AUDIO_OUT_JACK_LEFT: J4.T; also elsewhere on the board
AUDIO_OUT_JACK_RIGHT: J4.R; also elsewhere on the board
DISABLE_AUDIO_BYPASS: A1.2 (SD_DATA_3), J7.19; also elsewhere on the board
ENABLE_AUDIO_MUTE: A1.13 (I2C1_SDA), J7.8; also elsewhere on the board
ENCODER_1_A: A1.3 (SD_DATA_2), J7.18; also elsewhere on the board
ENCODER_1_B: A1.4 (SD_DATA_1), J7.17; also elsewhere on the board
ENCODER_1_CLICK: A1.5 (SD_DATA_0), J7.16; also elsewhere on the board
FOOT_SWITCH_1: A1.7 (SD_CLK), J7.14; also elsewhere on the board
FOOT_SWITCH_2: A1.6 (SD_CMD), J7.15; also elsewhere on the board
GND: A1.20 (AGND), A1.40 (DGND), J1.1, J1.3, J2.RN, J2.S, J2.SN, J2.TN, J3.S, J4.RN, J4.S, J4.SN, J4.TN, J5.S, J6.1, J7.1; also elsewhere on the board
LED_1: A1.29 (DAC_OUT2), J6.12; also elsewhere on the board
LED_2: A1.30 (DAC_OUT1), J6.11; also elsewhere on the board
MIDI_IN: A1.37 (USB_D_+), J6.4; also elsewhere on the board
MIDI_IN_JACK_PIN4: J3.R1; also elsewhere on the board
MIDI_IN_JACK_PIN5: J3.T; also elsewhere on the board
MIDI_OUT: A1.36 (USB_D_-), J6.5; also elsewhere on the board
MIDI_OUT_JACK_PIN4: J5.R1; also elsewhere on the board
MIDI_OUT_JACK_PIN5: J5.T; also elsewhere on the board
unnamed: A1.1 (USB_ID), J7.20
unnamed: A1.14 (USART1_TX), J7.7
unnamed: A1.15 (USART1_RX), J7.6
unnamed: A1.28 (ADC_6), J6.13
unnamed: A1.31 (SAI2_MCLK), J6.10
unnamed: A1.32 (SAI2_SD_B), J6.9
unnamed: A1.33 (SAI2_SD_A), J6.8
unnamed: A1.34 (SAI2_FS), J6.7
unnamed: A1.35 (SAI2_SCK), J6.6
OLED_DISPLAY_SPI_CS: A1.8 (SPI1_CS), J7.13; also elsewhere on the board
OLED_DISPLAY_SPI_DC: A1.10 (SPI1_POCI), J7.11; also elsewhere on the board
OLED_DISPLAY_SPI_MOSI: A1.11 (SPI1_PICO), J7.10; also elsewhere on the board
OLED_DISPLAY_SPI_RESET: A1.12 (I2C1_SCL), J7.9; also elsewhere on the board
OLED_DISPLAY_SPI_SCK: A1.9 (SPI1_SCK), J7.12; also elsewhere on the board
POT_1: A1.22 (ADC_0), J6.19; also elsewhere on the board
POT_2: A1.23 (ADC_1), J6.18; also elsewhere on the board
POT_3: A1.24 (ADC_2), J6.17; also elsewhere on the board
POT_4: A1.25 (ADC_3), J6.16; also elsewhere on the board
POT_5: A1.26 (ADC_4), J6.15; also elsewhere on the board
POT_6: A1.27 (ADC_5), J6.14; also elsewhere on the board
POWER_JACK_PWR: J1.2; also elsewhere on the board

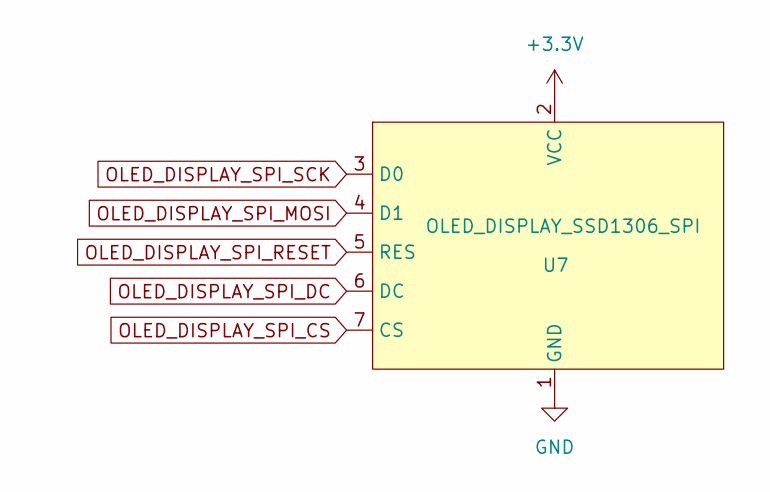
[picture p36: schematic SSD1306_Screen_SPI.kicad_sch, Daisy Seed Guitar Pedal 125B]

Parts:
U7: OLED_DISPLAY_SSD1306_SPI; HiLetgo_OLED_SPI

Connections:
+3.3V: U7.2 (VCC); also elsewhere on the board
GND: U7.1 (GND); also elsewhere on the board
OLED_DISPLAY_SPI_CS: U7.7 (CS); also elsewhere on the board
OLED_DISPLAY_SPI_DC: U7.6 (DC); also elsewhere on the board
OLED_DISPLAY_SPI_MOSI: U7.4 (D1); also elsewhere on the board
OLED_DISPLAY_SPI_RESET: U7.5 (RES); also elsewhere on the board
OLED_DISPLAY_SPI_SCK: U7.3 (D0); also elsewhere on the board

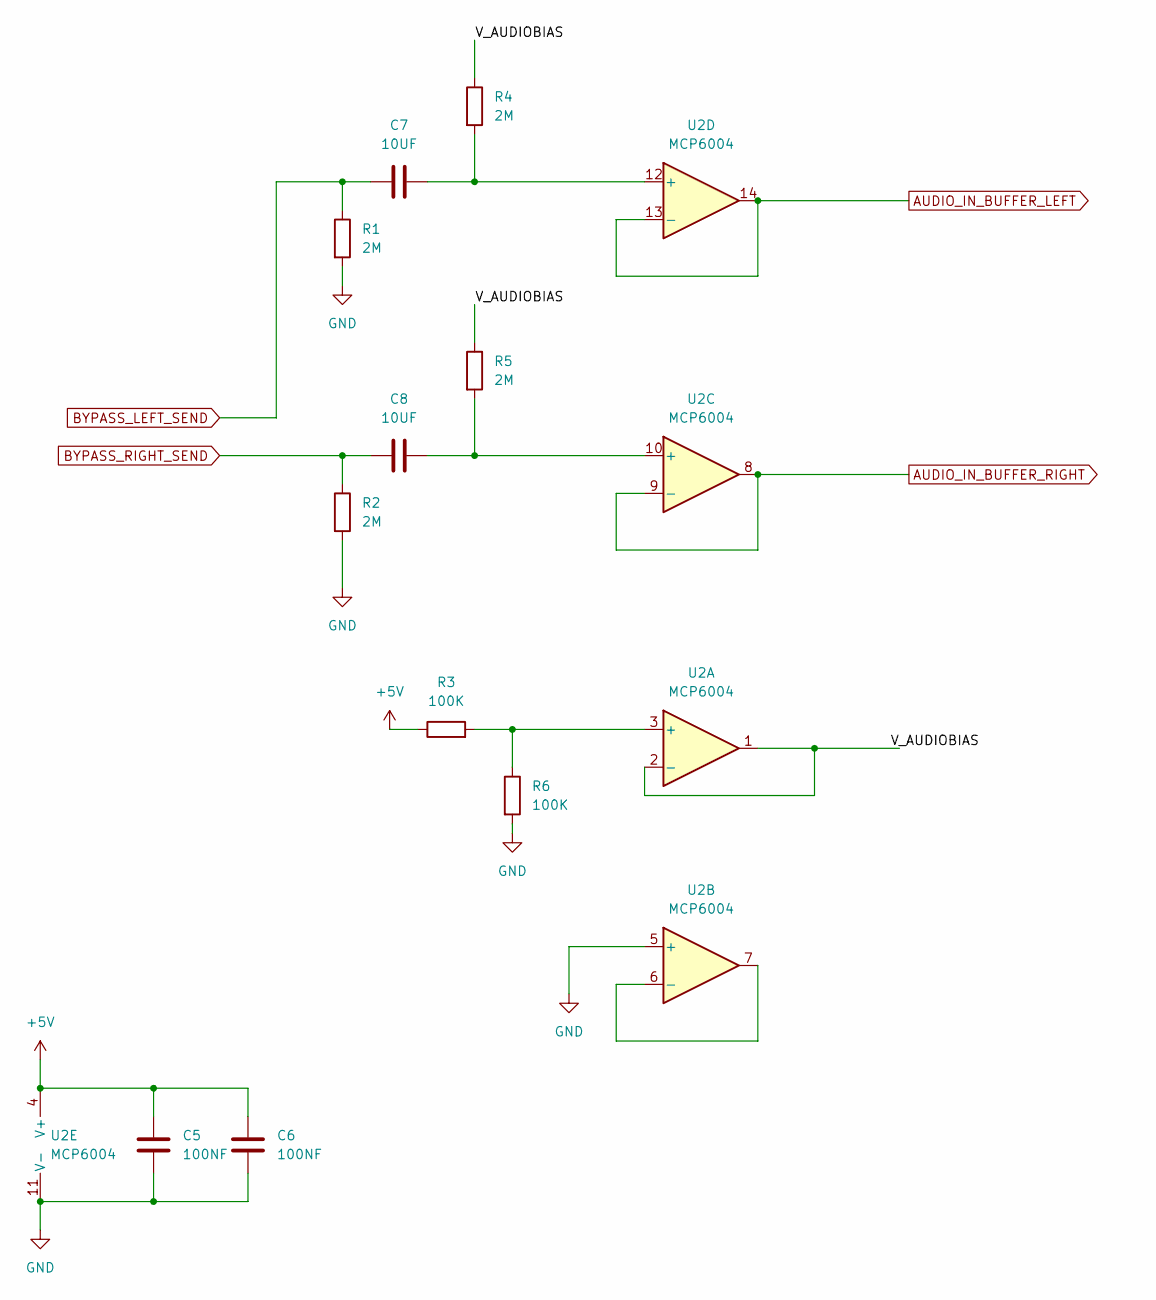
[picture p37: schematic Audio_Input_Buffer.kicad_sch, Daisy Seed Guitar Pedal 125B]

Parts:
C5, C6: 100NF; C_0805_2012Metric
C7, C8: 10UF; C_0805_2012Metric
R1, R2, R4, R5: 2M; R_0805_2012Metric
R3, R6: 100K; R_0805_2012Metric
U2: MCP6004; SOIC-14_3.9x8.7mm_P1.27mm

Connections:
+5V: C5.1, C6.1, R3.1, U2.4 (V+); also elsewhere on the board
/Audio Input Buffer/V_AUDIOBIAS: R4.1, R5.1, U2.1, U2.2 (-)
AUDIO_IN_BUFFER_LEFT: U2.13 (-), U2.14; also elsewhere on the board
AUDIO_IN_BUFFER_RIGHT: U2.8, U2.9 (-); also elsewhere on the board
BYPASS_LEFT_SEND: C7.1, R1.1; also elsewhere on the board
BYPASS_RIGHT_SEND: C8.1, R2.1; also elsewhere on the board
GND: C5.2, C6.2, R1.2, R2.2, R6.2, U2.5 (+), U2.11 (V-); also elsewhere on the board
unnamed: R3.2, R6.1, U2.3 (+)
unnamed: U2.6 (-), U2.7
unnamed: C8.2, R5.2, U2.10 (+)
unnamed: C7.2, R4.2, U2.12 (+)

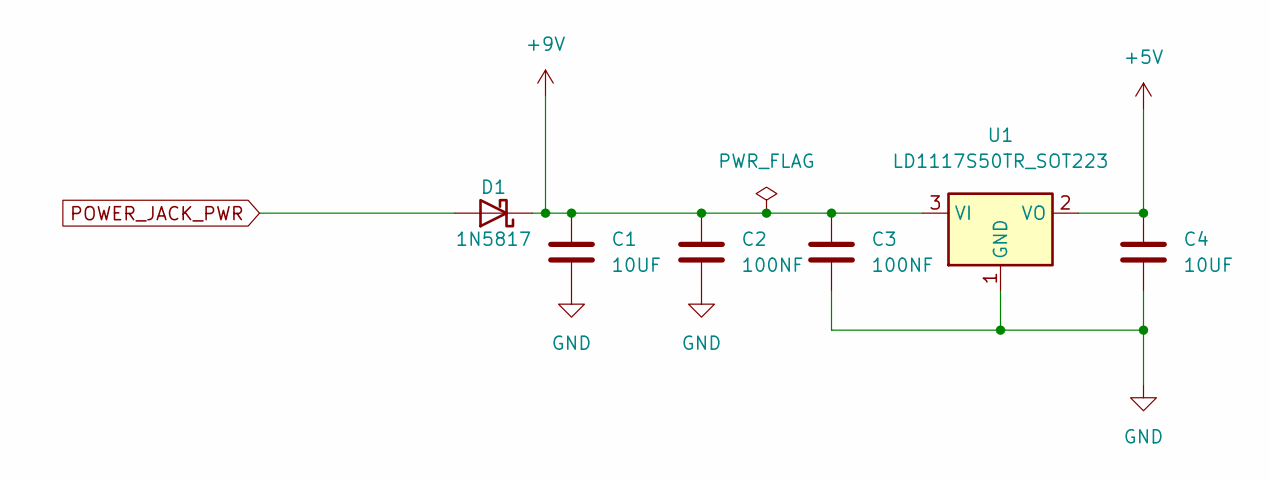
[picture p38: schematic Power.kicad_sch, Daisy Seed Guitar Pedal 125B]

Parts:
C1, C4: 10UF; C_0805_2012Metric
C2, C3: 100NF; C_0805_2012Metric
D1: 1N5817; D_SOD-123
U1: LD1117S50TR_SOT223; SOT-223-3_TabPin2

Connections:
+5V: C4.1, U1.2 (VO); also elsewhere on the board
+9V: C1.1, C2.1, C3.1, D1.1 (K), U1.3 (VI); also elsewhere on the board
GND: C1.2, C2.2, C3.2, C4.2, U1.1 (GND); also elsewhere on the board
POWER_JACK_PWR: D1.2 (A); also elsewhere on the board

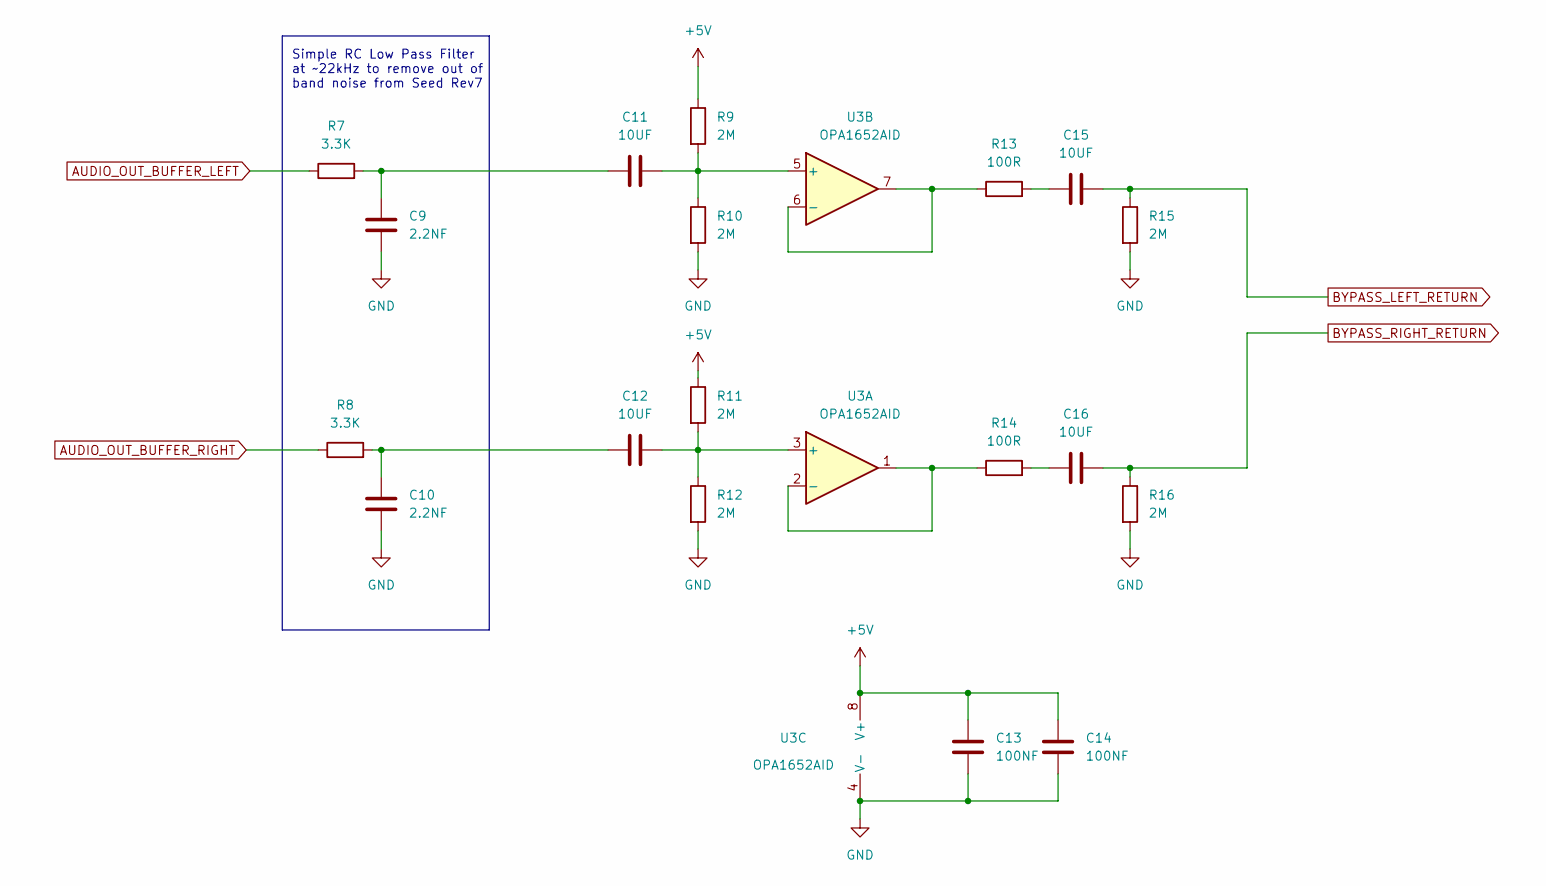
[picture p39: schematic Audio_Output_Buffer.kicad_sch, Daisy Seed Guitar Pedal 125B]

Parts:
C9, C10: 2.2NF; C_0805_2012Metric
C11, C12, C15, C16: 10UF; C_0805_2012Metric
C13, C14: 100NF; C_0805_2012Metric
R7, R8: 3.3K; R_0805_2012Metric
R9, R10, R11, R12, R15, R16: 2M; R_0805_2012Metric
R13, R14: 100R; R_0805_2012Metric
U3: OPA1652AID; SOIC-8_3.9x4.9mm_P1.27mm

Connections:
+5V: C13.1, C14.1, R9.1, R11.1, U3.8 (V+); also elsewhere on the board
AUDIO_OUT_BUFFER_LEFT: R7.1; also elsewhere on the board
AUDIO_OUT_BUFFER_RIGHT: R8.1; also elsewhere on the board
BYPASS_LEFT_RETURN: C15.2, R15.1; also elsewhere on the board
BYPASS_RIGHT_RETURN: C16.2, R16.1; also elsewhere on the board
GND: C9.2, C10.2, C13.2, C14.2, R10.2, R12.2, R15.2, R16.2, U3.4 (V-); also elsewhere on the board
unnamed: C10.1, C12.2, R8.2
unnamed: C9.1, C11.2, R7.2
unnamed: C15.1, R13.2
unnamed: C16.1, R14.2
unnamed: C12.1, R11.2, R12.1, U3.3 (+)
unnamed: R14.1, U3.1, U3.2 (-)
unnamed: C11.1, R9.2, R10.1, U3.5 (+)
unnamed: R13.1, U3.6 (-), U3.7

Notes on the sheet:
Simple RC Low Pass Filter at ~22kHz to remove out of band noise from Seed Rev7

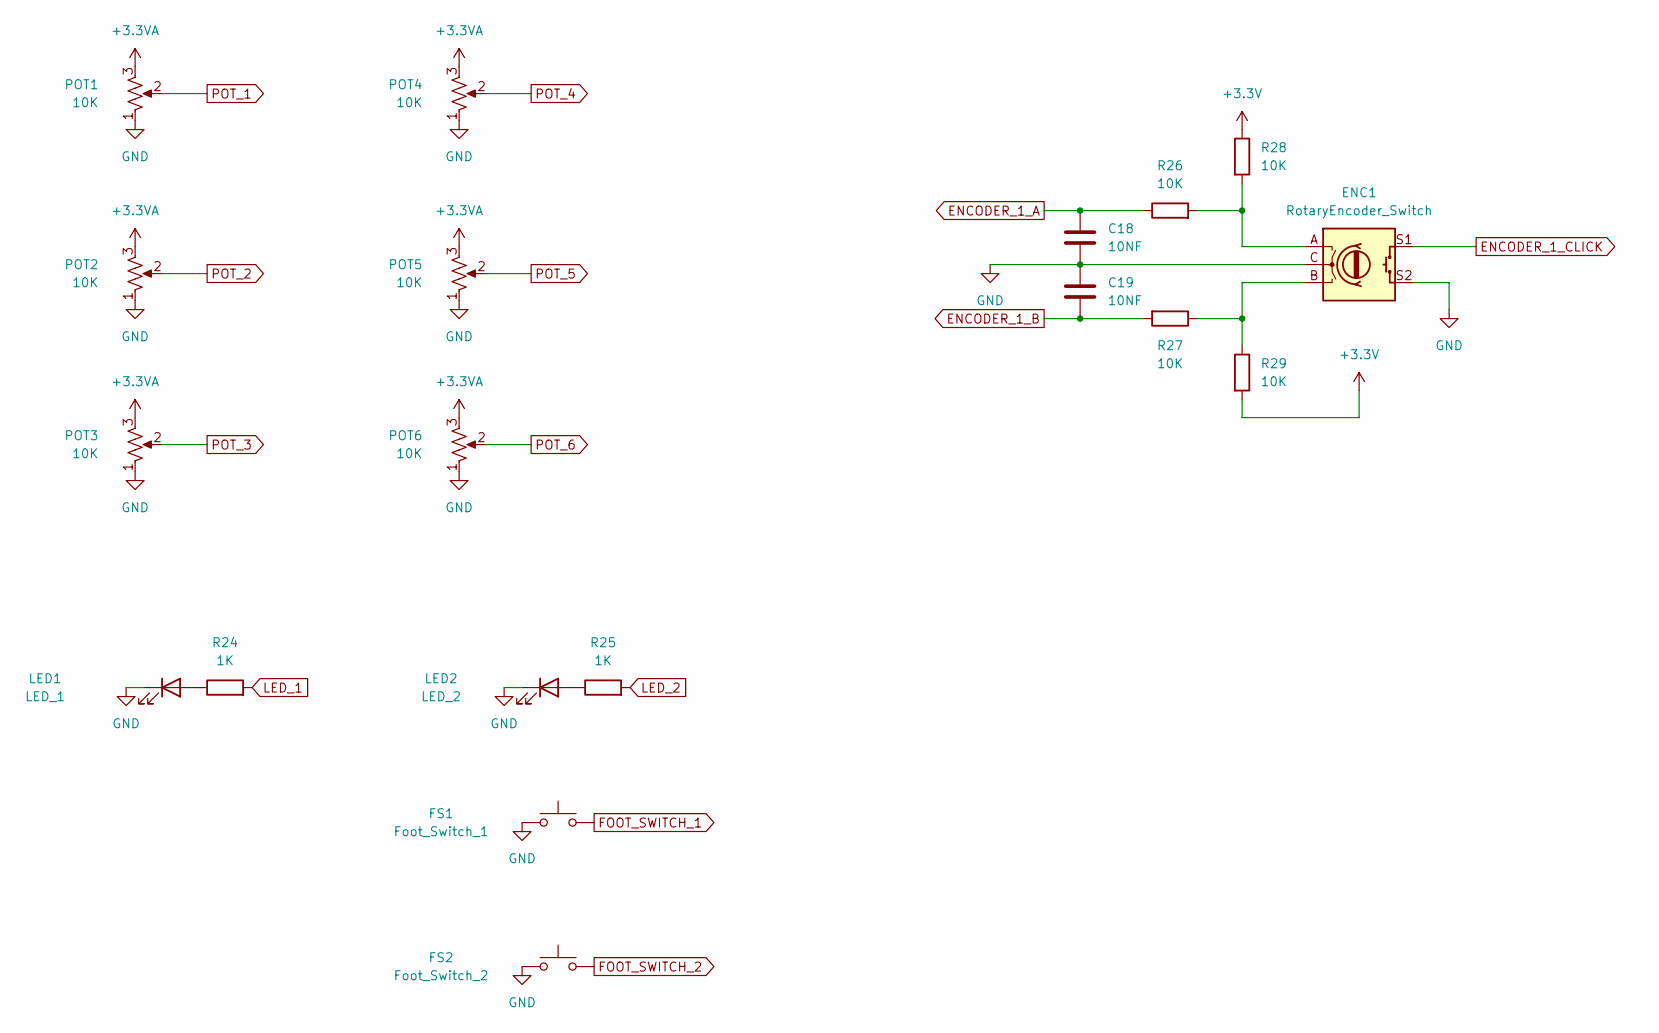
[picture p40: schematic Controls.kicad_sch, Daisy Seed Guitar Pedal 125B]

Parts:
C18, C19: 10NF; C_0805_2012Metric
ENC1: RotaryEncoder_Switch; RotaryEncoder_Alps_EC11E-Switch_Vertical_H20mm
FS1: Foot_Switch_1; PinHeader_1x02_P2.54mm_Vertical
FS2: Foot_Switch_2; PinHeader_1x02_P2.54mm_Vertical
LED1: LED_1; PinHeader_1x02_P2.54mm_Vertical
LED2: LED_2; PinHeader_1x02_P2.54mm_Vertical
POT1, POT2, POT3, POT4, POT5, POT6: 10K; Potentiometer_Bourns_PRS11R
R24, R25: 1K; R_0805_2012Metric
R26, R27, R28, R29: 10K; R_0805_2012Metric

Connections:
+3.3V: R28.1, R29.2; also elsewhere on the board
+3.3VA: POT1.3, POT2.3, POT3.3, POT4.3, POT5.3, POT6.3; also elsewhere on the board
ENCODER_1_A: C18.1, R26.1; also elsewhere on the board
ENCODER_1_B: C19.2, R27.2; also elsewhere on the board
ENCODER_1_CLICK: ENC1.S1; also elsewhere on the board
FOOT_SWITCH_1: FS1.2; also elsewhere on the board
FOOT_SWITCH_2: FS2.2; also elsewhere on the board
GND: C18.2, C19.1, ENC1.C, ENC1.S2, FS1.1, FS2.1, LED1.1 (K), LED2.1 (K), POT1.1, POT2.1, POT3.1, POT4.1, POT5.1, POT6.1; also elsewhere on the board
LED_1: R24.2; also elsewhere on the board
LED_2: R25.2; also elsewhere on the board
unnamed: ENC1.A, R26.2, R28.2
unnamed: ENC1.B, R27.1, R29.1
unnamed: LED1.2 (A), R24.1
unnamed: LED2.2 (A), R25.1
POT_1: POT1.2; also elsewhere on the board
POT_2: POT2.2; also elsewhere on the board
POT_3: POT3.2; also elsewhere on the board
POT_4: POT4.2; also elsewhere on the board
POT_5: POT5.2; also elsewhere on the board
POT_6: POT6.2; also elsewhere on the board

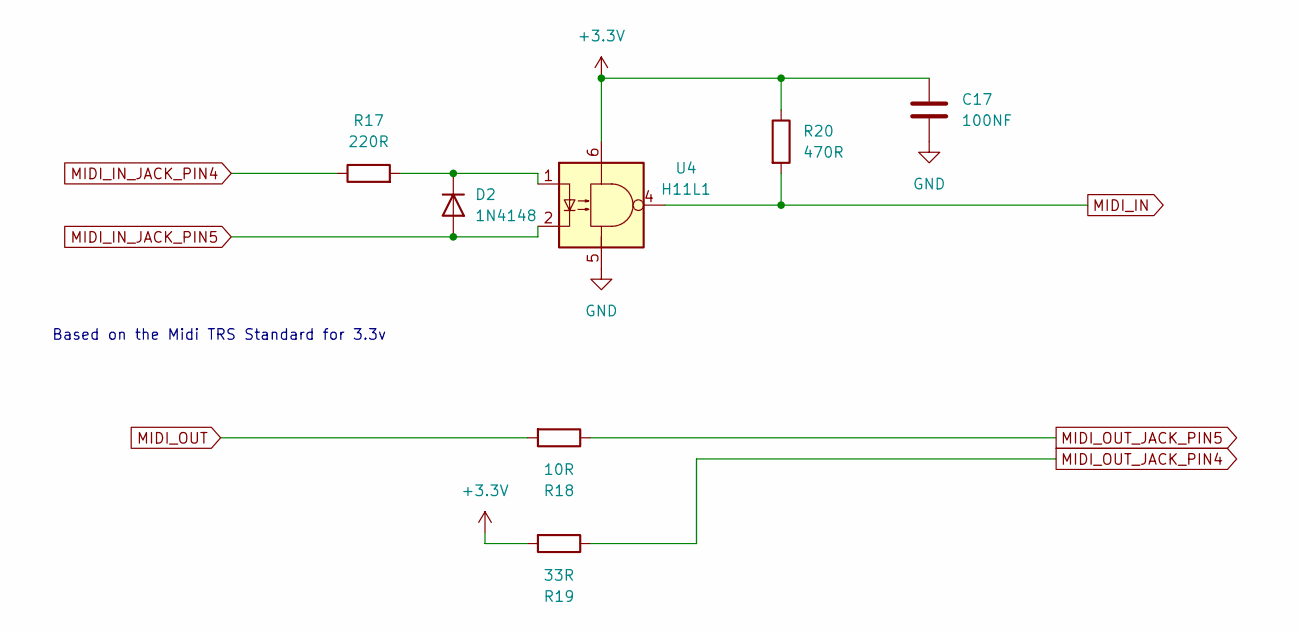
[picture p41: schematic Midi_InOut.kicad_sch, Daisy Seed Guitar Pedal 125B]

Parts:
C17: 100NF; C_0805_2012Metric
D2: 1N4148; D_SOD-123
R17: 220R; R_0805_2012Metric
R18: 10R; R_0805_2012Metric
R19: 33R; R_0805_2012Metric
R20: 470R; R_0805_2012Metric
U4: H11L1; SOP-6_2.54mm

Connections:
+3.3V: C17.1, R19.2, R20.1, U4.6; also elsewhere on the board
GND: C17.2, U4.5; also elsewhere on the board
MIDI_IN: R20.2, U4.4; also elsewhere on the board
MIDI_IN_JACK_PIN4: R17.1; also elsewhere on the board
MIDI_IN_JACK_PIN5: D2.2 (A), U4.2; also elsewhere on the board
MIDI_OUT: R18.2; also elsewhere on the board
MIDI_OUT_JACK_PIN4: R19.1; also elsewhere on the board
MIDI_OUT_JACK_PIN5: R18.1; also elsewhere on the board
unnamed: D2.1 (K), R17.2, U4.1

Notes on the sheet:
Based on the Midi TRS Standard for 3.3v

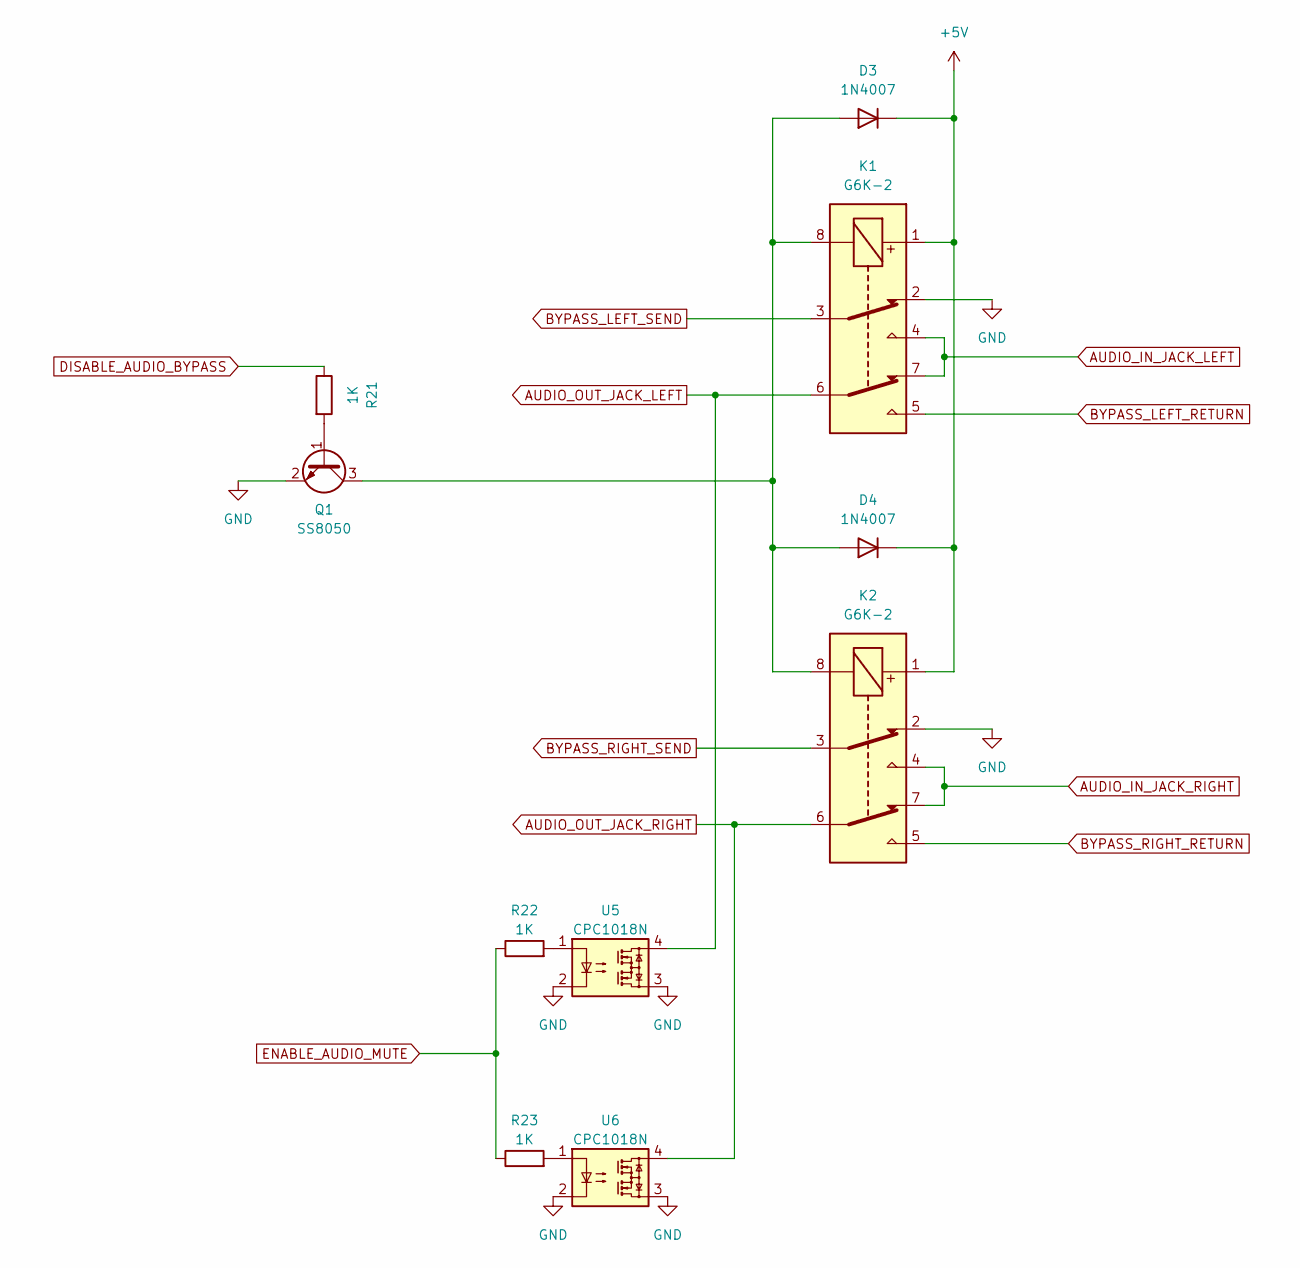
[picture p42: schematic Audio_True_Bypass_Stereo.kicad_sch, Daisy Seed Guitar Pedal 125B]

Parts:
D3, D4: 1N4007; D_SOD-123F
K1, K2: G6K-2; Relay_DPDT_Omron_G6K-2G-Y
Q1: SS8050; SOT-23-3
R21, R22, R23: 1K; R_0805_2012Metric
U5, U6: CPC1018N; SOP-4_3.8x4.1mm_P2.54mm

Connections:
+5V: D3.1 (K), D4.1 (K), K1.1, K2.1; also elsewhere on the board
AUDIO_IN_JACK_LEFT: K1.4, K1.7; also elsewhere on the board
AUDIO_IN_JACK_RIGHT: K2.4, K2.7; also elsewhere on the board
AUDIO_OUT_JACK_LEFT: K1.6, U5.4; also elsewhere on the board
AUDIO_OUT_JACK_RIGHT: K2.6, U6.4; also elsewhere on the board
BYPASS_LEFT_RETURN: K1.5; also elsewhere on the board
BYPASS_LEFT_SEND: K1.3; also elsewhere on the board
BYPASS_RIGHT_RETURN: K2.5; also elsewhere on the board
BYPASS_RIGHT_SEND: K2.3; also elsewhere on the board
DISABLE_AUDIO_BYPASS: R21.1; also elsewhere on the board
ENABLE_AUDIO_MUTE: R22.1, R23.1; also elsewhere on the board
GND: K1.2, K2.2, Q1.2 (E), U5.2, U5.3, U6.2, U6.3; also elsewhere on the board
unnamed: D3.2 (A), D4.2 (A), K1.8, K2.8, Q1.3 (C)
unnamed: Q1.1 (B), R21.2
unnamed: R22.2, U5.1
unnamed: R23.2, U6.1

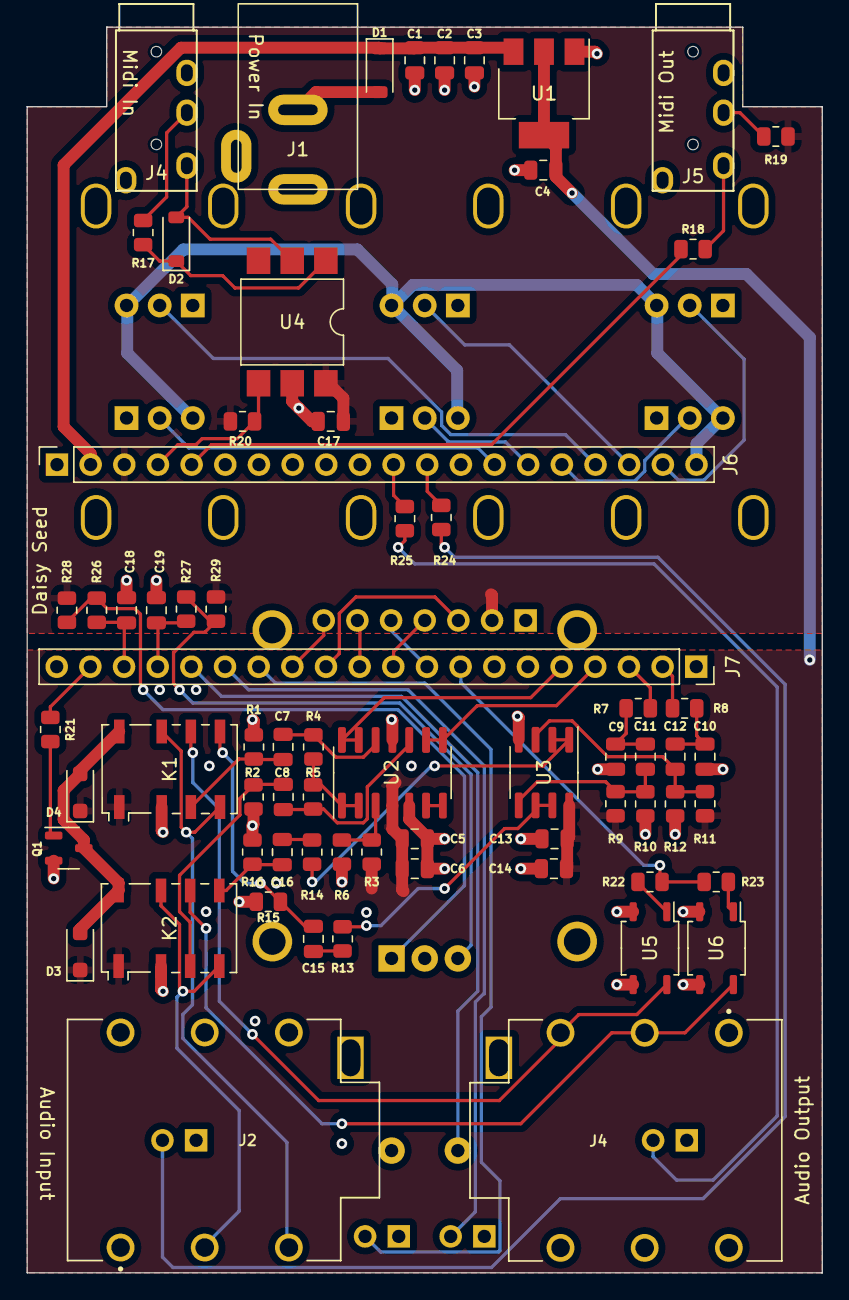
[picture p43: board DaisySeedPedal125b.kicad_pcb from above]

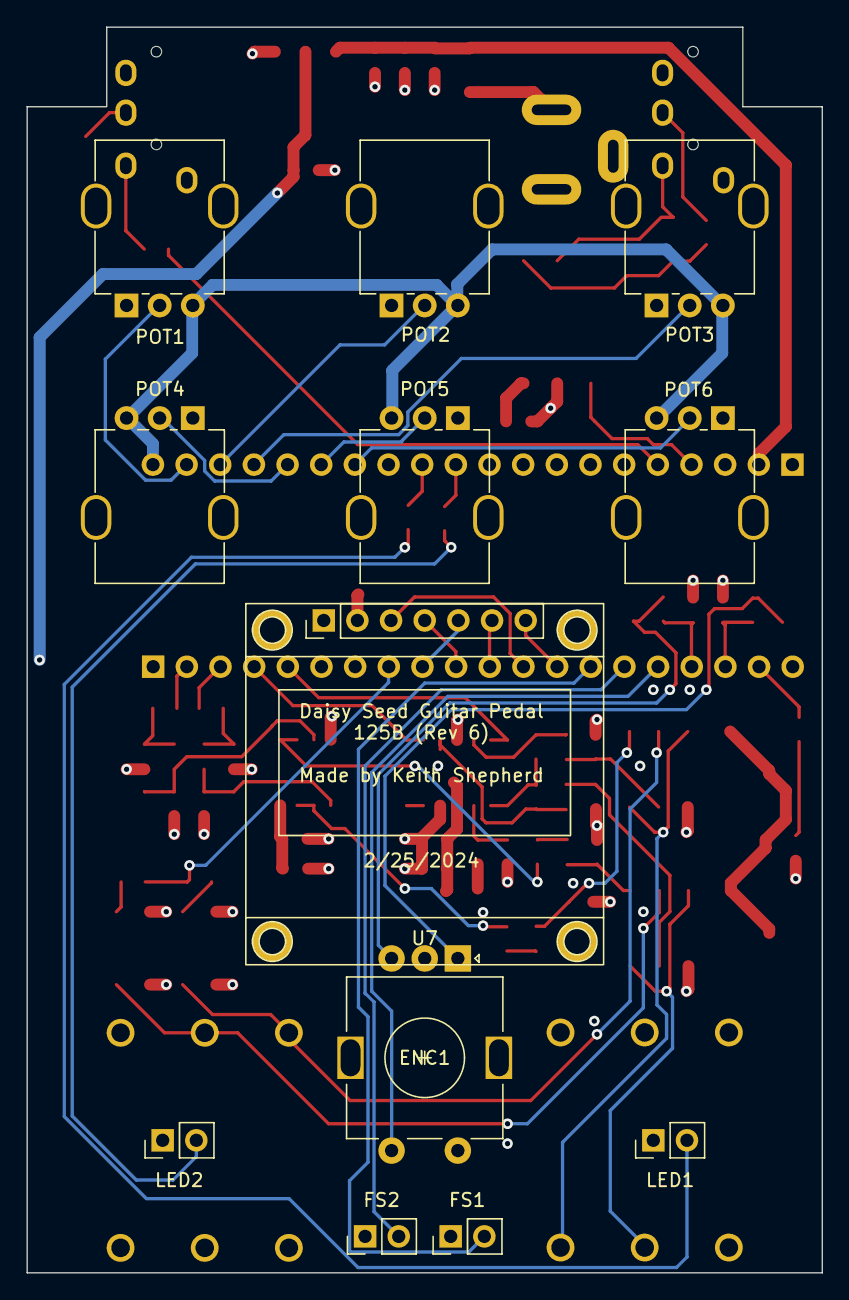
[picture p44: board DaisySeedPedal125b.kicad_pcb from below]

Board: 4 copper layers, 60.0 x 94.0 mm, 80 parts (12 on the bottom side), 66 nets.

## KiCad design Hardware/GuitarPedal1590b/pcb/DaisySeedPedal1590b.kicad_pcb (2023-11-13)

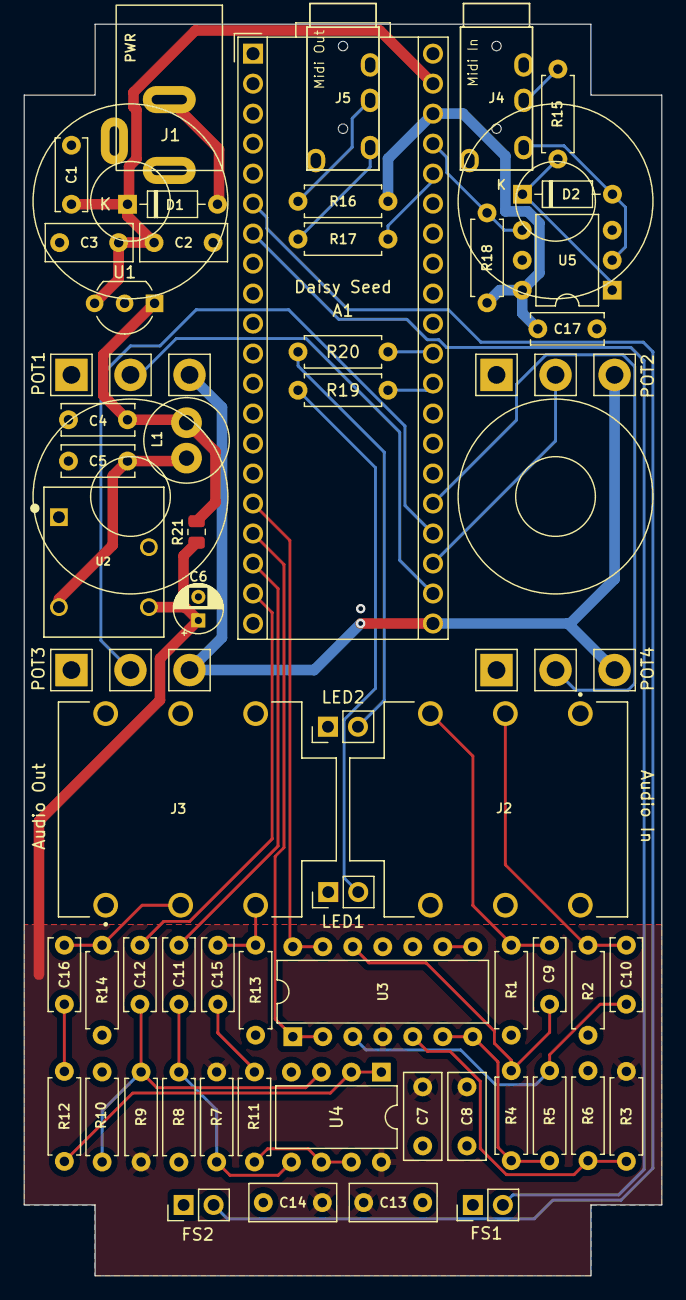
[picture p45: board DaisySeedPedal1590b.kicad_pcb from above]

Board: 4 copper layers, 54.0 x 106.0 mm, 60 parts (0 on the bottom side), 44 nets.

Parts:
A1: Electrosmith_Daisy_Seed_Rev4; Electrosmith_Daisy_Seed
C1, C4, C5, C9, C10, C11, C12, C15, C16: 10UF; C_Disc_D6.0mm_W2.5mm_P5.00mm
C2, C3, C7, C8, C13, C14: 100NF; C_Rect_L7.2mm_W3.0mm_P5.00mm_FKS2_FKP2_MKS2_MKP2
C6: 22UF; CP_Radial_D4.0mm_P2.00mm
C17: 100NF; C_Disc_D6.0mm_W2.5mm_P5.00mm
D1: 1N5817; D_DO-35_SOD27_P7.62mm_Horizontal
D2: 1N4148; D_DO-35_SOD27_P7.62mm_Horizontal
FS1: Foot_Switch_1; PinHeader_1x02_P2.54mm_Vertical
FS2: Foot_Switch_2; PinHeader_1x02_P2.54mm_Vertical
J1: Barrel_Jack; Generic_PowerJack
J2: AUDIO_IN_TRS; NEUTRIK_NMJ6HCD2
J3: AUDIO_OUT_TRS; NEUTRIK_NMJ6HCD2
J4: MIDI IN JACK; TRRS-PJ-320A
J5: MIDI OUT JACK; TRRS-PJ-320A
L1: 2.2uH; L_Radial_D7.0mm_P3.00mm
LED1: LED_1; PinHeader_1x02_P2.54mm_Vertical
LED2: LED_2; PinHeader_1x02_P2.54mm_Vertical
POT1, POT2, POT3, POT4: 10K; Pot_RightAngle_LongPin_16mm
R1, R2, R4, R5, R7, R8, R9, R10, R13, R14: 2M; R_Axial_DIN0207_L6.3mm_D2.5mm_P7.62mm_Horizontal
R3, R6: 100K; R_Axial_DIN0207_L6.3mm_D2.5mm_P7.62mm_Horizontal
R11, R12: 100R; R_Axial_DIN0207_L6.3mm_D2.5mm_P7.62mm_Horizontal
R15: 220R; R_Axial_DIN0207_L6.3mm_D2.5mm_P7.62mm_Horizontal
R16: 33R; R_Axial_DIN0207_L6.3mm_D2.5mm_P7.62mm_Horizontal
R17: 10R; R_Axial_DIN0207_L6.3mm_D2.5mm_P7.62mm_Horizontal
R18: 470R; R_Axial_DIN0207_L6.3mm_D2.5mm_P7.62mm_Horizontal
R19, R20: 1K; R_Axial_DIN0207_L6.3mm_D2.5mm_P7.62mm_Horizontal
R21: DNP; R_0805_2012Metric
U1: L4931CZ50; TO-92_Inline_Wide
U2: PDS1-S5-S5-D; CONV_PDS1-S5-S5-D
U3: MCP6004; DIP-14_W7.62mm
U4: OPA2134; DIP-8_W7.62mm
U5: H11L1; DIP-6_W7.62mm

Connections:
+3.3V: A1.38 (3V3_D), C17.1, R16.2, R18.1, U5.6
+3.3VA: A1.21 (3V3_A), POT1.3, POT2.3, POT3.3, POT4.3
+5V: C4.1, L1.1, R21.1, U1.1 (VO)
+5V_ISOLATED_POWER: C6.1, C7.1, C8.1, C13.1, C14.1, R3.1, R7.1, R9.1, R21.2, U2.5 (+VO), U3.4 (V+), U4.8 (V+)
+9V: A1.39 (VIN), C1.1, C2.1, C3.1, D1.1 (K), U1.3 (VI)
/Audio Input Buffer/V_AUDIOBIAS: R4.1, R5.1, U3.6 (-), U3.7
/Power/VIN: C5.1, L1.2, U2.4 (VIN)
AUDIO_IN_BUFFER_LEFT: A1.16 (AUDIO_IN_1), U3.13 (-), U3.14
AUDIO_IN_BUFFER_RIGHT: A1.17 (AUDIO_IN_2), U3.1, U3.2 (-)
AUDIO_IN_JACK_LEFT: C9.1, J2.T, R1.1
AUDIO_IN_JACK_RIGHT: C10.1, J2.R, R2.1
AUDIO_OUT_BUFFER_LEFT: A1.18 (AUDIO_OUT_1), C11.2
AUDIO_OUT_BUFFER_RIGHT: A1.19 (AUDIO_OUT_2), C12.2
AUDIO_OUT_JACK_LEFT: C15.2, J3.T, R13.1
AUDIO_OUT_JACK_RIGHT: C16.2, J3.R, R14.1
FOOT_SWITCH_1: A1.7 (SD_CLK), FS1.2
FOOT_SWITCH_2: A1.6 (SD_CMD), FS2.2
GND: A1.20 (AGND), A1.40 (DGND), C1.2, C2.2, C3.2, C4.2, C5.2, C6.2, C7.2, C8.2, C13.2, C14.2, C17.2, FS1.1, FS2.1, J1.1, J1.3, J2.RN, J2.S, J2.SN, J2.TN, J3.RN, J3.S, J3.SN, J3.TN, J4.S, J5.S, LED1.1 (K), LED2.1 (K), POT1.1, POT2.1, POT3.1, POT4.1, R1.2, R2.2, R6.2, R8.2, R10.2, R13.2, R14.2, U1.2 (GND), U2.1 (GND), U2.7 (0V), U3.10 (+), U3.11 (V-), U4.4 (V-), U5.5
LED_1: A1.29 (DAC_OUT2), R19.2
LED_2: A1.30 (DAC_OUT1), R20.2
MIDI_IN: A1.37 (USB_D_+), R18.2, U5.4
MIDI_IN_JACK_PIN4: J4.R1, R15.1
MIDI_IN_JACK_PIN5: D2.2 (A), J4.T, U5.2
MIDI_OUT: A1.36 (USB_D_-), R17.2
MIDI_OUT_JACK_PIN4: J5.R1, R16.1
MIDI_OUT_JACK_PIN5: J5.T, R17.1
unnamed: C15.1, R11.2
unnamed: C16.1, R12.2
unnamed: D2.1 (K), R15.2, U5.1
unnamed: LED1.2 (A), R19.1
unnamed: LED2.2 (A), R20.1
unnamed: C10.2, R5.2, U3.3 (+)
unnamed: R3.2, R6.1, U3.5 (+)
unnamed: U3.8, U3.9 (-)
unnamed: C9.2, R4.2, U3.12 (+)
unnamed: C12.1, R9.2, R10.1, U4.3 (+)
unnamed: R12.1, U4.1, U4.2 (-)
unnamed: C11.1, R7.2, R8.1, U4.5 (+)
unnamed: R11.1, U4.6 (-), U4.7
POT_1: A1.22 (ADC_0), POT1.2
POT_2: A1.23 (ADC_1), POT2.2
POT_3: A1.24 (ADC_2), POT3.2
POT_4: A1.25 (ADC_3), POT4.2
POWER_JACK_PWR: D1.2 (A), J1.2

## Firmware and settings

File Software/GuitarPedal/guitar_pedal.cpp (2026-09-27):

#include "daisysp.h"
#include "guitar_pedal_storage.h"
#include "loaded_effects.h"
#include <string.h>

#include "UI/guitar_pedal_ui.h"
#include "Util/audio_utilities.h"

using namespace daisy;
using namespace daisysp;
using namespace bkshepherd;

// Uncomment the version you are trying to use, by default (and if nothing is
// uncommented), the 125B with 2 footswitch variant will be used

// #define VARIANT_125B
// #define VARIANT_1590B
// #define VARIANT_1590B_SMD
// #define VARIANT_TERRARIUM
// #define VARIANT_FUNBOX

// Store the hardware in SRAM to save DTCMRAM for the dynamic
// variables and buffers, this saves a large amount of DTCMRAM
#define TEXT_SECTION __attribute__((section(".text")))
#if defined(VARIANT_TERRARIUM)
#include "Hardware-Modules/guitar_pedal_terrarium.h"
constexpr bool has_alternate_footswitch = true;
GuitarPedalTerrarium TEXT_SECTION hardware;
#elif defined(VARIANT_1590B)
#include "Hardware-Modules/guitar_pedal_1590b.h"
constexpr bool has_alternate_footswitch = false;
GuitarPedal1590B TEXT_SECTION hardware;
#elif defined(VARIANT_1590B_SMD)
#include "Hardware-Modules/guitar_pedal_1590b-SMD.h"
constexpr bool has_alternate_footswitch = false;
GuitarPedal1590BSMD TEXT_SECTION hardware;
#elif defined(VARIANT_FUNBOX)
#include "Hardware-Modules/guitar_pedal_funbox.h"
constexpr bool has_alternate_footswitch = true;
GuitarPedalFunbox TEXT_SECTION hardware;
#else
#include "Hardware-Modules/guitar_pedal_125b.h"
constexpr bool has_alternate_footswitch = true;
GuitarPedal125B TEXT_SECTION hardware;
#endif

// Persistant Storage
PersistentStorage<Settings> storage(hardware.seed.qspi);

// Effect Related Variables
int availableEffectsCount = 0;
BaseEffectModule **availableEffects = nullptr;
int activeEffectID = 0;
int prevActiveEffectID = 0;
int tunerModuleIndex = -1;
BaseEffectModule *activeEffect = nullptr;

// UI Related Variables
GuitarPedalUI guitarPedalUI;

// Hardware Related Variables
bool useDebugDisplay = false;
bool effectOn = false;

bool muteOn = false;
float muteOffTransitionTimeInSeconds = 0.02f;
int muteOffTransitionTimeInSamples;
int samplesTilMuteOff;

bool bypassOn = false;
float bypassToggleTransitionTimeInSeconds = 0.01f;
int bypassToggleTransitionTimeInSamples;
int samplesTilBypassToggle;

uint32_t lastTimeStampUS;
float secondsSinceStartup = 0.0f;

bool needToSaveSettingsForActiveEffect = false;
uint32_t last_save_time; // Time we last set it

struct AutoSaveEffectState {
    uint32_t observedParameterChangeCount;
    uint32_t lastParameterChangeTime;
    bool pending;
};

AutoSaveEffectState *autoSaveEffectStates = nullptr;
uint32_t last_auto_save_check_time = 0;
constexpr uint32_t kAutoSaveDebounceMs = 5000;
constexpr uint32_t kAutoSaveCheckIntervalMs = 50;

// Used to debounce quick switching to/from the tuner
bool ignoreBypassSwitchUntilNextActuation = false;
bool effectActiveBeforeQuickSwitch = false;

// Time we last changed effect
uint32_t last_effect_change_time;

// Pot Monitoring Variables
bool knobValuesInitialized = false;
float knobValueDeadZone = 0.05f; // Dead zone on both ends of the raw knob range
float knobValueChangeTolerance = 1.0f / 256.0f;
float knobValueIdleTimeInSeconds = 1.0f;
int knobValueIdleTimeInSamples;
bool *knobValueCacheChanged = nullptr;
float *knobValueCache = nullptr;
int *knobValueSamplesTilIdle = nullptr;

// Switch Monitoring Variables
float switchEnabledIdleTimeInSeconds = 2.0f;
int switchEnabledIdleTimeInSamples;
bool *switchEnabledCache = nullptr;
bool *switchDoubleEnabledCache = nullptr;
int *switchEnabledSamplesTilIdle = nullptr;
bool alternateHeldFor1SecondTriggered = false;

// Tempo
bool needToChangeTempo = false;
uint32_t globalTempoBPM = 0;

// Set when an alternate footswitch event may have changed the active
// effect's own parameters from inside itself (e.g. EffectChain's
// footswitch-toggle mode flipping a slot's "On" parameter). The menu's
// per-tick writeback loop would otherwise silently revert that change on the
// next UpdateUI(), so the main loop must refresh the UI's cached values
// first - see the needToChangeTempo handling below for the same pattern.
bool needToRefreshMenuParameterValues = false;

bool isCrossFading = false;
bool isCrossFadingForward = true; // True goes Source->Target, False goes Target->Source
CrossFade crossFaderLeft, crossFaderRight;
float crossFaderTransitionTimeInSeconds = 0.1f;
int crossFaderTransitionTimeInSamples;
int samplesTilCrossFadingComplete;
CpuLoadMeter cpuLoadMeter;

// Effect switch requested from the audio callback (interrupt context).
// Switching effects rebuilds the UI menus with heap new/delete, which is not
// safe from the interrupt (allocator reentrancy, and the main loop may be
// iterating those menu allocations), so the request is deferred to the main
// loop. -1 means no switch is pending.
volatile int pendingEffectIDFromAudioCallback = -1;

void SetActiveEffect(int effectID);

static void AudioCallback(AudioHandle::InputBuffer in, AudioHandle::OutputBuffer out, size_t size) {
    cpuLoadMeter.OnBlockStart();

    // Process Audio
    float inputLeft;
    float inputRight;

    // Default LEDs are off
    float led1Brightness = 0.0f;
    float led2Brightness = 0.0f;

    // Handle Inputs
    hardware.ProcessAnalogControls();
    hardware.ProcessDigitalControls();
    guitarPedalUI.GenerateUIEvents();

    // Get a handle to the persitance storage settings
    Settings &settings = storage.GetSettings();

    // Process the Pots
    float knobValueRaw;

    for (int i = 0; i < hardware.GetKnobCount(); i++) {
        knobValueRaw = hardware.GetKnobValue(i);

        // Knobs don't perfectly return values in the 0.0f - 1.0f range
        // so we will add some deadzone to either end of the knob and remap values into
        // a full 0.0f - 1.0f range.
        if (knobValueRaw < knobValueDeadZone) {
            knobValueRaw = 0.0f;
        } else if (knobValueRaw > (1.0f - knobValueDeadZone)) {
            knobValueRaw = 1.0f;
        } else {
            knobValueRaw = (knobValueRaw - knobValueDeadZone) / (1.0f - (2.0f * knobValueDeadZone));
        }

        if (!knobValuesInitialized) {
            // Initialize the knobs for the first time to whatever the current knob placements are
            knobValueCacheChanged[i] = false;
            knobValueSamplesTilIdle[i] = 0;
            knobValueCache[i] = knobValueRaw;
        } else {
            // If the knobs are initialized handle monitor them for changes.
            if (knobValueSamplesTilIdle[i] > 0) {
                knobValueSamplesTilIdle[i] -= size;

                if (knobValueSamplesTilIdle[i] <= 0) {
                    knobValueSamplesTilIdle[i] = 0;
                    knobValueCacheChanged[i] = false;
                }
            }

            bool knobValueChangedToleranceMet = false;

            if (knobValueRaw > (knobValueCache[i] + knobValueChangeTolerance) ||
                knobValueRaw < (knobValueCache[i] - knobValueChangeTolerance)) {
                knobValueChangedToleranceMet = true;
                knobValueCacheChanged[i] = true;
                knobValueSamplesTilIdle[i] = knobValueIdleTimeInSamples;
            }

            if (knobValueChangedToleranceMet || knobValueCacheChanged[i]) {
                knobValueCache[i] = knobValueRaw;
            }
        }
    }

    // Store the previous value of the effect bypass so that we can determine if
    // we need to perform a toggle at the end of processing the switches
    bool oldEffectOn = effectOn;

    // Process potential footswitch actions before the main switch processing loop
    if (has_alternate_footswitch) {
        // Handle the scenario where have 2 footswitches

        // If both footswitches are down, save the parameters for this effect to
        // persistant storage If there is only one footswitch, it will do
        // parameter saving here when held instead of tuner quick switching later
        if (hardware.switches[hardware.GetPreferredSwitchIDForSpecialFunctionType(SpecialFunctionType::Bypass)].TimeHeldMs() > 2000 &&
            hardware.switches[hardware.GetPreferredSwitchIDForSpecialFunctionType(SpecialFunctionType::Alternate)].TimeHeldMs() >
                2000 &&
            !guitarPedalUI.IsShowingSavingSettingsScreen() && !ignoreBypassSwitchUntilNextActuation) {

            needToSaveSettingsForActiveEffect = true;
            ignoreBypassSwitchUntilNextActuation = true;
        }

        // If bypass is held for 2 seconds and alternate footswitch is not
        // pressed (not trying to save) then perform an action
        if (hardware.switches[hardware.GetPreferredSwitchIDForSpecialFunctionType(SpecialFunctionType::Bypass)].TimeHeldMs() > 2000 &&
            !hardware.switches[hardware.GetPreferredSwitchIDForSpecialFunctionType(SpecialFunctionType::Alternate)].Pressed() &&
            !ignoreBypassSwitchUntilNextActuation) {

            // If we have a screen and there is a tuner module, we quick switch
            // to it, otherwise we just cycle through the effects.
            // The actual switch is deferred to the main loop (it isn't safe
            // from this interrupt); SetActiveEffect syncs the new effect's
            // enabled state with effectOn when the switch is applied.
            if (hardware.SupportsDisplay() && tunerModuleIndex >= 0) {
                // Start the quick switch to the tuner
                if (activeEffectID == tunerModuleIndex) {
                    // Set back the active effect before the quick switch
                    pendingEffectIDFromAudioCallback = prevActiveEffectID;

                    // Restore the effect state from when we quick switched, this is an
                    // inverse because the act of holding the switch caused the state to
                    // chnage due to the rising edge being detected
                    effectOn = !effectActiveBeforeQuickSwitch;
                } else {
                    // Store if effect is on or not when quick switching
                    effectActiveBeforeQuickSwitch = effectOn;

                    // Switch to tuner and force it to be enabled
                    pendingEffectIDFromAudioCallback = tunerModuleIndex;
                    effectOn = true;
                }
                ignoreBypassSwitchUntilNextActuation = true;
            } else {
                // Cycle to the next effect
                int newActiveEffectId = activeEffectID + 1;

                // Skip over the tuner if there is no screen
                if (newActiveEffectId == tunerModuleIndex) {
                    newActiveEffectId++;
                }

                if (newActiveEffectId > availableEffectsCount - 1) {
                    newActiveEffectId = 0;
                }

                pendingEffectIDFromAudioCallback = newActiveEffectId;

                effectOn = false;

                ignoreBypassSwitchUntilNextActuation = true;
            }
        }

        // Disable quick switching until the footswitch is released to prevent infinite switching
        // also prevents saving from toggling quick switch.
        if (ignoreBypassSwitchUntilNextActuation &&
            !hardware.switches[hardware.GetPreferredSwitchIDForSpecialFunctionType(SpecialFunctionType::Bypass)].Pressed()) {
            ignoreBypassSwitchUntilNextActuation = false;
        }
    } else {
        // Handle the scenario where we only have 1 footswitch
        if (hardware.switches[hardware.GetPreferredSwitchIDForSpecialFunctionType(SpecialFunctionType::Bypass)].TimeHeldMs() > 2000 &&
            !guitarPedalUI.IsShowingSavingSettingsScreen()) {
            needToSaveSettingsForActiveEffect = true;
        }
    }

    // Process the switches
    for (int i = 0; i < hardware.GetSwitchCount(); i++) {
        bool switchPressed = hardware.switches[i].RisingEdge();

        // If this is the bypass switch, check for a bypass transition already
        // in progress (isCrossFading), and toggle the effect if the switch is
        // pressed
        if (!ignoreBypassSwitchUntilNextActuation && !isCrossFading &&
            i == hardware.GetPreferredSwitchIDForSpecialFunctionType(SpecialFunctionType::Bypass) && switchPressed) {
            effectOn = !effectOn;
        }

        if (effectOn && switchPressed && i == hardware.GetPreferredSwitchIDForSpecialFunctionType(SpecialFunctionType::Alternate)) {
            activeEffect->AlternateFootswitchPressed();
            needToRefreshMenuParameterValues = true;
        }

        bool switchReleased = hardware.switches[i].FallingEdge();
        if (switchReleased && i == hardware.GetPreferredSwitchIDForSpecialFunctionType(SpecialFunctionType::Alternate)) {
            alternateHeldFor1SecondTriggered = false;
        }
        if (effectOn && switchReleased && i == hardware.GetPreferredSwitchIDForSpecialFunctionType(SpecialFunctionType::Alternate)) {
            activeEffect->AlternateFootswitchReleased();
            needToRefreshMenuParameterValues = true;
        }
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
int main(void) {
    const size_t blockSize = 48;
    const bool boost = true; // true enables cpu boost (480Mhz instead of 400Mhz)

    hardware.Init(blockSize, boost);

    const float sample_rate = hardware.AudioSampleRate();

    // Setup CPU logging of the audio callback
    cpuLoadMeter.Init(sample_rate, blockSize);

    // Set the number of samples to use for the crossfade based on the hardware sample rate
    muteOffTransitionTimeInSamples = hardware.GetNumberOfSamplesForTime(muteOffTransitionTimeInSeconds);
    bypassToggleTransitionTimeInSamples = hardware.GetNumberOfSamplesForTime(bypassToggleTransitionTimeInSeconds);
    crossFaderTransitionTimeInSamples = hardware.GetNumberOfSamplesForTime(crossFaderTransitionTimeInSeconds);

    // Init the Effects Modules
    load_effects(availableEffectsCount, availableEffects);

    for (int i = 0; i < availableEffectsCount; i++) {
        availableEffects[i]->Init(sample_rate);

        if (std::string(availableEffects[i]->GetName()) == std::string("Tuner")) {
            // Store the index for the tuner module so that we can quickswitch
            // to/from it
            tunerModuleIndex = i;
        }
    }

    // Initalize Persistance Storage
    InitPersistantStorage();

    Settings &settings = storage.GetSettings();

    // Load all the effect specific settings
    LoadEffectSettingsFromPersistantStorage();

    // Set the active effect
    activeEffect = availableEffects[settings.globalActiveEffectID];
    activeEffectID = settings.globalActiveEffectID;
    effectOn = settings.globalEffectOn;
    activeEffect->SetEnabled(effectOn);

    // LoadEffectSettingsFromPersistantStorage() above loads every effect's own
    // saved preset 0, in effectList order. An effect that shares a
    // single-instance-only child with another effect (e.g. one
    // DattorroReverbModule referenced from two EffectChains, see README) ends
    // up with whichever of those effects happens to load last, which isn't
    // necessarily the one about to be active. Reloading just the active
    // effect's own preset 0 here makes it the final writer of anything it
    // touches, so it matches what the user actually saved for it. This is a
    // no-op for every parameter that isn't shared (SetParameterRaw/
    // SetParameterAsFloat only call ParameterChanged when a value actually
    // differs from what's already set).
    LoadPresetFromPersistentStorage(activeEffectID, 0);

    autoSaveEffectStates = new AutoSaveEffectState[availableEffectsCount];
    for (int i = 0; i < availableEffectsCount; ++i) {
        autoSaveEffectStates[i] = {availableEffects[i]->GetParameterChangeCount(), 0, false};
    }
    last_auto_save_check_time = System::GetNow();

    // Init the Menu UI System
    if (hardware.SupportsDisplay()) {
        guitarPedalUI.Init();
    }

    // Set up midi if supported.
    if (hardware.SupportsMidi()) {
        hardware.midi.StartReceive();
    }

    // Setup Relay Bypass State
    if (hardware.SupportsTrueBypass() && settings.globalRelayBypassEnabled) {
        bypassOn = !effectOn;
    }

    // Init the Knob Monitoring System
    knobValueCacheChanged = new bool[hardware.GetKnobCount()];
    knobValueCache = new float[hardware.GetKnobCount()];
    knobValueSamplesTilIdle = new int[hardware.GetKnobCount()];
    knobValueIdleTimeInSamples = hardware.GetNumberOfSamplesForTime(knobValueIdleTimeInSeconds);

    // Init the Switch Monitoring System
    switchEnabledCache = new bool[hardware.GetSwitchCount()];
    switchDoubleEnabledCache = new bool[hardware.GetSwitchCount()];
    switchEnabledSamplesTilIdle = new int[hardware.GetSwitchCount()];
    switchEnabledIdleTimeInSamples = hardware.GetNumberOfSamplesForTime(switchEnabledIdleTimeInSeconds);

    for (int i = 0; i < hardware.GetSwitchCount(); i++) {
        switchEnabledCache[i] = false;
        switchDoubleEnabledCache[i] = false;
        switchEnabledSamplesTilIdle[i] = 0;
    }

    // Setup the cross fader. Match the restored effectOn state so the audio
    // path doesn't start silently bypassed/wet relative to what SetEnabled()
    // and the LEDs already reflect above.
    crossFaderLeft.Init();
    crossFaderRight.Init();
    crossFaderLeft.SetPos(effectOn ? 1.0f : 0.0f);
    crossFaderRight.SetPos(effectOn ? 1.0f : 0.0f);

    // start callback
    hardware.StartAdc();
    hardware.StartAudio(AudioCallback);

    // Set initial time stamp
    lastTimeStampUS = System::GetUs();

    // Setup Debug Logging
    // hardware.seed.StartLog();

    while (1) {
        // Handle Clock Time
        uint32_t currentTimeStampUS = System::GetUs();
        uint32_t elapsedTimeStampUS = currentTimeStampUS - lastTimeStampUS;
        lastTimeStampUS = currentTimeStampUS;
        float elapsedTimeInSeconds = (elapsedTimeStampUS / 1000000.0f);
        secondsSinceStartup = secondsSinceStartup + elapsedTimeInSeconds;

        // Apply any effect switch requested by the audio callback. Doing it
        // here (instead of in the interrupt) keeps the UI menu heap
        // allocations off the audio interrupt. This must run before the menu
        // sync below so the menu reflects the switch instead of undoing it.
        if (pendingEffectIDFromAudioCallback >= 0) {
            int pendingID = pendingEffectIDFromAudioCallback;
            pendingEffectIDFromAudioCallback = -1;
            SetActiveEffect(pendingID);
        }

        // Handle Knob Changes
        if (!knobValuesInitialized && secondsSinceStartup > 1.0f) {
            // Let the initial readings of the knob values settle before trying to use them.
            knobValuesInitialized = true;
        }

        if (knobValuesInitialized) {
            for (int i = 0; i < hardware.GetKnobCount(); i++) {
                if (knobValueCacheChanged[i]) {
                    int parameterID = activeEffect->GetMappedParameterIDForKnob(i);

                    if (parameterID != -1) {
                        // Set the new value on the effect parameter directly
                        activeEffect->SetParameterAsMagnitude(parameterID, knobValueCache[i]);

                        // Update the effect parameter on the menu system to reflect the change
                        guitarPedalUI.UpdateActiveEffectParameterValue(parameterID, true);
                    }
                }
            }
        }

        // Handle Global Tempo Changes
        if (needToChangeTempo) {
            activeEffect->SetTempo(globalTempoBPM);
            needToChangeTempo = false;

            // Update the effect parameters on the menu system to reflect any changes
            guitarPedalUI.UpdateActiveEffectParameterValues();
        }

        // An alternate footswitch event may have changed the active effect's
        // own parameters (e.g. EffectChain's footswitch-toggle mode). Refresh
        // the menu's cached values from it before UpdateUI() runs below,
        // otherwise the menu's own writeback would silently revert the change.
        if (needToRefreshMenuParameterValues) {
            needToRefreshMenuParameterValues = false;
            guitarPedalUI.UpdateActiveEffectParameterValues();
        }

        // If alt footswitch held AND encoder turned, iterate to next/previous effect, also throttle the changes
        if (hardware.SupportsEncoder() && has_alternate_footswitch &&
            hardware.switches[hardware.GetPreferredSwitchIDForSpecialFunctionType(SpecialFunctionType::Alternate)].Pressed() &&
            System::GetNow() - last_effect_change_time >= 10) {
            const int encoderIncrement = hardware.encoders[0].Increment();
            if (encoderIncrement != 0) {
                int desiredIndex = activeEffectID + encoderIncrement;
                if (desiredIndex > availableEffectsCount - 1) {
                    desiredIndex = 0;
                } else if (desiredIndex < 0) {
                    desiredIndex = availableEffectsCount - 1;
                }
                SetActiveEffect(desiredIndex);
            }
        }

        if (hardware.SupportsDisplay()) {
            // Handle a Change in the Active Effect from the Menu System

            // Check which effect the Menu system thinks is active
            int menuEffectID = guitarPedalUI.GetSelectedEffectID();
            BaseEffectModule *selectedEffect = availableEffects[menuEffectID];

            // If the effect differs from the active effect, change the active effect
            if (activeEffect != selectedEffect) {
                SetActiveEffect(menuEffectID);
            }
        }

        // Set the latest cpu load to the effect
        activeEffect->SetCPUUsage(cpuLoadMeter.GetAvgCpuLoad());
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

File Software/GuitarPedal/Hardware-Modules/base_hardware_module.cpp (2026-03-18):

#include "base_hardware_module.h"

using namespace daisy;
using namespace bkshepherd;

BaseHardwareModule::BaseHardwareModule()
    : m_supportsStereo(false), m_supportsMidi(false), m_supportsDisplay(false), m_supportsEncoder(false),
      m_supportsTrueBypass(false), m_switchMetaDataParamCount(0) {
    m_switchMetaData = nullptr;
}

BaseHardwareModule::~BaseHardwareModule() {}

void BaseHardwareModule::Init(size_t blockSize, bool boost) {
    // Initialize the hardware.
    seed.Configure();
    seed.Init(boost);

    SetAudioBlockSize(blockSize);
}

void BaseHardwareModule::DelayMs(size_t del) { seed.DelayMs(del); }

void BaseHardwareModule::SetHidUpdateRates() {
    if (!knobs.empty()) {
        for (int i = 0; i < GetKnobCount(); i++) {
            knobs[i].SetSampleRate(AudioCallbackRate());
        }
    }

    if (!leds.empty()) {
        for (int i = 0; i < GetLedCount(); i++) {
            leds[i].SetSampleRate(AudioCallbackRate());
        }
    }
}

void BaseHardwareModule::StartAudio(AudioHandle::InterleavingAudioCallback cb) { seed.StartAudio(cb); }

void BaseHardwareModule::StartAudio(AudioHandle::AudioCallback cb) { seed.StartAudio(cb); }

void BaseHardwareModule::ChangeAudioCallback(AudioHandle::InterleavingAudioCallback cb) { seed.ChangeAudioCallback(cb); }

void BaseHardwareModule::ChangeAudioCallback(AudioHandle::AudioCallback cb) { seed.ChangeAudioCallback(cb); }

void BaseHardwareModule::StopAudio() { seed.StopAudio(); }

void BaseHardwareModule::SetAudioBlockSize(size_t size) {
    seed.SetAudioBlockSize(size);
    SetHidUpdateRates();
}

size_t BaseHardwareModule::AudioBlockSize() { return seed.AudioBlockSize(); }

void BaseHardwareModule::SetAudioSampleRate(SaiHandle::Config::SampleRate samplerate) {
    seed.SetAudioSampleRate(samplerate);
    SetHidUpdateRates();
}

float BaseHardwareModule::AudioSampleRate() { return seed.AudioSampleRate(); }

float BaseHardwareModule::AudioCallbackRate() { return seed.AudioCallbackRate(); }

void BaseHardwareModule::StartAdc() { seed.adc.Start(); }

void BaseHardwareModule::StopAdc() { seed.adc.Stop(); }

void BaseHardwareModule::ProcessAnalogControls() {
    if (!knobs.empty()) {
        for (int i = 0; i < GetKnobCount(); i++) {
            knobs[i].Process();
        }
    }
}

void BaseHardwareModule::ProcessDigitalControls() {
    if (!switches.empty()) {
        for (int i = 0; i < GetSwitchCount(); i++) {
            switches[i].Debounce();
        }
    }

    if (!encoders.empty()) {
        for (int i = 0; i < GetEncoderCount(); i++) {
            encoders[i].Debounce();
        }
    }
}

int BaseHardwareModule::GetNumberOfSamplesForTime(float time) { return (int)(AudioSampleRate() * time); }

float BaseHardwareModule::GetTimeForNumberOfSamples(int samples) { return (float)samples / AudioSampleRate(); }

int BaseHardwareModule::GetKnobCount() { return knobs.size(); }

float BaseHardwareModule::GetKnobValue(int knobID) {
    if (!knobs.empty() && knobID >= 0 && knobID < GetKnobCount()) {
        return knobs[knobID].Value();
    }

    return 0.0f;
}

int BaseHardwareModule::GetSwitchCount() { return switches.size(); }

int BaseHardwareModule::GetEncoderCount() { return encoders.size(); }

int BaseHardwareModule::GetLedCount() { return leds.size(); }

int BaseHardwareModule::GetPreferredSwitchIDForSpecialFunctionType(SpecialFunctionType sfType) {
    // If there are no switches return -1 since there can't be a preferred switch ID
    if (GetSwitchCount() == 0 || m_switchMetaDataParamCount == 0 || m_switchMetaData == nullptr) {
        return -1;
    }

    // Look to see if there is a preferred mapping for this special function type
    for (int i = 0; i < m_switchMetaDataParamCount; i++) {
        if (m_switchMetaData[i].sfType == sfType) {
            // Make sure this device has that physical switch
            if (m_switchMetaData[i].switchMapping < GetSwitchCount()) {
                return m_switchMetaData[i].switchMapping;
            }
        }
    }

    // No preffered switch mapping so return -1;
    return -1;
}

void BaseHardwareModule::SetLed(int ledID, float bright) {
    if (!leds.empty() && ledID >= 0 && ledID < GetLedCount()) {
        leds[ledID].Set(bright);
    }
}

void BaseHardwareModule::UpdateLeds() {
    if (!leds.empty()) {
        for (int i = 0; i < GetLedCount(); i++) {
            leds[i].Update();
        }
    }
}

void BaseHardwareModule::SetAudioBypass(bool enabled) {
    m_audioBypass = enabled;
    audioBypassTrigger.Write(!m_audioBypass);
}

void BaseHardwareModule::SetAudioMute(bool enabled) {
    m_audioMute = enabled;
    audioMuteTrigger.Write(m_audioMute);
}

bool BaseHardwareModule::SupportsStereo() { return m_supportsStereo; }

bool BaseHardwareModule::SupportsMidi() { return m_supportsMidi; }

bool BaseHardwareModule::SupportsDisplay() { return m_supportsDisplay; }

bool BaseHardwareModule::SupportsEncoder() { return m_supportsEncoder; }

bool BaseHardwareModule::SupportsTrueBypass() { return m_supportsTrueBypass; }

void BaseHardwareModule::InitKnobs(int count, Pin pins[]) {
    // Set order of ADCs based on CHANNEL NUMBER
    AdcChannelConfig cfg[count];

    // Init with Single Pins
    for (int i = 0; i < count; i++) {
        cfg[i].InitSingle(pins[i]);
    }

    seed.adc.Init(cfg, count);

    // Setup the Knobs
    for (int i = 0; i < count; i++) {
        AnalogControl myKnob;
        myKnob.Init(seed.adc.GetPtr(i), AudioCallbackRate());
        knobs.push_back(myKnob);
    }
}

void BaseHardwareModule::InitSwitches(int count, Pin pins[]) {
    for (int i = 0; i < count; i++) {
        Switch mySwitch;
        mySwitch.Init(pins[i]);
        switches.push_back(mySwitch);
    }
}

void BaseHardwareModule::InitEncoders(int count, Pin pins[][3]) {
    for (int i = 0; i < count; i++) {
        Encoder myEncoder;
        myEncoder.Init(pins[i][0], pins[i][1], pins[i][2]);
        encoders.push_back(myEncoder);
    }

    if (count > 0) {
        m_supportsEncoder = true;
    }
}

void BaseHardwareModule::InitLeds(int count, Pin pins[]) {
    for (int i = 0; i < count; i++) {
        Led newLed;
        newLed.Init(pins[i], false, AudioCallbackRate());
        leds.push_back(newLed);
    }
}

void BaseHardwareModule::InitMidi(Pin rxPin, Pin txPin) {
    MidiUartHandler::Config midi_config;
    midi_config.transport_config.rx = rxPin;
    midi_config.transport_config.tx = txPin;
    midi.Init(midi_config);

    m_supportsMidi = true;
}

void BaseHardwareModule::InitDisplay(Pin dcPin, Pin resetPin) {
    // Configure the Display
    MyOledDisplay::Config disp_cfg;
    disp_cfg.driver_config.transport_config.pin_config.dc = dcPin;
    disp_cfg.driver_config.transport_config.pin_config.reset = resetPin;
    display.Init(disp_cfg);

    m_supportsDisplay = true;
}
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

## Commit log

2023-01-22 Working on documentation
    [Bill_of_Materials_BOM.xlsx]
2023-01-23 Added a drill template to the docs folder
    [DaisySeedPedal1590b.kicad_pcb]
2023-01-31 Updated to KiCad 6.0.11 and updated some 3d models for parts
    [DaisySeedPedal1590b.kicad_pcb]
2023-02-11 Minor updates
    Fixed a few minor updates the BOM and pcb layout. Also updated the code to do a custom tremolo effect
    [Bill_of_Materials_BOM.xlsx, DaisySeedPedal1590b.kicad_pcb]
2023-02-22 First version of 125B sized enclosed pedal
    Submitting a first version of a 125B sized enclosure for the Daisy Seed pedal. This version also primarily uses SMD components for having a manufacturer such as JLCPCB create the PCB and assemble it.
    [Audio_Input_Buffer.kicad_sch, Audio_Output_Buffer.kicad_sch, Audio_True_Bypass_Stereo.kicad_sch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]
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2023-03-08 Updated files to KiCad 7.0
    [Audio_Input_Buffer.kicad_sch, Audio_Output_Buffer.kicad_sch, Audio_True_Bypass_Stereo.kicad_sch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]
2023-03-11 Updated PCB to use 5v power for the relay instead of 9v
    [Audio_True_Bypass_Stereo.kicad_sch, BOM_JLCSMT_DaisySeedGuitarPedal125b.xlsx, DaisySeedPedal125b.kicad_pcb]
2023-03-11 Updating some missing footprints
    [DaisySeedPedal125b.kicad_pcb, DaisySeedPedal125b.kicad_sch, SSD1306_Screen_SPI.kicad_sch]
2023-03-11 Updating missing symbol libraries
    [DaisySeedPedal125b.kicad_pcb, DaisySeedPedal125b.kicad_sch, SSD1306_Screen_SPI.kicad_sch]
2023-03-13 Updated project to KiCad 7
    [Audio_Input_Buffer.kicad_sch, Audio_Output_Buffer.kicad_sch, DaisySeedPedal1590b.kicad_pcb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]
2023-03-13 Added some missing custom symbols and footprints
    [SSD1306_Screen_SPI.kicad_sch]
2023-03-13 Updated resistors on LEDs to be 1K
    Make them a tad dimmer!
    [DaisySeedPedal1590b.kicad_pcb, DaisySeedPedal1590b.kicad_sch]
2023-03-14 KiCad 7 fixes
    Had to update some footprints and symbols to address issues related to ugprading to KiCad 7.0
    [Audio_Input_Buffer.kicad_sch, Audio_Output_Buffer.kicad_sch, DaisySeedPedal1590b.kicad_pcb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]
2023-03-29 Guitar Pedal 1590b Rev 3
    Drastically cleaned up the PCB layout for the 1590B guitar pedal. Updated it to be a 4 Layer board and replaced all SMD parts with through-hole parts. Much easier to build now!
    [Audio_Input_Buffer.kicad_sch, Audio_Output_Buffer.kicad_sch, Bill_of_Materials_BOM.xlsx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]
2023-03-29 125B Guitar Pedal Rev 2
    Updated the 125B Guitar Pedal to fix some issues, upgrade from 3 to 6 knobs and reposition the screen, and make it easier to manufacture with JLCPCB.
    [Audio_Input_Buffer.kicad_sch, Audio_Output_Buffer.kicad_sch, Audio_True_Bypass_Stereo.kicad_sch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]
2023-03-30 Fixed minor issue with power jack footprint
    [DaisySeedPedal125b.kicad_pcb, DaisySeedPedal1590b.kicad_pcb]
2023-04-12 Updated 1590b PCB layout (Rev 4)
    Updated the layout of the PCB to move some of the components a little farther from the edge of the PCB. Also swapped the locations of the LEDs to be more consistent with my other projects. FS1 and LED1 are now the default for enabling and disabling the effect.
    [Audio_Input_Buffer.kicad_sch, Audio_Output_Buffer.kicad_sch, Controls.kicad_sch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]
2023-04-14 Switched LED and FS placement on the 125B pcb layout
    [Audio_Input_Buffer.kicad_sch, Audio_Output_Buffer.kicad_sch, Audio_True_Bypass_Stereo.kicad_sch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]
2023-04-14 Update guitar_pedal_125b_test.cpp
    Updated to match the PCB changes. FS1 and LED1 are now used for effect on / off and LED2 is used for the brightness.
2023-04-14 Updated H11L1 footprint
    [DaisySeedPedal125b.kicad_pcb, Midi_InOut.kicad_sch]
2023-04-14 Added a nice little cross fade when switching the effect on
    To avoid any clicking or popping, I added a simple fast cross fade when turning the effect on / off.
2023-04-15 Update guitar_pedal_1590b_test.cpp
    Re-organized some code. Also made option to enable or disable hardware relay bypass. If disabled, a software bypass is used instead (which is totally silent when switching) due to the cross fade.
2023-04-16 Modified Crossfade to work on Sample time instead of clock time
    Made it so that the crossfade transition happens over a specified number of samples so that it properly adjusts to different samples rates.
2023-05-16 125B Rev 4 PCB
    Updated hardware design for the 125B PCB to include hardware muting. This allows the signal to be muted during true bypass relay switching, which reduces any popping that might happen otherwise.
    Updated the example software to use the hardware mute when using the bypass. Also, added basic menu support to the OLED screen with some settings for the Tremolo and hardware device.
    [Audio_Input_Buffer.kicad_sch, Audio_Output_Buffer.kicad_sch, Audio_True_Bypass_Stereo.kicad_sch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]
2023-05-23 Minor updates to PCB
    [DaisySeedPedal1590b.kicad_pcb]
2023-06-03 Updated 1590B PCB and software
    Updated the PCB to properly ground the inputs and outputs when no plug is inserted in the jack. Fixed a noise issue caused by having the LED update function in the main loop instead of the audio callback.
    [Audio_Input_Buffer.kicad_sch, Audio_Output_Buffer.kicad_sch, Controls.kicad_sch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]
2023-06-03 Updated 125b code to fix LED update issue
2023-06-04 Added JLCPCB Gerber files for easy manufacturing
    [DaisySeedPedal1590b.kicad_pcb]
2023-06-04 Update README.md
    Added some details on the parts not assembled by JLCPCB that are needed in order to complete assembly yourself.
2023-06-30 125B Rev 5
    Minor updates. Adjusted screen placement slightly to ease assembly. Also grounded TRS jacks better when plug isn't in place. Adjusted pot footprint mounting holes to be slightly larger to ease instal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
    [Audio_Input_Buffer.kicad_sch, Audio_Output_Buffer.kicad_sch, Audio_True_Bypass_Stereo.kicad_sch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]
2023-07-17 Uploaded Gerber files and updated instructions to order PCBs.
    [DaisySeedPedal125b.kicad_pcb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]
2023-09-16 Update guitar_pedal_125b_test.cpp
    Added ability to split mono input into stereo before the effects are processed. This feature is only available when relay bypass is not in use.
2023-09-17 Update guitar_pedal_125b_test.cpp
    Added a nice crossfade between effect on / off when not using the relay bypass.
2023-09-23 Started refactoring code to separate the effect from the pedal controls
    Created a new abstract base_effect_module class that different effects can inherit from. that way effects can be their own self contained units of code that the pedal can switch between.
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2023-09-27 Effect Swapping through Setting UI
    You can now switch the active effect by changes the Effect under the settings menu. Allows you to switch between the sample Tremolo and Overdrive.
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2023-10-02 Reorganization Part 2
    Moved all of the Hardware projects into a sub folder.
    [Audio_Input_Buffer.kicad_sch, Audio_Output_Buffer.kicad_sch, Audio_True_Bypass_Stereo.kicad_sch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]
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2023-10-07 Refactoring the setup of knobs, leds, etc to be dynamic instead of fixed.
    [base_hardware_module.cpp, guitar_pedal.cpp]
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2023-10-10 Update guitar_pedal.cpp
    Fixed an issue where the knob monitoring was not properly waiting for the pots to settle before starting to accept knob changes.
    [guitar_pedal.cpp]
2023-11-03 Added Guitar Pedal 1590B SMD Project
    [Audio_Input_Buffer.kicad_sch, Audio_Output_Buffer.kicad_sch, Audio_True_Bypass_Stereo.kicad_sch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]
2023-11-04 Updated BOM and Readme for CPC1018 part
    JLCPCB has now started stocking the CPC1018 part regularly, so it's no longer a part that needs to be special ordered. I've updated the BOM and Readme for the 125B and the 1590B-SMD projects to accurately reflect that. This is good!
    [BOM_JLCSMT_DaisySeedGuitarPedal125b.xlsx, BOM_JLCSMT_DaisySeedGuitarPedal1590b-SMD.xlsx]
2023-11-13 Updated 1590b Schematic Rev 6
    * Added a DNP SMD Resistor pad to optionally bypass the PDS1 isolated power components.
    [Audio_Input_Buffer.kicad_sch, Audio_Output_Buffer.kicad_sch, Bill_of_Materials_BOM.xlsx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]
2023-11-23 Fixing bugs and allowed Effects modules to control more than 1 LED
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2023-11-30 Update DaisySeedPedal125b-top-pos.csv
    Remove A1 from the CPL as it's not a part being assembled and was causing an error with JLCPCB
    [DaisySeedPedal125b-top-pos.csv]
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2023-12-10 Added additional error handling when loading data from storage
    Checked to make sure the active effect from storage is within range of active effects currently loaded.
    [guitar_pedal.cpp]
2024-02-09 1) Adding Reset All function button in Preset Menu, 2) Changing Midi to call custom callback when a midi cc cannot be found, 3) Added the Multi tap delay
    [guitar_pedal.cpp]
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2024-03-17 Hardware Rev 6
    * Removed PDS1 to reduce cost and because it wasn't really helping anything
    * Added low pass filter to address Rev7 Seed Noise issue
    * Modified schematics and footprints to make it easier to have assembled by JLCPCB
    [Audio_Input_Buffer.kicad_sch, Audio_Output_Buffer.kicad_sch, Audio_True_Bypass_Stereo.kicad_sch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]
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2024-10-26 Make UI feel even smoother, fix freq printout without adding float formatting yet
2024-10-27 Fix float printing in commented out code
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2024-11-02 Simplify filter since the sample rate doesn't get used once we set timestamps anyways
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2024-11-04 Oops, fix wrong rollover
    [guitar_pedal.cpp]
2024-11-05 Fix tap tempo that I broke
    [guitar_pedal.cpp]
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2024-11-05 Revert moving pitch shifter to SDRAM
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2024-12-27 Update guitar_pedal.cpp
    Fixed issue where saving presets also triggered auto switching to the tuner
    [guitar_pedal.cpp]
2024-12-28 Fixed Issue #43
    Fixed issue #43 Saving Presets doesn't survive power off. Fix is not ideal, but gets things back to working.
2024-12-29 Fixed Midi CC Handling
    [guitar_pedal.cpp]
2024-12-31 Minor fix to para eq param count
2025-01-02 Modernize and prevent implicit int conversion by switching from NULL to nullptr
    [base_hardware_module.cpp, guitar_pedal.cpp]
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2025-01-04 Properly skip the tuner when cycling through with no screen
    [guitar_pedal.cpp]
2025-01-12 Noise gate (#50)
    Noise gate with quite a few tweakable settings.
    I set the defaults to what work best for me/my setup.
    - Fast attack of 1ms
    - Hold and release both of 50ms
    - Fade time of ~100-200ms
    - And then threshold somewhere in the middle
    [guitar_pedal.cpp]
2025-01-14 Fixed delay led, moved stft code, updated ci, readme
    [guitar_pedal.cpp]
2025-01-15 Fix 2 warnings from static analysis
    [delay_module.h]
2025-03-14 Added more beats, time signatures, auto always on feature, fixed led tempo
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2025-05-19 Fix ARM GCC version check to be cross-platform
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2025-10-26 Added 3D printable enclosure
    [daisy-enclosure-bottom.step, daisy-enclosure-top.step, daisy-enclosure.FCStd]
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2026-09-02 Add the Dattorro plate reverb (#102)
    * Configure local build support: add .gcc_path to gitignore and local GCC toolchain setup
    * Initial set of changes, merged from MuleBox and Flick
    * Enable temporarily
    * Better indicator for defaults reset
    * Fix toolchain issue that broke LEDs (huh)
    * Try different approach for defaults reset
    * Update docs
    * Correctly comment out by default
2026-09-27 Fix the encoder wheel direction when browsing through effects whilst holding secondary footswitch (#108)
    * Fix the direction of the encoder wheel when moving through effects whilst holding the alt footswitch
    [guitar_pedal.cpp]
2026-10-10 Midi support for preset switching (#109)
    * Initial cut at MIDI preset management
    * Make bank select be the preset selector, to avoid breaking old behaviour
2026-10-27 Fix led init (#113)
    * Fix LEDs not working with GCC 13: zero-initialise Led before Init
    libDaisy's Led::Init() never initialises the software-PWM phase (pwm_) and Led's
    constructor does nothing, so an Led created on the stack starts with leftover stack
    contents. Depending on the compiler and optimiser that can be huge or NaN, which
    keeps the LED permanently off (or on); the update does `pwm_ += rate; if (pwm_ > 1)
    pwm_ -= 1`, so a large value never comes back into range.
    InitLeds now zeroes the object before calling Init(). Verified on hardware with
    arm-none-eabi-gcc 13.3, where the LEDs did not work before. This is an upstream
    libDaisy bug; libDaisy is a submodule so the workaround lives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
